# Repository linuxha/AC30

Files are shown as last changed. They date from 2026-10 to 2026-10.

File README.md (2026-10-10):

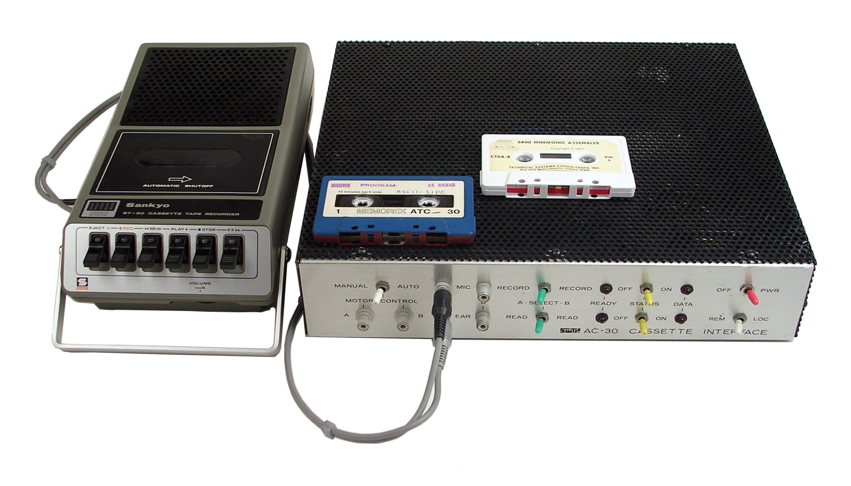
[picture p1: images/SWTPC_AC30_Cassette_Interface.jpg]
SWTPC AC30 Cassette Interface


# SWTPC AC30 Reproduction
A reproduction SWTPC AC-30 Cassette Interface

## Description

I have a couple of Motorola MC6800, MC6802, and MC6809 machines from the 1970's. And I wanted to
setup a typical cassette plater/recorder setup to save and load code written on these machines.

**Note:**2026/10/10 - Both boards (through-hole `kicad/AC30` and SMT `kicad-smt/AC30_SMT`) now wire the front panel (switches, LEDs, motor jacks, MIC A/B and EAR A/B jacks) to labelled through-hole wire pads instead of the J1/J2 Molex connectors. Board details are in [AC30-settings.md](AC30-settings.md) and [AC30-SMT-settings.md](AC30-SMT-settings.md); the parts list is [docs/AC30-BOM.md](docs/AC30-BOM.md), with KiCad BOMs in `kicad/AC30-BOM.csv` and `kicad-smt/AC30_SMT-BOM.csv`.

Board sizes are now 173.0 x 126.5 mm (6.8" x 5.0") through-hole and 173.0 x 88.5 mm (6.8" x 3.5") SMT. Gerbers and drill files for both boards are ready for the board house: [kicad/AC30-gerbers.zip](kicad/AC30-gerbers.zip) (through-hole) and [kicad-smt/AC30_SMT-gerbers.zip](kicad-smt/AC30_SMT-gerbers.zip) (SMT, including the top paste layer for a stencil). `kicad/tools/build.sh` regenerates them on every build, or run `kicad/tools/gerbers.sh` (add `smt` for the SMT board).

The SMT board also has a pick-and-place position file, [kicad-smt/AC30_SMT-top-pos.csv](kicad-smt/AC30_SMT-top-pos.csv) (SMD parts only, mm, origin at the board's bottom-left corner), to go with the BOM for an assembly house. The through-hole board's layout was re-placed so a fresh build routes completely again; the build now tries other placements automatically if routing ever comes up short. Both boards now have a GND copper fill on both layers (thermal reliefs on the GND pads, so they're still easy to hand-solder; details in the settings files above), added automatically by the build after routing. The motor and relay lines (MOTOR_1A/1B/2A/2B, RELAY_1/2) now use the same 0.6 mm tracks as the power rails, good for roughly 1.5 A. Known issues, including what to check before ordering boards, are listed in [KNOWN-ISSUES.md](KNOWN-ISSUES.md).

2026/10/09 - I've update the PCB to add the mod/demod circuits and a molex for the power. Additionally I had a new SMT version created.

2026/10/08 - This is my first go around with Claude, Kicad and FreeCAD and creating a PCB to be sent off as gerbers. I have a lot of inspecting to do. But for a 1st go this is scary impressive.

## Claude created Kicad files

I gave Claude the following prompts:

```text
Create a kicad schematic for docs/AC30-BOM.md docs/ac30_schematica.jpg
```

and

```text
Save what you have but provide solder pads and labels for the missing power and mod/demod
```

and

```text
Now create the pcb from the schematics. Minimize the board size but leave a safe boarder along the edge.
```

After this I use a few suggested prompts.

Here's what the inside of the Original SWTPC AC30:

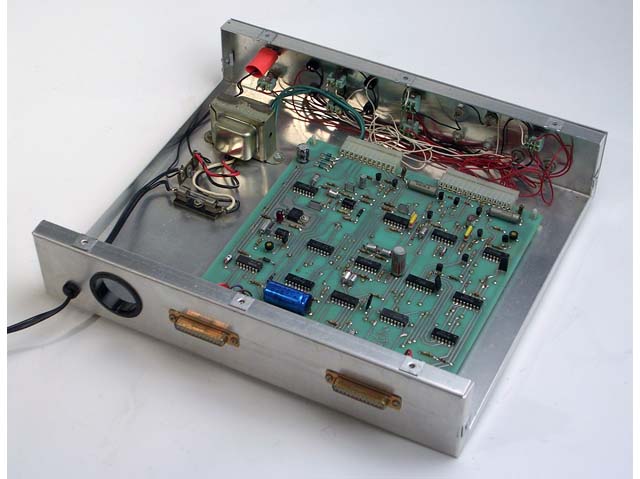
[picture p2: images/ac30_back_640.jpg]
SWTPC AC30 Cassette Interface insides


I'd estimate the board to be about 9" x 9" (inches) in size. Here's the schematics I gave Claude:

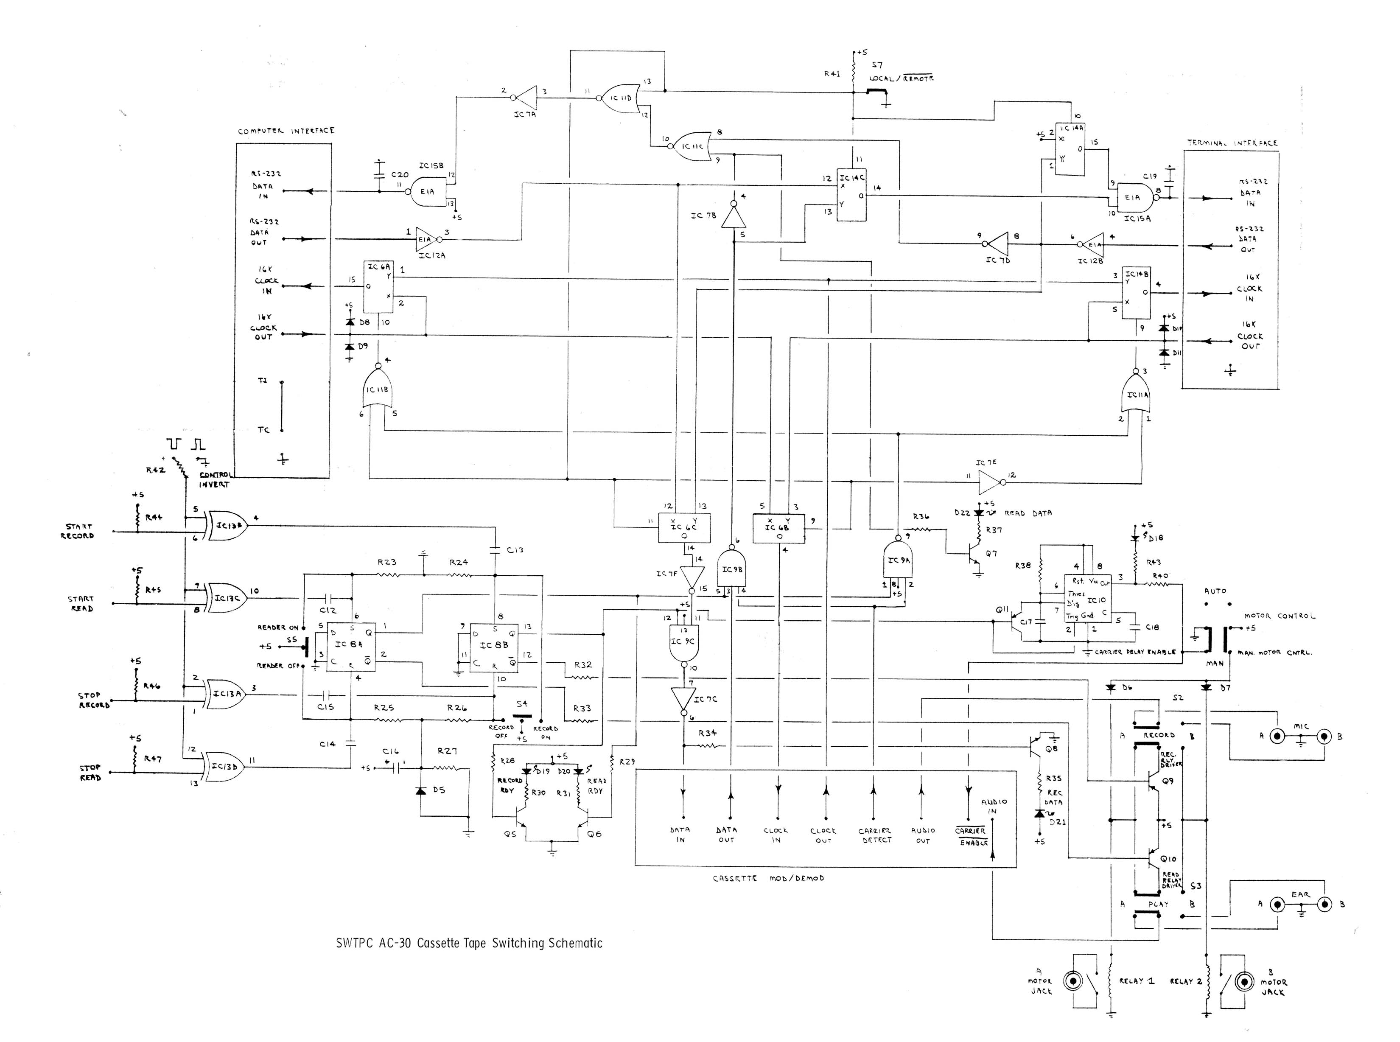
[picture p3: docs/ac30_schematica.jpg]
SWTPC AC30 Cassette Interface schematic


I gave it the [AC30/docs/AC30-BOM.md](BOM) file (simple markdown text file).

Claude started churning and created a 'schematic' (doesn't look like the above, hard to read) and I imported it into the PCB editor. Then didn't make any changes. Instead I let Claude do the rerouting.

I then found out I needed to upgrade Kicad to 10.7 and FreeCAD 26.3 so Claude could create Python 3.11 scripts to build a schematic, the PCB and routing. That was messy as I have Debian Trixie and the latest wants Debian Forky. Anyway, this is the final 1st round attempt. More cleanup to do yet before I ship off the gerbers.

I'd estimate the size of the new PCB to be about 3.5" x 7" (inches).

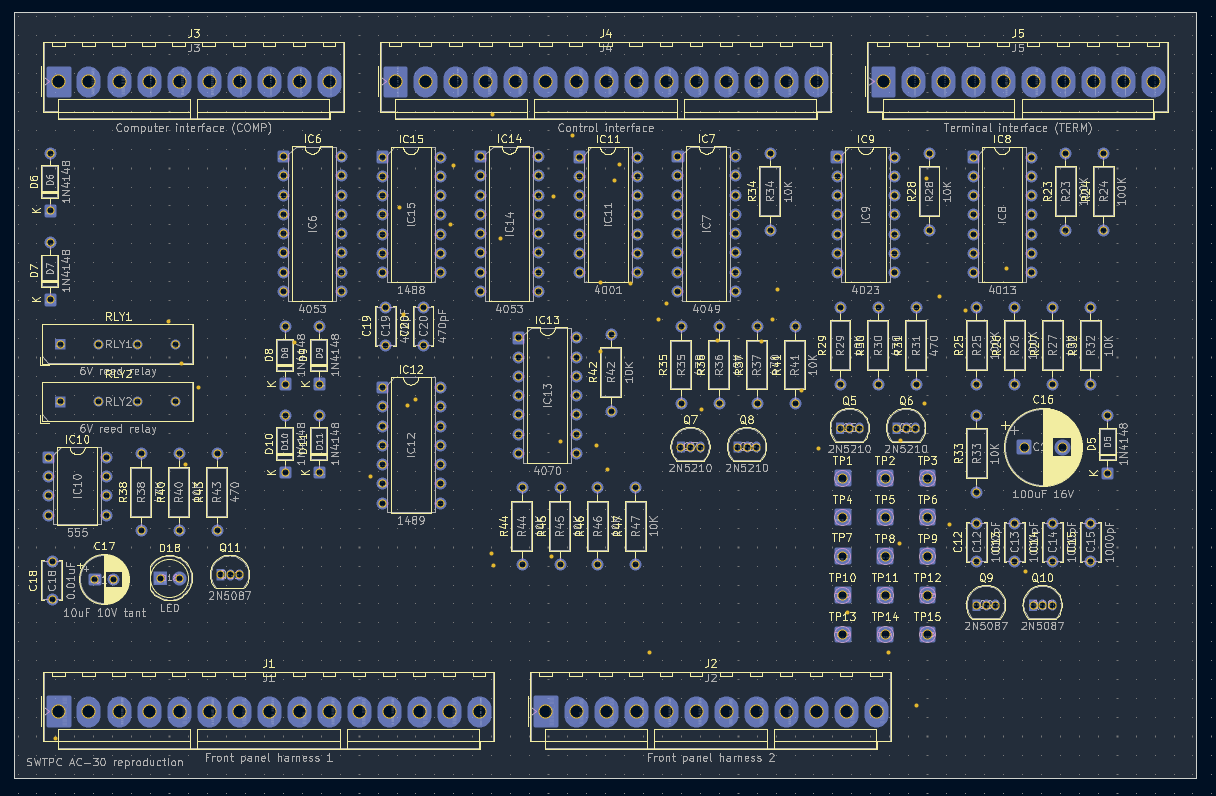
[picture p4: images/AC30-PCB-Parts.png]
New AC30 Cassette Interface part placement


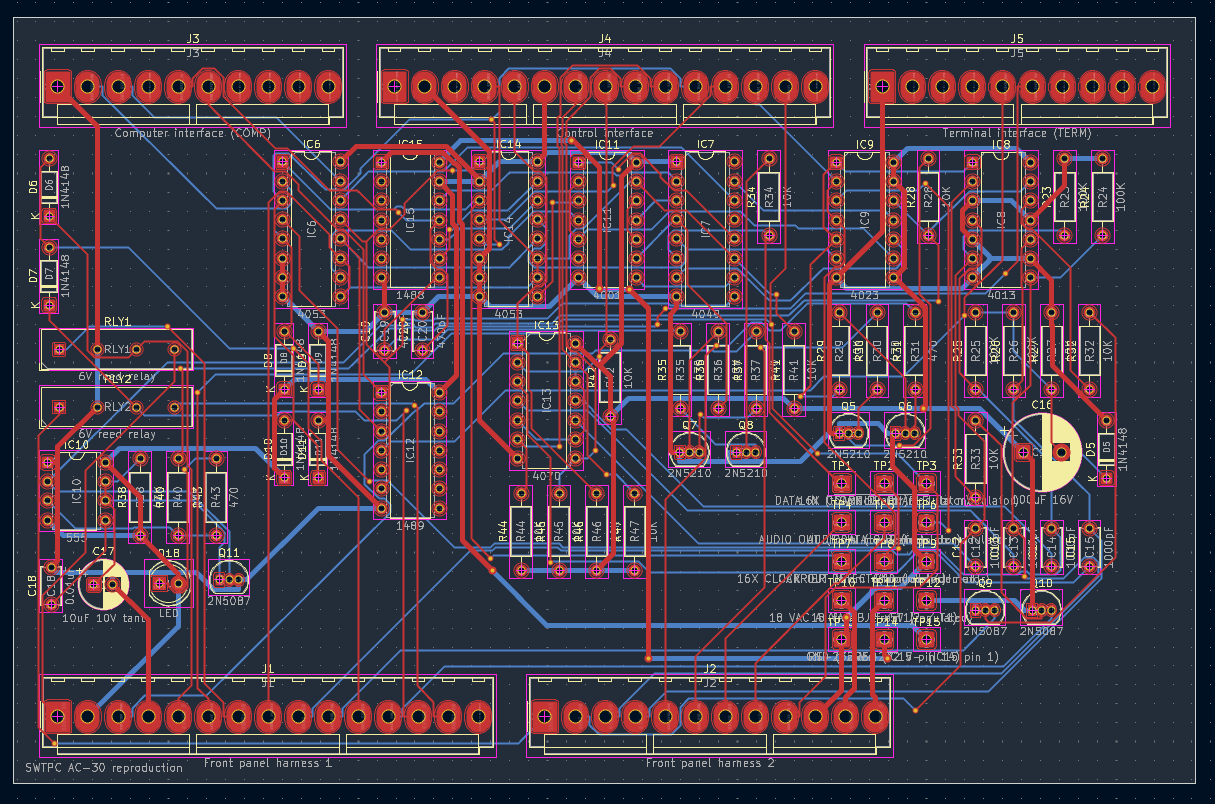
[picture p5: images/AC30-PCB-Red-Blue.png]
New AC30 Cassette Interface Red/Blue


So after several hours, including the Kicad/FreeCAD SNAFU, those are the results. The TPx are where I just dumped a bunch of jumpers I hadn't decided on. I'll fix those later. While it's not done it's a huge jump. It would have taken me about two weeks to get all the parts on the schematic, connections defined and PCB routed.

## Credits

I stole this from [Deramp's AC30 (Mike)](https://www.swtpc.com/mholley/ac30/ac30_index.html) site.
And he saved it from Mike Holley's original SWTPC site.

## Links

- [Deramp's AC30 page](https://www.swtpc.com/mholley/ac30/ac30_index.html)

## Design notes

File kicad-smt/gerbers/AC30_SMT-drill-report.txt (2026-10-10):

Drill report for AC30_SMT.kicad_pcb
Created on 2026-10-10T07:04:19

Copper Layer Stackup:
    =============================================================
    L1 :  F.Cu                      front
    L2 :  B.Cu                      back

Drill file 'AC30_SMT-PTH.drl' contains
    plated through holes:
    =============================================================
    T1  0.400mm  0.0157"  (252 holes))
    T2  0.500mm  0.0197"  (28 holes))
    T3  1.000mm  0.0394"  (36 holes))
    T4  1.700mm  0.0669"  (41 holes))

    Total plated holes count 357

Drill file 'AC30_SMT-NPTH.drl' contains
    unplated through holes:
    =============================================================
    T1  3.200mm  0.1260"  (4 holes))

    Total unplated holes count 4

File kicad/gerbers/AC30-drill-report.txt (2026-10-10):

Drill report for AC30.kicad_pcb
Created on 2026-10-10T07:02:01

Copper Layer Stackup:
    =============================================================
    L1 :  F.Cu                      front
    L2 :  B.Cu                      back

Drill file 'AC30-PTH.drl' contains
    plated through holes:
    =============================================================
    T1  0.400mm  0.0157"  (82 holes))
    T2  0.500mm  0.0197"  (7 holes))
    T3  0.700mm  0.0276"  (8 holes))
    T4  0.750mm  0.0295"  (33 holes))
    T5  0.800mm  0.0315"  (363 holes))
    T6  0.900mm  0.0354"  (2 holes))
    T7  1.000mm  0.0394"  (38 holes))
    T8  1.700mm  0.0669"  (41 holes))

    Total plated holes count 574

Drill file 'AC30-NPTH.drl' contains
    unplated through holes:
    =============================================================
    T1  3.200mm  0.1260"  (4 holes))

    Total unplated holes count 4

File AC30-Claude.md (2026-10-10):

# AC-30 KiCad Schematic: Claude Code Session Log

Session dates: 2026-10-08 to 2026-10-10 (sections 1–16 on the 8th, 17–42 on the 9th, 43–70 on the 10th). Model: Claude Opus 5.5 (Claude Code CLI).

This is a record of the chat that produced the KiCad project in `kicad/`. User messages are reproduced exactly, typos included. Claude's answers are in full for sections 1–3 and condensed from section 4 on. Claude's intermediate tool work (shell commands, image crops, file edits) is summarized rather than shown verbatim.

---

## 1. User

> Create a kicad schematic for docs/AC30-BOM.md docs/ac30_schematica.jpg

### Work done (summary)

1. **Read the inputs.** Claude read `docs/AC30-BOM.md`, the "How It Works" section of `docs/AC30-AssemblyInstruction.md` and `docs/ac30_schematica.jpg` (3300×2456). The image is titled *SWTPC AC-30 Cassette Tape Switching Schematic* and shows only the switching circuitry. The modulator/demodulator appears only as a block, and the power supply is not drawn.
2. **Traced the drawing.** Claude cropped and zoomed about 25 regions of the image with ImageMagick and traced every net by hand. It treated gaps in a line as crossings and dots as junctions. Gate pin numbers were checked against the real CMOS pinouts (4001, 4013, 4023, 4049, 4053, 4070, 555, 1488, 1489).
3. **Read the board connectors.** From `docs/ac30_wiring1a.jpg`, Claude took the signal order of board connectors J1–J5 and the front-panel parts (S1–S7, D19–D22, jacks J6–J11).
4. **Wrote a generator.** The tooling lives in `kicad/tools/`:
   - `sexp.py`: a minimal S-expression parser/writer.
   - `kilib.py`: loads stock KiCad library symbols, flattens `extends`, and reports pins and body bounding boxes.
   - `customlib.py`: writes `AC30.kicad_sym` with the MC1488, MC1489 and SPST reed relay symbols, which are missing from the stock libraries.
   - `netlist.py`: the hand-transcribed netlist. Each part has its value, footprint and a per-unit pin→net map.
   - `gen.py`: places each unit in grouped rows. Every pin gets a short wire stub ending in a net label, a power symbol or a no-connect flag. It writes the root and sub sheets, `sym-lib-table` and `AC30.kicad_pro`.
5. **Verified the result.**
   - `kicad-cli sch upgrade` converted the files to the KiCad 10 format.
   - `kicad-cli sch erc` was run on the result.
   - A netlist exported with `kicad-cli sch export netlist` was compared pin for pin against `netlist.py`. This caught one real error: the drawing labels IC13C's inputs as 7/8, but 4070 pin 7 is VSS. It was fixed to 8/9.
   - A PDF render was inspected, and the Ref/Value field placement and power-symbol text collisions were fixed.
   - A check confirmed that every BOM designator appears exactly once.

### Claude's answer

I've created a KiCad 10 project in `kicad/`. One big caveat first: the image only contains the **switching** circuit, so that's the only part that's actually wired. The modulator/demodulator and power supply aren't drawn anywhere in `docs/`, so those parts are placed but have no connections.

**What's in it**
- **`AC30.kicad_sch` (sheet 1, A1): the switching circuit, fully wired.** It covers IC6–IC15, Q5–Q11, the latches, power-on reset, LED and relay drivers, the 555 carrier-enable delay, the RS-232 parts and the front-panel switches, LEDs and jacks.
- **Board connectors J1–J5.** I took their signal lists from `docs/ac30_wiring1a.jpg`.
- **`AC30_moddemod_power.kicad_sch` (sheet 2): the rest of the BOM, unwired.** That's IC1–IC5, IC16, R1–R22, C1–C11, T1, F1 and so on. The only connections are the obvious ones: CMOS supply pins and the 7805 output. A note on the sheet summarizes the theory-of-operation text to help with wiring it later.
- **`AC30.kicad_sym`:** custom symbols for the MC1488, MC1489 and the reed relay, which aren't in the stock KiCad libraries.
- **`tools/`:** the generator scripts. The transcribed netlist is in `tools/netlist.py`, and `python3 -I tools/gen.py .` rebuilds the files.

**Layout:** this is not a redraw of the original drawing. Each pin has a short wire ending in a net label, and parts are grouped by function. Connections are exact, but you read it like a netlist rather than tracing wires.

**Checks I ran**
- Every BOM designator appears exactly once. J1–J11 are extra, since they're on the drawings but not in the BOM.
- The netlist exported from KiCad matches my transcription pin for pin.
- ERC shows no problems on sheet 1 except nets that lead to the unwired sheet 2. Sheet 2 reports about 180 unconnected pins, which is expected.
- It opens and plots in KiCad 10.0.4.

**Things to check, since I read them off a scanned drawing (also noted on the sheet):**
- **Two pin-number errors on the drawing.** I corrected them to the real chip pinouts:
  - IC7D is labelled 8→9; on a 4049 that section is 9→10.
  - IC13C's inputs are labelled 7 and 8; on a 4070 they're 8 and 9, and pin 7 is ground.
- **Assumed, not shown on the drawing:**
  - The 4053 INH and VEE pins are tied to ground.
  - The 555's pins 4 and 8 go to +5V.
  - The 1488's supply pins are brought out as `V_RS232+` and `V_RS232-`, with the source unknown.
- **Pin numbers on J1–J5** follow the order on the wiring diagram and haven't been checked against a real board.
- **MIC/EAR jacks:** I assigned J6–J9 arbitrarily; J10 and J11 are the motor jacks.
- **Switch S6** isn't on the switching schematic, so I left it unwired on sheet 2.
- **R39 (200K trim)** isn't on the drawing either; it may belong in the 555 timing circuit. It's on sheet 2 for now.

Nothing is committed yet. If you can find the mod/demod and power supply schematic, I can wire sheet 2 the same way.

---

## 2. User

> Save what you have but provide solder pads and labels for the missing power and mod/demod

### Work done (summary)

1. **Saved the current state.** Claude created branch `kicad-schematic` and committed the project as it stood (`5476760`).
2. **Replaced the unwired parts with pads.** In `netlist.py`, the unwired mod/demod and power BOM parts were moved to sheet `'omitted'`, so they are kept for reference but not placed. Fifteen `Connector:TestPoint` solder pads (TP1–TP15) were added on sheet 2, using footprint `Connector_Wire:SolderWire-0.5sqmm_1x01_D0.9mm_OD2.1mm`.
3. **Fixed power flags.** PWR_FLAGs went on +5V, GND, V_RS232+ and V_RS232−, because the supplies now enter through pads.
4. **Verified and committed.** ERC exited with 0 violations. Claude regenerated, rendered and checked sheet 2, then committed (`ab95554`).

### Claude's answer

Both changes are committed on a new branch, `kicad-schematic`. I branched instead of committing to `main`, and nothing is pushed. Your edit to `README.md` is still uncommitted.

**Commits**
1. `5476760`: the schematic as it was, with the mod/demod and power parts placed but unwired.
2. `ab95554`: sheet 2 is now **Mod/Demod & Power pads**. Each signal or supply that crosses into the missing circuits goes to its own labelled solder pad, using a 0.9 mm drill / 2.1 mm wire pad footprint:

| Pad | Net | Direction |
|---|---|---|
| TP1 | DATA_IN | to modulator |
| TP2 | CLOCK_IN (16X) | to modulator |
| TP3 | CARRIER_EN_N | to modulator |
| TP4 | AUDIO_OUT | from modulator |
| TP5 | AUDIO_IN | to demodulator |
| TP6 | DATA_OUT | from demodulator |
| TP7 | CLOCK_OUT (16X) | from demodulator |
| TP8 | CARRIER_DETECT | from demodulator |
| TP9 | GND | mod/demod ground |
| TP10, TP11 | 18VAC_A, 18VAC_B | from J2 / T1 |
| TP12 | +5V | regulated supply in |
| TP13 | GND | power ground |
| TP14, TP15 | V_RS232+, V_RS232− | 1488 supply rails (pins 14 and 1) |

**Other changes**
- **Mod/demod and power BOM parts:** IC1–IC5, IC16, R1–R22, T1, F1 and the rest are no longer on the schematic. Unwired parts would just turn into dead footprints on a PCB. They're still listed in `kicad/tools/netlist.py`; changing `S = 'omitted'` back to `'moddemod'` there and rerunning `gen.py` places them again.
- **Unknown parts:** S6 and R39 went off the schematic with that group, since their function wasn't shown.
- **ERC is now completely clean.** It reports no violations, including none for unconnected pins. Since nothing on the board drives +5V, GND or the RS-232 rails any more, I added PWR_FLAGs to those nets.

The open questions from last time haven't changed:
- the J1–J5 pin order
- which of J6–J9 is which MIC/EAR jack
- the two pin-number slips I corrected on the original drawing (IC7D and IC13C)
- the 1488's supply voltages

---

## 3. User

> Save this entire chat to AC30-Claude.md

### Claude's answer

Saved to `AC30-Claude.md` in the repository root (this file).

---

## 4. User

> Now create the pcb from the schematics. Minimize the board size but leave a safe boarder along the edge.

### Work done (summary)

1. **Writing the board file directly.** The `pcbnew` Python module on the system was broken: SWIG type errors, then a segfault. Claude wrote `kicad/tools/pcb.py`, which builds `AC30.kicad_pcb` straight from KiCad's exported netlist as S-expression text. Each footprint carries `path`/`sheetname`/`sheetfile`, so the schematic–PCB parity check passes.
2. **Placement.**
   - Each discrete part joins the IC it shares the most signal nets with, and parts stand upright to save area.
   - Each cluster picks the internal width that gives it the smallest area.
   - Clusters are packed with a skyline packer, trying several block orders.
   - J3–J5 run along the top edge and J1/J2 along the bottom.
3. **Outline and rules.** The outline is a rectangle with a **3 mm border** around the outermost courtyards, snapped to 0.5 mm. A Power net class was set: 0.6 mm tracks for +5V, GND and the supply nets, against 0.25 mm and 0.2 mm clearance for the Default class. Copper-to-edge clearance is 0.5 mm.
4. **Routing question.** The FreeRouting jar already on the machine is an old GUI-only build. Claude asked how to route. The user chose **"Leave unrouted for now"**.

### Claude's answer (condensed)

The board was placed and outlined at **115.5 × 122 mm** with 80 footprints, but not routed. DRC showed no placement errors and 0 parity issues; the only items flagged were 212 unrouted connections. Nothing was committed. Claude also noted that this overwrote the raw-import board the user had committed in `60d7180`, and gave the command to restore it.

---

## 5. User

> Make J3, J4 and J5 match the original artwork

### Work done (summary)

Claude read the connector labels on `docs/ac30_redblue150.jpg`, the original board artwork, top view:
- J3 (COMP) and J5 (TERM) are 10-position headers and J4 is a 15-position header, Molex KK-396 at 3.96 mm pitch.
- Each signal was moved to its pad position on the artwork, with unused positions marked no-connect.

### Claude's answer (condensed)

- **J3:** 1 GND, 2 computer 16X clock out, 3 computer 16X clock in, 5 RS-232 in, 6 RS-232 out.
- **J4:** 2 GND, 4 LOCAL/REMOTE, 5 STOP RECORD, 6 +5, 7 STOP READ, 8 CONTROL INVERT, 9 START READ, 10 START RECORD, 11 terminal 16X clock out, 12 terminal clock in, 13 CARRIER DETECT, 14 CARRIER DELAY ENABLE.
- **J5:** 1 GND, 5 terminal RS-232 out, 6 terminal RS-232 in.

The wider top row reflowed the board to **156 × 98 mm**. ERC and parity were clean, and the board was still unrouted.

---

## 6. User

> Check J1 and J2 against the artwork too

### Claude's answer (condensed)

J2's 12 positions already matched the artwork. J1 has **15 pads** on the artwork, and only the first 14 are labelled, in the same order as the schematic. J1 became a 1×15 header with pin 15 unused.

During this check Claude found that `kicad 9.0.2` had been installed in place of 10.0.4 during the session. KiCad 9 had no global symbol library table, so ERC produced 206 "library not found" warnings. With a temporary library config, ERC was clean.

---

## 7. User

> Use /home/njc/bin/FreeCAD_26.3rc1-Linux-aarch64.AppImage and /home/njc/bin/kicad.AppImage instead

### Work done (summary)

- **FreeCAD:** the FreeCAD AppImage is an **aarch64** build and the machine is x86_64, so it can't run.
- **KiCad:** the KiCad AppImage is **10.0.7**. Its `AppRun` passes a tool name through, so `kicad.AppImage kicad-cli …` works, and the image bundles its own libraries.
- **Library layout:** KiCad 10 stores each stock symbol library as a `.kicad_symdir` folder, one file per symbol. Claude taught `kilib.py` to read that layout and made the library paths overridable (`KICAD_SYMBOL_DIR`, `KICAD_FOOTPRINT_DIR`).
- **New `tools/build.sh`:** mounts the AppImage for the whole run, so the generators read its KiCad 10 libraries. It runs `kicad-cli` with a private config pointing at the AppImage's own library tables. It then regenerates the schematic and board and runs ERC and DRC with the parity check.
- **Sub-sheet format:** `sch upgrade` only rewrites the root sheet, so the sub-sheet is now upgraded explicitly too.

### Claude's answer (condensed)

The project builds and checks with KiCad 10.0.7, and the files are back in KiCad 10 format. ERC was clean, and DRC showed 0 violations and 0 parity issues besides the 212 unrouted connections. Claude noted that the user's `~/.config/kicad/10.0` tables now point at the Debian 9 template, so the KiCad 10 GUI would not find the stock symbols. The config was left unchanged.

---

## 8. User

> Use /home/njc/bin/FreeCAD_26.3rc1-Linux-x86_64.AppImag

### Claude's answer (condensed)

The path was missing its final "e". The x86_64 AppImage wasn't executable, so Claude ran `chmod +x` on it. It reports **FreeCAD 26.3.0** and runs headless as `freecadcmd`.

A STEP export from KiCad loaded cleanly in FreeCAD, with 136 solids. The PCB body measured **156.0 × 101.0 × 1.51 mm**, matching the outline. The KK-396 connectors and the solder-wire pads have no 3D models in the KiCad library.

---

## 9. User

> Add the STEP export and FreeCAD check to build.sh

### Claude's answer (condensed)

- `build.sh` now writes `kicad/AC30.step` and lists the parts with no 3D model.
- It then runs `tools/fc_check.py` in headless FreeCAD. The check confirms one assembly with a PCB body whose size matches the board outline, and fails the build if it doesn't.
- `freecadcmd` doesn't pass script arguments through or show printed output, so the script takes its input and output paths from environment variables.

---

## 10. User

> Add AC30.step to .gitignore and commit

### Claude's answer (condensed)

Claude created the root `.gitignore` and committed the PCB work as **`0bced8b`** on `kicad-schematic`. It left out KiCad's local `.history/` folder.

---

## 11. User

> Add .history to .gitignore too

### Claude's answer (condensed)

Claude added `.history/` to `.gitignore` and left the change uncommitted.

---

## 12. User

> Run ERC

### Claude's answer (condensed)

ERC with the KiCad 10.0.7 AppImage: **0 errors and 0 warnings** on both sheets. The four ignored checks listed in the report are KiCad's defaults.

---

## 13. User

> Run DRC

### Claude's answer (condensed)

DRC: **0 violations and 0 parity issues**. The 212 unrouted connections remained.

---

## 14. User

> Do routing

### Work done (summary)

1. **Getting a working router.**
   - FreeRouting 2.5.0 and 2.4.1 both need Java 25, and the machine has Java 22. Claude deleted the jars it had downloaded.
   - **FreeRouting 2.1.0** (April 2025, Java 21) went to `~/bin`. It routes headless (`-de … -do … -mp 100 --gui.enabled=false`).
   - The KiCad AppImage's bundled Python 3.11 has a working `pcbnew`, which does the Specctra DSN export and SES import.
2. **Layer fix.** The PCB header copied from the KiCad demo marked F.Cu as a *power* layer, which stopped FreeRouting from routing on it. Both copper layers became signal layers.
3. **Placement fix.** On the first route, three nets could not be completed: C12–C15 sat about 110 mm from IC13. Claude made the skyline packer **wirelength-aware**:
   - each block goes to the column that minimizes height plus the wire it adds;
   - 300 random block orders are tried;
   - the score weighs 25 mm of wire against 1 mm of board height.
   The board grew to 156 × 101 mm, and the estimated signal wire fell by about 16%.
4. **New `tools/route.py`.**
   - It exports the DSN, runs FreeRouting and imports the SES.
   - It removes the duplicate and dead-end stubs FreeRouting leaves behind; those had caused "track has unconnected end" warnings.
   - It repeats while anything is unrouted.
   - `build.sh` runs it after placement; `ROUTE=0` skips routing.
5. **Build-script fix.** The exit trap failed under `set -e` when the AppImage mount had already gone; Claude fixed it.

### Claude's answer (condensed)

**Fully routed: 0 unrouted connections, 0 DRC violations and 0 parity issues.** The routing had 1,085 segments and 50 vias, with 0.6 mm tracks on the power nets. Routing changes on every build. Nothing was committed.

---

## 15. User

> Create an AC30-settings.md file with all the settings, drill bits, trace minimus, measurements, etc.

### Claude's answer (condensed)

Claude created `AC30-settings.md`, with every value read from the board using KiCad's own tools. It covers:
- board size and stackup;
- DRC rules in mm and mils;
- net classes;
- a drill table: each hole size with its inch and number-drill equivalents, hole counts, and which parts use it;
- annular rings;
- routing figures;
- connector positions;
- a pin-1 placement table for every part;
- tool versions and generator settings.

It flagged that the board had no mounting holes and no ground fill.

---

## 16. User

> Add the four corner mounting holes to match the artwork

### Work done (summary)

1. **Measuring the artwork.** Claude used the 3.96 mm connector pitch as the scale (5.754 px/mm). It fitted each skewed edge of the board outline and measured each hole from its two nearest edges. The holes came out 5.7–6.5 mm in, averaging 6.2 mm, which points to a **¼ in (6.35 mm) inset**. The pads are about 4.6 mm across, which suits a ⅛ in / 3.2 mm hole.
2. **Adding the holes.**
   - H1–H4 went on the schematic as `Mechanical:MountingHole` symbols, excluded from the BOM, so parity stays clean.
   - They use the 3.2 mm unplated M3 footprint.
   - `pcb.py` places them 6.35 mm in from each corner of the final outline.
   - The connector rows are moved in to clear the holes.

### Claude's answer (condensed)

The holes were placed exactly 6.35 mm in from each edge, and the board became **173.0 × 97.5 mm**. It was routed with ERC, DRC and parity clean, and `AC30-settings.md` gained a Mounting holes section.

---

## 17. User

> Update kicad with @docs/ac30_mod_demod.pdf

### Work done (summary)

1. **Reading the scan.** The PDF is a single scanned page, white on black and rotated. Claude extracted it, inverted and rotated it, and traced every net at full resolution. Gaps in a line are crossings, as on the switching drawing.
2. **Wiring sheet 2.**
   - **Modulator:** IC5B divides CLOCK IN by 2 and clocks IC5A, which divides by 1 or 2 under DATA IN, through IC2A and C1/R1. IC4A with R2, R3, C2 and C3 is a 2-pole filter, feeding the R6/R7 divider and C4 to AUDIO OUT.
   - **Demodulator:**
     - IC4B is a comparator with R10 hysteresis, D1/D2 input clamps and a D3 4.7 V clamp;
     - IC3C/D generate a pulse on each edge;
     - carrier detect is D4, C7, Q3, IC3A and the IC2B/Q2 missing-pulse detector;
     - the 1200 Hz timer is Q1, C8 and R16;
     - IC1A gives DATA OUT, and IC2D/IC3B/Q4 give the 16X CLOCK OUT.
3. **Interface.** The interface nets now join the switching circuit directly, and the nine mod/demod solder pads were removed.
4. **Placement fix.** The first route left one 18 VAC connection unrouted. The placer now weighs every net except +5V and GND.
5. **Build fix.** A stale AppImage mount from an earlier check made a new mount exit immediately. `build.sh` now tolerates an existing mount.

### Claude's answer (condensed)

All 436 board pins matched the transcription. The board became **173.0 × 121.5 mm**, fully routed with ERC, DRC and parity clean.

Assumptions:
- IC4 runs from the ±7.5 V zener rails, per the assembly manual.
- R16's unlabelled far end is +5 V.
- IC1B's unused inputs are tied to GND.
- The manual's "IC2A" pulse inverter is IC2C on the schematic.

---

## 18. User

> Update kicad and pcb with an external power supply from @docs/ac_PS.pdf. Provide through hole pads for the power.

### Work done (summary)

1. **Transcription.** The file is `docs/ac30_PS.pdf`, with outputs **+5, +13, +7.5, −13, −7.5 VDC and GND**.
   - 120 VAC goes through S6 and F1 to T1's two 120 V primaries, which are wired in parallel.
   - The 18 VAC centre-tapped secondary, tap to GND, feeds the D14–D17 bridge, giving +13 V on C21 and −13 V on C22.
   - R48/D12 and R49/D13 make ±7.5 V, and IC16 (7805) makes +5 V.
2. **Drafting error corrected.** The drawing joins IC16's GND and C23–C25 return line to the bridge's −13 V corner, through two crossings. That would make the 7805 put out about −8 V, so it was taken as GND.
3. **Sheet 3, "Power supply (external)".**
   - Its parts have **no footprints**: they're in the schematic and BOM but not on the PCB.
   - `gen.py` was generalized to write any number of sub-sheets and set the project's sheet list.
   - PWR_FLAGs went on GND, the ±13 V and ±7.5 V rails, and the mains L line. The plug's L pin is a power input.
4. **Board side.**
   - Six through-hole pads (TP1–TP6: +5V, GND, +13V, −13V, +7.5V, −7.5V).
   - C23–C25 stay on the board as +5 V bypass, as on the artwork.
   - IC4 moved to ±7.5 V, and IC15 (1488) went on ±13 V, the only load left for those outputs.
   - J2's 18 VAC pins became unused.
5. **Verification.** KiCad's XML netlist, which includes parts that aren't on the board, matched the transcription on all 518 pins.

---

## 19. User

> ave you updated the PCB with everything to this point?

### Claude's answer (condensed)

Not yet. The schematic and placement were done, but the routed build was still running. The settings document still described the earlier board.

---

## 20. User

> ok, finish it and then commit

### Work done (summary)

1. **A short in the routing.** The routed build finished with 0 unrouted, but its later rounds had added 4 clearance violations and a **short (TERM_CLK_OUT/TERM_ECHO)**. FreeRouting re-routing on top of its own tracks causes these.
2. **Retrying from scratch.** `build.sh` now routes the placed board from scratch up to 4 times, one round each, and keeps the first result whose KiCad DRC is completely clean. Otherwise it keeps the fewest-items result and warns.
3. **Pad labels.**
   - The TP pads show their rail name on the silkscreen.
   - The labels first overlapped the next pad's reference text, causing 4 `silk_overlap` warnings. The pad references were moved to the fab layer in `pcb.py`.
   - The same edit was applied to the routed board, rather than re-routing for 40 minutes.
4. **Commit.** `AC30-settings.md` was updated with a Power input section. Claude committed **`2b26e99`** on a new branch, `kicad-moddemod-psu`, since the repo was on `main`.

### Claude's answer (condensed)

The board was 173.0 × 121.5 mm, fully routed, with ERC, DRC (all severities) and parity clean. The user's README and BOM edits were left uncommitted. The KiCad GUI had the project open, so Claude warned against saving from it before reloading.

---

## 21. User

> Check your current task stack or running bash commands and report whether anything is deadlocked or waiting for input.

### Claude's answer (condensed)

Nothing was waiting for input, but two of Claude's background "wait for the build" loops were stuck. They used `until ! pgrep -f "tools/build.sh"`, and that pattern also matched the loop's own command line, so they could never end. Claude stopped both, and no processes were left running. The loops had never touched any files.

---

## 22. User

> merge it into main

### Claude's answer (condensed)

KiCad had re-saved `AC30.kicad_pro` after the commit; the re-save only reorders keys. Claude stashed that file, fast-forwarded `main` to `2b26e99`, and restored the re-save unchanged.

---

## 23. User

> push it

### Claude's answer (condensed)

Pushed `main` to `github.com:linuxha/AC30` (`e8dbe58..2b26e99`).

---

## 24. User

> Has the mod demod and power supply connectors been added to the PCB. I don't see power connectors

### Claude's answer (condensed)

The mod/demod is built on the board, so it needs no connector. The power input was six small solder pads (TP1–TP6) in the middle-left of the board, which are easy to miss. Claude offered a 6-pin KK-396 header on the board edge, or a 5.08 mm screw terminal.

---

## 25. User

> Use a 6-pin KK-396 connector on the board edge

### Work done (summary)

**J12** (Molex KK-396 A-41791-0006) replaced TP1–TP6, in the bottom connector row next to J2 and clear of the corner hole. Its pinout is **1 GND, 2 +5V, 3 +13V, 4 −13V, 5 +7.5V, 6 −7.5V**, with GND on pin 1 as on J3 and J5. The KK housing is keyed. A placement-only build was clean.

---

## 26. User

> ok, finish it and then commit

## 27. User

> push it

### Work done (summary)

1. **Routing.** None of the 4 fresh attempts was clean; the best one left one connection unrouted (LED_READ_DATA, J1 pin 3 to R37).
2. **Finishing pass.** One that kept the existing tracks and routed only that connection gave a **completely clean DRC**. `build.sh` now runs up to 3 such finishing passes, each checked by DRC.
3. **Settings.** `AC30-settings.md` was updated:
   - the J12 pinout replaced the pad table;
   - the drill table went to 542 holes, with six more 1.7 mm holes and no 1.15 mm holes;
   - the routing figures and positions were refreshed.
4. **Commit and push.** Committed **`53b935b`** on `kicad-power-connector`, fast-forwarded `main`, and pushed (`2b26e99..53b935b`, including the user's own README commit `ae7fbe3`).

### Claude's answer (condensed)

The board is **173.5 × 122.0 mm** with 119 footprints, fully routed:

| Check | Result |
|---|---|
| ERC | 0 violations |
| Unrouted connections | 0 |
| DRC | 0 violations at every severity |
| Schematic parity | 0 issues |
| FreeCAD check | OK |

---

## 28. User

> delete the merged branches

### Claude's answer (condensed)

Deleted the local branches `kicad-moddemod-psu` and `kicad-power-connector` with `git branch -d`; both were already merged. Only `main` remains, matching `origin/main`.

---

## 29. User

> update AC30-Claude.md with this session

### Claude's answer

Added sections 4–29 to this file and brought the appendix up to date.

---

## 30. User

> push all

### Claude's answer (condensed)

Committed everything pending as **`f60d9e7`** and pushed (`53b935b..f60d9e7`):
- the session log (sections 4–29);
- the user's `docs/AC30-BOM.md` edits, plus the new `docs/AC30-BOM.csv` and `docs/AC30_byte.pdf`;
- `kicad/AC30.kicad_prl`, KiCad's change to which layers are visible;
- the `kicad/.history` pointer.

Claude flagged that `kicad/.history` was tracked as a nested repository (a gitlink) with no `.gitmodules`. GitHub stored only a pointer, so clones would get a broken, empty entry. Claude suggested untracking it.

---

## 31. User

> untrack .history and push

### Work done (summary)

1. **Untracking.** `git rm --cached kicad/.history` removed it from the index and left the files on disk. This became commit **`1f0a4a8`**, pushed.
2. **Missing `.gitignore`.** Git then listed `kicad/.history/` as untracked, because there was no root `.gitignore`. The commit where Claude had created one (section 10, `0bced8b`) was no longer in the history, probably after the history was reorganised, and the file was gone from disk.
3. **New `.gitignore`.** It covers only KiCad's local files: `.history/`, `~*.lck` lock files, `_autosave-*` and `*-backups/`. `kicad/AC30.step` is left out because the user tracks it on purpose. This became commit **`139522e`**, pushed.

### Claude's answer (condensed)

`main` and `origin/main` are at `139522e`, and the working tree is clean. Claude noted that the message on `1f0a4a8` wrongly says `.history` was "already in .gitignore"; it wasn't until `139522e`.

---

## 32. User

> update AC30-Claude.md with this session

### Claude's answer

Added sections 30–32 and updated the end-of-session table.

---

## 33. User

> Create a new Kicad schematic and PCB using SMT part except for the molex connectors. Keep the previous PCB and schematic

### Work done (summary)

1. **One set of tools, two variants.** Claude didn't copy the tools; it added a variant switch to them.
   - `AC30_VARIANT=smt` changes the footprints and the part values in `netlist.py`.
   - `AC30_PROJECT` sets the project and file names in `gen.py`.
   - `tools/build.sh smt` writes a separate project, **`kicad-smt/AC30_SMT.*`**.
   - Plain `tools/build.sh` still builds the through-hole project in `kicad/`. Regenerated into a scratch folder, its schematics matched the committed files apart from pin UUIDs that `kicad-cli` randomizes.
2. **SMT parts.**
   - 0805 resistors and capacitors, EIA-3216 tantalums for C4 and C17, and a 6.3 × 7.7 mm aluminium C16;
   - SOD-123 diodes (1N4148W, BZT52C4V7), and SOT-23 transistors (MMBT5088 for the 2N5210, MMBT5087), using KiCad's `Q_*_BEC` symbols to match SOT-23 pad order;
   - SOIC-8/14/16 ICs, a Bourns 3314G trimmer for R16 and a 1206 LED for D18.
   - The KiCad library has no SMD reed relay, so RLY1/RLY2 became **Omron G6K-2F-Y** (5 V coil, DPDT 1 A), with both poles in parallel as the motor contact. Coil is pins 1/8, COM 3/6, NO 4/5.
   - The Molex KK-396 connectors and the mounting holes stay through-hole.
3. **Placement.** The board came out at 173.0 × 83.5 mm. ERC and parity were clean, and all 522 pins matched.

### Claude's answer (condensed)

The SMT schematic and placement were done and checked, and routing was started. Claude flagged three things: MMBT5088 stands in for the 2N5210; the G6K coil polarity should be checked; and 1206 parts would be easier to hand-solder.

---

## 34. User

> ok, finish it and then commit

## 35. User

> ok, finish it and then commit

### Work done (summary)

1. **Routing failed.**
   - Every FreeRouting 2.1.0 attempt left 22–26 connections unrouted, and the build hit its time limit.
   - A 3 mm part gap (`PCB_GAP`, added to `build.sh`) still left 19.
2. **First suspect: the stub cleanup.** `route.py`'s cleanup deleted tracks that end partway along another track (T-junctions). It was rewritten to count any same-net copper contact. That turned out not to be the main cause.
3. **Root cause: FreeRouting 2.1.0.** Its log said **"0 incomplete"**, yet the session file it wrote had gaps. One missing TERM_RS232_OUT segment lay exactly on the line FreeRouting used for TERM_CLK_IN. A raw import, before any cleanup, already had 20 unrouted.
   - Turning the optimizer off (`-mt 0`) made it worse: 30 unrouted.
   - Protected finishing passes ran for 20 minutes without converging.
4. **Fix: FreeRouting 2.4.1.**
   - Its Linux bundle carries its own Java 25 runtime. It went to `~/bin/freerouting-2.4.1/`, with its checksum matching GitHub's.
   - On the same board it reported **1 unrouted**, and KiCad imported exactly that.
   - `route.py` runs its native launcher, and `build.sh` uses it by default.
   - 2.4.1 is deterministic, so `build.sh` stops retrying when two attempts give the same result.
5. **Last connection.** AUDIO_IN ran about 80 mm from J2 to R8/C5, because placement only weighed the top connector row. A **second placement pass** now fixes the bottom row (J1, J2, J12) at its provisional height, which pulls related parts towards it.
6. **Finishing rounds.** When a board already has tracks, `route.py` marks them protected in the DSN, and rejects a session that drops existing wiring.

### Claude's answer (condensed)

The SMT board is **173.0 × 82.0 mm** and was **fully routed on the first attempt**:

| Check | Result |
|---|---|
| ERC | 0 violations |
| DRC | 0 violations at every severity |
| Schematic parity | 0 issues |
| FreeCAD check | OK |

It has 1,710 segments, 288 vias and 416 SMD pads; the 68 connector pads are the only through-hole ones.

Committed as **`942a3f1`**, with the tool changes and sections 30–32 of this log. The through-hole project's files were unchanged, and `AC30_SMT.kicad_prl` was left uncommitted.

---

## 36. User

> push it

### Claude's answer (condensed)

Pushed `main` (`139522e..942a3f1`).

---

## 37. User

> update AC30-Claude.md with this session

### Claude's answer

Added sections 33–37 and updated the end-of-session table.

---

## 38. User

> Create an AC30-SMT-settings.md for the SMT board

### Claude's answer (condensed)

Wrote `AC30-SMT-settings.md` in the same layout as `AC30-settings.md`: board, design rules, drill table (360 holes, mostly vias), SMD pads by footprint, routing result, mounting holes, power input, connectors, SMT parts with their through-hole equivalents, placement (centre and pin 1 for every part) and tool settings. All values were read from the board with KiCad's Python module.

---

## 39. User

> push all

### Claude's answer (condensed)

Committed `994fc84` and pushed `main` (`000f242..994fc84`).

---

## 40. User

> Modify the PCB so that it uses through hole jumpers for: Switches, LEDs, Motor Jacks, Ear and Mic

### Work done (summary)

1. **Asked two questions.** Which board: **SMT board only** (the through-hole board then still matched the artwork). Pad style: **labelled pad groups**, 0.1 in through-hole pads with net names on the silkscreen.
2. **Netlist.** In the SMT variant the J1/J2 KK-396 harness headers were replaced by five `PinHeader_1x…_P2.54mm_Vertical` rows used as bare wire pads: J1 SWITCHES, J2 LEDS, J13 MOTOR, J14 MIC, J15 EAR.
3. **Placement (`pcb.py`).** The pad rows are turned 90° along the bottom edge, with the courtyard used for placement extended over the labels. The bottom row now shares a bottom line (`pack_bottom`). Each pad gets a board-level silkscreen label with its net name (the "/" of local nets stripped), and the row name is the footprint's Value on the silkscreen.
4. **Result.** 173.0 × 89.0 mm, fully routed on the first attempt, ERC/DRC/parity clean. `AC30-SMT-settings.md` and the SMT schematic note were updated.

---

## 41. User

> ok, finish it and then commit

### Claude's answer (condensed)

Committed `ad90087`. The user's `docs/AC30-BOM.md` edits and the BOM CSVs in `kicad-smt/` were left out.

---

## 42. User

> push it

### Claude's answer (condensed)

Pushed `main` (`e6db4e2..ad90087`).

---

## 43. User

> I only see 1 Mic and one Ear. There should be a Mic A & Mic B, and Ear A & Ear B

### Work done (summary)

Each jack now has its own tip and GND pads: J14 MIC = MIC_A, GND, MIC_B, GND; J15 EAR = EAR_A, GND, EAR_B, GND. The RECORD A/B (S2) and PLAY A/B (S3) audio poles wire to six new SWITCHES pads (AUDIO_OUT, MIC_A, MIC_B, AUDIO_IN, EAR_A, EAR_B), so every wire has its own pad and the board joins the MIC_x/EAR_x pads of the two rows. J1 SWITCHES grew to 19 pads. The SMT board became 173.0 × 88.5 mm, fully routed and clean.

---

## 44. User

> ok, finish it and then commit

### Claude's answer (condensed)

Committed `a90aefc`.

---

## 45. User

> Modify other Kicad PCB so that these use through hole jumpers: Switches, LEDs, Motor Jacks, Ear and Mic

### Work done (summary)

1. **Netlist.** The jumper pad rows became common to both variants; the artwork's J1/J2 pin map was removed from the netlist and the schematic notes.
2. **Board height.** At the default height weight (25) the through-hole placement put the bottom row at 148.5 mm: the search accepted a taller board to save wire. `build.sh` now sets `AC30_HEIGHT_W=60` for the through-hole build only, which gave 126.5 mm (the old 122 mm plus the labels). The SMT board was rebuilt too (schematic note changed) and came out identical apart from symbol IDs.
3. **Result.** Through-hole board 173.0 × 126.5 mm. Each of the four routing attempts left one connection; the first finishing pass completed it. ERC/DRC/parity clean, FreeCAD check OK. `AC30-settings.md` was updated throughout.

---

## 46. User

> ok, finish it and then commit

### Claude's answer (condensed)

Committed `6d04833`. The SMT project was open in KiCad (lock files), so the user was asked to reload it before saving.

---

## 47. User

> update all the documentation and BOM for both

### Work done (summary)

1. **KiCad BOMs.** `build.sh` now exports `<project>-BOM.csv` from each schematic on every build: `kicad/AC30-BOM.csv` and `kicad-smt/AC30_SMT-BOM.csv` (reference, value, footprint, quantity, and "Excluded from board" for front-panel and power-supply parts).
2. **Parts list.** `docs/AC30-BOM.md` keeps the original list and gains sections for the reproduction boards (KK-396 connectors, the wire pad rows, front-panel jacks, on-board C23–C25, mounting hardware), the SMT substitutions and the KiCad BOM files. `docs/AC30-BOM.csv` gained matching rows.
3. **README and this log** updated.

### Claude's answer (condensed)

Reported the changes, two typos in the original parts list ("S4, SS"; a 1N4148 count of 9 for ten diodes), and that the user's three old SMT BOM exports were stale.

---

## 48. User

> yes delete thos 3, finish it and then commit and push

### Claude's answer (condensed)

Deleted `kicad-smt/AC30_SMT.csv`, `AC30_SMT-B.csv` and `AC30_SMT-B2.csv` (untracked). Committed `971d1da` and pushed `main` (`ad90087..971d1da`), which also carried `a90aefc` and `6d04833`.

---

## 49. User

> fix the S4, S5 and diode count typos

### Claude's answer (condensed)

`docs/AC30-BOM.md`: "S4, SS" → "S4, S5". `docs/AC30-BOM.csv`: D1, D2, D4, D5–D11 quantity 9 → 10.

---

## 50. User

> commit and push

### Claude's answer (condensed)

Committed `933618e` and pushed `main` (`971d1da..933618e`).

---

## 51. User

> update AC30-Claude.md with this session, commit and push

### Claude's answer

Added sections 48–51, committed `2fc8ed8` and pushed (`933618e..2fc8ed8`).

---

## 52. User

> generate the gerbers for both boards, commit and push

### Work done (summary)

1. **New script `kicad/tools/gerbers.sh`** (`tools/gerbers.sh` or `tools/gerbers.sh smt`). It writes into `<project dir>/gerbers/`:
   - Gerbers for F.Cu, B.Cu, F/B.Mask, F/B.SilkS and Edge.Cuts (X2, Protel extensions, silkscreen with the solder mask subtracted), plus F.Paste on the SMT board, and the Gerber job file;
   - Excellon drill files in mm, PTH and NPTH separate, with PDF drill maps and a drill report.

   It then zips them as `<project>-gerbers.zip`.
2. **`build.sh`** runs it at the end of every build, so the fabrication files follow each rebuild.
3. **Checks.** The drill reports match the settings documents: through-hole 572 plated + 4 unplated holes, SMT 379 plated + 4 unplated. Both settings documents gained a "Fabrication files" section.

### Claude's answer (condensed)

Committed `b8497c1` and pushed (`2fc8ed8..b8497c1`). `kicad/AC30-gerbers.zip` (13 files) and `kicad-smt/AC30_SMT-gerbers.zip` (14 files) are ready for the board house. The Gerbers were not inspected in a viewer.

---

## 53. User

> update AC30-Claude.md with this session, commit and push

### Claude's answer

Added sections 52–53, committed `b03431c` and pushed (`b8497c1..b03431c`).

---

## 54. User

> update the README with this session, commit and push

### Claude's answer (condensed)

Added a paragraph to the README's 2026/10/10 note: board sizes (173.0 × 126.5 mm through-hole, 173.0 × 88.5 mm SMT), links to `kicad/AC30-gerbers.zip` and `kicad-smt/AC30_SMT-gerbers.zip`, and how to regenerate them. The user's own text was left as it was. Committed `e5a5d8f` and pushed (`b03431c..e5a5d8f`).

---

## 55. User

> update AC30-Claude.md with this session, commit and push

### Claude's answer

Added sections 54–55, committed `94baf42` and pushed (`e5a5d8f..94baf42`).

---

## 56. User

> generate the position files for the SMT board

### Work done (summary)

1. **Origin.** `pcb.py` sets the drill/place origin (`aux_axis_origin`) at the bottom-left corner of both boards, the usual pick-and-place origin.
2. **Position file.** `tools/gerbers.sh smt` writes `kicad-smt/AC30_SMT-top-pos.csv`: the 109 SMD parts, mm, top side, from the bottom-left corner with Y up (THT connectors and wire pads left out). Spot checks agree with the placement table in `AC30-SMT-settings.md`.
3. **Rebuild.** Both boards were rebuilt to carry the origin. The SMT board came out identical apart from the origin line.

---

## 57. User

> ok, finish it and then commit and push

### Work done (summary)

The through-hole rebuild left one connection unrouted: all three finishing passes were rejected. Rather than commit that, the previous fully routed through-hole board was restored with only the origin line added (DRC and parity clean), and its Gerbers were regenerated. Both settings documents describe the position file and origin.

### Claude's answer (condensed)

Committed `97f89f4` and pushed (`94baf42..97f89f4`), noting that a fresh through-hole build would no longer route completely.

---

## 58. User

> Describe all known problems

### Claude's answer (condensed)

A list of 27 known problems, most important first:
- **Build:** a fresh through-hole build left one connection unrouted, and the early stop for repeated routing results never fired.
- **Transcription assumptions** to check against the originals: IC16 ground, the IC15 and IC4 supplies, R16, IC10 pins 4/8, the 4053 INH/VEE pins, IC1B.
- **Omissions:** R39 is on no schematic and isn't placed.
- **SMT substitutions:** the relay coil and polarity, MMBT5088 for the 2N5210, the tantalum voltage margins, position-file rotation offsets.
- **PCB:** no ground plane, 0.25 mm motor/relay tracks, audio crossing the board, tracks under the pad labels, the narrow TO-92 annular ring. The Gerbers had not been inspected in a viewer, and the boards don't fit the original enclosure's mounting.
- **Tools:** noisy diffs from random pin IDs and timestamps, KiCad 10 files that the system KiCad 9 can't open, the stale AppImage mount, KiCad open during regenerations.
- **Documentation:** out-of-date text in the README and parts list.

---

## 59. User

> fix the through-hole build so it routes completely

### Work done (summary)

1. **Not the origin.** The DSN given to FreeRouting is byte-identical with or without the place origin.
2. **The real cause.** The open connection was R35 pad 1 to Q8 collector (net Q8_C, about 11 mm). With the seed-30 placement, the Q7/Q8 base and collector tracks and a GND line box in Q8's collector pad on both layers. The earlier clean board only got there because one finishing pass happened to succeed.
3. **Things that did not help:**
   - more finishing passes (100);
   - unprotected finishing, which left 7 unrouted;
   - freeing the wiring within 5 or 10 mm of the gap;
   - height weights 50, 55 and 70. Weight 50 routed but grew the board to 133.5 mm; 55 and 70 left the connection open.
   - A 2.5 mm part gap routed, but at 176.5 × 159.5 mm.
4. **Placement seed.** Seeds tried in parallel copies:

   | Seed | Result |
   |---|---|
   | 31 | Routed on the first attempt at 173.0 × 126.5 mm, estimated wiring 7,945 mm |
   | 32 | Routed on the first attempt |
   | 33 | One connection left |
   | 34 | Routed after one targeted finishing pass |
5. **Changes:**
   - `pcb.py` reads the seed from `AC30_SEED`.
   - `build.sh` tries placement seeds in turn until the routing is clean (`AC30_SEEDS`: 31, 32, 34 through-hole; 30, 31, 32 SMT, so the SMT board is unchanged).
   - Finishing passes protect the existing wiring except within 5, 10, then 20 mm of the unrouted ends, taken from a JSON DRC report (`ROUTE_FREE`, `ROUTE_FREE_RADIUS`).
   - A finishing pass is kept when it reduces the unrouted count. The old track-count check rejected passes in which FreeRouting merged segments.
   - The early stop compares route summaries, because the board files differ in KiCad's random track IDs.
   - KiCad's debug noise is filtered from the log.
6. **Result.** Through-hole 173.0 × 126.5 mm, routed on the first attempt with seed 31: 1,486 segments, 83 vias, ERC/DRC/parity clean. The SMT board is identical. `AC30-settings.md` was updated (drill table, routing, placement); `AC30-SMT-settings.md` notes the seed fallback.

---

## 60. User

> ok, finish it and then commit and push

### Claude's answer (condensed)

Committed `e0abbaa` and pushed (`97f89f4..e0abbaa`). The through-hole board was open in KiCad, so the user was asked to reload it before saving.

---

## 61. User

> update AC30-Claude.md with this session, commit and push

### Claude's answer

Added sections 56–61, committed `a4ef5d3` and pushed (`e0abbaa..a4ef5d3`).

---

## 62. User

> update the README with this session, commit and push

### Claude's answer (condensed)

Added a paragraph to the README's 2026/10/10 note covering three things: the SMT position file, the through-hole re-placement (with the build now trying other placements on its own), and a pointer to the known issues in section 58. Committed `87c5ddc` and pushed (`a4ef5d3..87c5ddc`).

---

## 63. User

> y

### Claude's answer (condensed)

There was no open question. Claude offered the next open items: a ground fill, Power-class motor/relay tracks, and checking the transcription assumptions.

---

## 64. User

> add a ground fill to both boards, update docs, commit & push

### Work done (summary)

1. **`kicad/tools/zones.py`.** Adds one GND zone on F.Cu and B.Cu over the board outline: 0.3 mm clearance, 0.25 mm minimum width, thermal reliefs (0.5 mm gap, 0.5 mm spokes), islands removed. It is written unfilled and filled by `kicad-cli pcb drc --refill-zones --save-board`.
2. **Starved thermals.** The first fill gave 10 (through-hole) and 2 (SMT) starved-thermal errors: GND pads whose relief had only a spoke into an isolated scrap of fill.
   - A one-spoke design rule did not help.
   - Smaller thermal gaps did not help.
   - Solid connections everywhere were clean, but were rejected: harder hand soldering, and tombstoning risk on small SMD parts.
   - Fix: `zones.py --solid` gives only the reported pads a solid connection, and `build.sh` refills until none is left. Through-hole: 11 pads in three rounds (IC5.6/7/8, IC9.7, J4.2, Q4.1, Q5.1, Q8.1, R20.2, R23.2, R24.2). SMT: J4.2 and J14.2.
3. **`build.sh`.** Runs the fill after routing (`FILL=0` skips it). Both boards were rebuilt: ERC/DRC at every severity and parity clean, routing and size unchanged, Gerbers regenerated.
4. **Docs.** Both settings documents gained a "GND copper fill" section, and the board table no longer says "None". The README note mentions the fill.

### Claude's answer (condensed)

Committed `fbcc017` and pushed (`87c5ddc..fbcc017`).

---

## 65. User

> update AC30-Claude.md with this session, commit and push

### Claude's answer

Added sections 62–65, committed `4b6a0a1` and pushed (`fbcc017..4b6a0a1`).

---

## 66. User

> update the README with this session, commit and push

### Claude's answer (condensed)

The README already mentioned the fill. Claude expanded that sentence: thermal reliefs on the GND pads, the fill added automatically after routing, details in the settings files. Committed `6272608` and pushed (`4b6a0a1..6272608`).

---

## 67. User

> move the motor and relay nets to the Power class, update gerbers, commit and push

### Work done (summary)

1. **`pcb.py`.** A new `POWER_CLASS` holds the rails plus MOTOR_1A/1B/2A/2B (motor contacts) and RELAY_1/2 (relay coil drive). The Power netclass patterns come from it, giving 0.6 mm tracks and 1.0/0.5 mm vias. `POWER_NETS`, which placement uses, is unchanged, so neither board's layout moved.
2. **Rebuild.** Both boards routed on the first attempt.
   - Every motor/relay track is 0.6 mm and every via on those nets is 1.0 mm.
   - Through-hole: 1,468 segments, 89 vias, 578 holes.
   - SMT: 1,704 segments, 280 vias, 361 holes.
   - The GND fill's solid-connected pads follow the new routing: through-hole D11.2, IC8.7, IC8.11, Q7.1; SMT J14.2.
   - ERC/DRC at every severity and parity clean; Gerbers regenerated.
3. **Docs.** Both settings documents were updated: Power class row, track-current note (0.6 mm ≈ 1.5 A; SMT relay contacts rated 1 A), drill tables, routing figures, Gerber hole counts, solid-pad lists.

### Claude's answer (condensed)

Committed `8bf9a8b` and pushed (`6272608..8bf9a8b`). `kicad/AC30.kicad_prl` (KiCad's local view settings) was left uncommitted.

---

## 68. User

> update AC30-Claude.md with this session, commit and push

### Claude's answer

Added sections 66–68, committed `c1535ba` and pushed (`8bf9a8b..c1535ba`).

---

## 69. User

> update the README with this session, commit and push

### Claude's answer (condensed)

Added one sentence to the README's 2026/10/10 note: the motor and relay lines now use the same 0.6 mm tracks as the power rails, good for roughly 1.5 A. Committed `77b0c25` and pushed (`c1535ba..77b0c25`).

---

## 70. User

> update AC30-Claude.md with this session, commit and push

### Claude's answer

Added sections 69–70, committed and pushed.

---

## State at the end of the session

| Item | State |
|---|---|
| Schematic sheet 1 | Switching circuit (`docs/ac30_schematica.jpg`) |
| Schematic sheet 2 | Modulator/demodulator (`docs/ac30_mod_demod.pdf`), power input J12, C23–C25 bypass, H1–H4 |
| Schematic sheet 3 | Power supply (`docs/ac30_PS.pdf`), external: no footprints |
| PCB, through-hole (`kicad/AC30.*`) | 173.0 × 126.5 mm, 2 layers, 122 through-hole footprints, fully routed, GND fill on both layers; ERC, DRC and parity clean |
| PCB, SMT (`kicad-smt/AC30_SMT.*`) | 173.0 × 88.5 mm, 2 layers, SMT except the KK-396 connectors, wire pads and mounting holes, fully routed, GND fill on both layers; ERC, DRC and parity clean |
| Connectors | J3–J5 match the original artwork; J12 is the power input; the front panel wires to through-hole pads J1 SWITCHES, J2 LEDS, J13 MOTOR, J14 MIC, J15 EAR (both boards) |
| Mounting holes | 4 × 3.2 mm, 6.35 mm in from each corner |
| Git | `main` = `origin/main` (pushed after section 70); root `.gitignore` covers KiCad local history, lock, autosave and backup files; `kicad/AC30.step` is tracked |
| Build | `cd kicad && tools/build.sh` (through-hole) or `tools/build.sh smt` (SMT): regenerate, ERC, BOM export, place (seeds tried in turn until routing is clean: 31 through-hole, 30 SMT), route (retries plus targeted finishing passes), GND fill (`tools/zones.py`), DRC, STEP export, FreeCAD check, Gerbers and drill files (`tools/gerbers.sh`) |
| Tools | KiCad 10.0.7 AppImage, FreeRouting 2.4.1 (bundled Java 25), FreeCAD 26.3.0 AppImage |
| Reference | `AC30-settings.md` and `AC30-SMT-settings.md`: rules, drill table, holes, connectors and wire pads, placement; `docs/AC30-BOM.md` and the KiCad BOM CSVs |
| Fabrication | `kicad/gerbers/` + `kicad/AC30-gerbers.zip`; `kicad-smt/gerbers/` + `kicad-smt/AC30_SMT-gerbers.zip`; SMT pick-and-place `kicad-smt/AC30_SMT-top-pos.csv` (origin bottom-left) |
| Not placed | R39 (200K DELAY trimmer), which is on no schematic |

---

## Appendix: key nets

The authoritative copy is `kicad/tools/netlist.py`. Key nets, named from the AC-30's point of view. Connector pin numbers are as on the final boards (J3–J5 match the artwork; J1/J2 are now the SWITCHES/LEDS wire pads, section 45):

| Net | Connections |
|---|---|
| LOCAL_REMOTE | R41 (pull-up), S7, J1.9, J4.4, IC11D.13, IC11B.6, IC6.11, IC6.9, IC7E.11, IC14.10, IC14.11 |
| REMOTE_N | IC7E.12 → IC11A.1 |
| READ_ACTIVE_N | IC9A.9 → IC11B.5, IC11A.2 |
| SEL_CPU_CLK / SEL_TERM_CLK | IC11B.4 → IC6.10 / IC11A.3 → IC14.9 |
| READ_EN / READ_EN_N | IC8A Q (1) → IC9A.1, IC9B.5, R29 / IC8A Q̅ (2) → R33 → Q10 |
| REC_EN / REC_EN_N | IC8B Q (13) → IC9C.12, R28, Q11 base, IC10.2 / IC8B Q̅ (12) → R32 → Q9 |
| CPU_DATA | IC12A out (3) → IC6.12, IC14.12 |
| TERM_DATA | IC12B out (6) → IC7D in, IC14.1, IC6.13 |
| TAPE_DATA_N / TAPE_DATA | IC9B.6 → IC7B.5, IC14.13 / IC7B.4 → IC11C.9, R36 (READ DATA LED) |
| DATA_SEL → DATA_IN | IC6.14 → IC7F → IC9C.11; IC9C.10 → IC7C → DATA_IN (IC2A pin 1), R34 (REC DATA LED) |
| CLOCK_OUT (demod) | Q4 collector / R22, IC6.1, IC14.3 |
| CLOCK_IN (mod) | IC6.4 → IC5B C (pin 11) |
| CPU_CLK_OUT / TERM_CLK_OUT | D8/D9 clamps, IC6.2, IC6.5 / D10/D11 clamps, IC14.5, IC6.3 |
| CARRIER_DETECT | IC3A.3 (demod), IC9A.2, IC9B.4, J4.13 |
| CARRIER_EN_N | R40 (from 555 out), S1 pole 1 (MAN → GND), J1.3, J4.14, IC5B R (pin 10) |
| Latch set/reset | IC13 XOR (CTRL_INVERT common input) → C12/C13/C14/C15 → IC8 S/R; R23–R26, S4/S5; power-on reset via C16/D5/R27 |
| Relay drive | Q9/Q10 collectors → S2/S3 A/B poles → RELAY_1/RELAY_2 → RLY1/RLY2 coils; MAN_MOTOR via D6/D7 |
| Audio | AUDIO_OUT → S2 → MIC A/B; EAR A/B → S3 → AUDIO_IN |
| DATA_OUT (demod) | IC1A Q (pin 1) → IC9.3 |
| AUDIO_OUT / AUDIO_IN | C4 → J1.10 → S2 → J1.11/J1.12 (MIC_A/B) → J14 → MIC A/B; EAR A/B → J15 → J1.18/J1.19 (EAR_A/B) → S3 → J1.17 → R8, C5 |
| DEM_PULSE | IC2C out (pin 10) → IC1A C, IC2D.12, R13 (Q1 timer), R14 (Q2 missing-pulse) |
| Power rails | J12: 1 GND, 2 +5V, 3 +13V (IC15.14), 4 −13V (IC15.1), 5 +7.5V (IC4.8), 6 −7.5V (IC4.4) |

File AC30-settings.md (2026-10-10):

# AC-30 PCB: Settings and Measurements

This sheet covers the KiCad board in `kicad/AC30.kicad_pcb` as generated by `kicad/tools/build.sh` on 2026-10-10. The board carries the switching circuit (`docs/ac30_schematica.jpg`) and the modulator/demodulator (`docs/ac30_mod_demod.pdf`). The power supply (`docs/ac30_PS.pdf`) is drawn on schematic sheet 3 but built as a **separate external unit**: its six DC outputs come onto the board on J12, a 6-pin KK-396 header on the bottom edge (section 6). The front panel is wired to rows of through-hole jumper pads on the bottom edge (section 7). All values were read from the board and project files with KiCad's own tools. Dimensions are in millimetres, with inches or mils in brackets where they help.

> **Routing is from this build.** `build.sh` re-routes every time. FreeRouting 2.4.1 is deterministic, so the same placement gives the same routing, but any change to the parts or placement changes the tracks and vias.

---

## 1. Board

| Item | Value |
|---|---|
| Size (outline) | **173.0 × 126.5 mm** (6.811 × 4.980 in) |
| Outline | Rectangle on Edge.Cuts, 0.1 mm line, square corners |
| Outline corners (KiCad page coords) | (30.0, 29.5) to (203.0, 156.0) |
| Border | 3.0 mm from the outermost part courtyard to the board edge |
| Layers | 2 copper (F.Cu top, B.Cu bottom), both routed as signal layers |
| Board thickness | 1.6 mm (0.063 in) |
| Core | FR4, 1.51 mm, εr 4.5 |
| Copper | 35 µm (1 oz) each side |
| Solder mask | Green, both sides; expansion 0 mm (fab default), minimum web 0 mm |
| Silkscreen | White, both sides |
| Copper fill / ground plane | **GND fill on both layers** over the whole board (see *GND copper fill* below). GND is also routed as 0.6 mm tracks. |
| Mounting holes | 4 × 3.2 mm unplated, 6.35 mm (¼ in) in from each edge, as on the original artwork (see section 5) |
| Parts | 122 footprints, all through-hole: 113 components, 4 KK-396 connectors, 5 front-panel jumper pad rows and 4 mounting holes |
| Nets | 152 |

Coordinates in this document are measured from the **top-left corner of the board**, with X increasing to the right and Y increasing **downward**, as seen from the component (top) side.

---

## 2. Design rules (DRC)

| Rule | mm | mils |
|---|---|---|
| Minimum track width | 0.25 | 9.8 |
| Minimum clearance (copper to copper) | 0.20 | 7.9 |
| Copper to board edge | 0.50 | 19.7 |
| Hole to copper clearance | 0.25 | 9.8 |
| Hole to hole | 0.25 | 9.8 |
| Minimum via diameter | 0.80 | 31.5 |
| Minimum through-hole drill | 0.40 | 15.7 |
| Minimum via annular ring | 0.10 | 3.9 |
| Minimum silkscreen text height / stroke | 0.80 / 0.08 | 31.5 / 3.1 |

### GND copper fill

After routing, `tools/zones.py` adds one GND zone on F.Cu and B.Cu covering the whole board outline, and `kicad-cli pcb drc --refill-zones` fills it.

| Setting | Value |
|---|---|
| Net / layers | GND, F.Cu and B.Cu |
| Outline | The board edge; the 0.5 mm copper-to-edge rule keeps the fill back from it |
| Clearance to other nets | 0.30 mm |
| Minimum fill width | 0.25 mm |
| Pad connection | Thermal reliefs: 0.5 mm gap, 0.5 mm spokes |
| Islands | Removed (fill not connected to GND is deleted) |
| Solid-connected pads | D11.2, IC8.7, IC8.11 and Q7.1 (4 pads, from this build's routing) |

The solid-connected pads are GND pads where the routed tracks left a thermal relief with only a spoke into an isolated scrap of fill, which DRC reports as a starved thermal. `build.sh` gives just those pads a solid connection and refills until none is left. The other GND pads keep their thermal reliefs, which makes them easier to hand-solder and reduces tombstoning on small parts. `FILL=0 tools/build.sh` builds without the fill.

### Net classes

| Class | Nets | Track | Clearance | Via (pad / drill) |
|---|---|---|---|---|
| Default | all signal nets | **0.25 mm** (9.8 mil) | 0.20 mm | 0.8 / 0.4 mm |
| Power | +5V, GND, +13V, −13V, +7.5V, −7.5V; MOTOR_1A/1B/2A/2B (motor contacts), RELAY_1/2 (relay coil drive) | **0.60 mm** (23.6 mil) | 0.20 mm | 1.0 / 0.5 mm |

The motor and relay lines are in the Power class, so they use 0.6 mm tracks: roughly 1.5 A on 1 oz copper with about 10 °C rise, against roughly 0.5 A for a 0.25 mm track.

---

## 3. Drill table

A KiCad drill size is the **finished hole size**. A board house adds its own allowance for plating. If you're drilling an unplated board yourself, use the size as listed. The bit columns give the nearest standard size.

| Drill (mm) | in | Number bit | Count | Plated | Used by | Pad (mm) |
|---|---|---|---|---|---|---|
| 0.40 | 0.0157 | #78 | 82 | yes | Signal vias | 0.8 round |
| 0.50 | 0.0197 | #76 | 7 | yes | Power vias | 1.0 round |
| 0.70 | 0.0276 | #70 | 8 | yes | RLY1, RLY2 (reed relay) | 1.4 round |
| 0.75 | 0.0295 | #69 | 33 | yes | Q1–Q11 (TO-92) | 1.05 × 1.5 oval |
| 0.80 | 0.0315 | #68 (1/32") | 363 | yes | ICs (DIP-8/14/16), resistors, diodes, disc caps (incl. C23–C25), C4, C17; R16 trimmer | 1.6 round (R16: 1.44) |
| 0.90 | 0.0354 | #65 | 2 | yes | D18 (5 mm LED) | 1.8 round |
| 1.00 | 0.0394 | #60 | 38 | yes | C16 (10 mm electrolytic); J1, J2, J13–J15 front-panel jumper pads (36) | 2.0 round (C16); 1.7 square (pin 1) / round |
| 1.70 | 0.0669 | #51 | 41 | yes | J3–J5, J12 (Molex KK-396) | 3.16 × 4.1 oval |
| 3.20 | 0.1260 | #30, or ⅛ in | 4 | **no** | H1–H4 mounting holes | none (bare hole) |
| **Total** | | | **578** | | 489 component and mounting holes + 89 vias | |

The 89 via positions and the split between the two via sizes come from the router, so they change from build to build. The component holes don't.

**If you have fewer bits:** the 0.70 and 0.75 mm holes can be drilled at 0.8 mm. That would leave three sizes for the component holes: 0.8, 1.0 and 1.7 mm, plus 3.2 mm for the mounting holes. The TO-92 pads would then have only a 0.125 mm ring on their narrow side.

### Annular rings (pad minus drill, per side)

| Footprint | Ring |
|---|---|
| Signal via 0.8 / 0.4 | 0.20 mm |
| Power via 1.0 / 0.5 | 0.25 mm |
| DIP, resistor, diode, disc cap 1.6 / 0.8 | 0.40 mm |
| R16 trimmer 1.44 / 0.8 | 0.32 mm |
| TO-92 1.05 × 1.5 / 0.75 | **0.15 mm** on the narrow side (the smallest on the board) |
| Relay 1.4 / 0.7 | 0.35 mm |
| LED 1.8 / 0.9 | 0.45 mm |
| C16 2.0 / 1.0 | 0.50 mm |
| Jumper pad 1.7 / 1.0 | 0.35 mm |
| KK-396 3.16 × 4.1 / 1.7 | 0.73 mm on the narrow side |

---

## 4. Routing result (this build)

| Item | Value |
|---|---|
| Unrouted connections | 0 |
| DRC violations | 0 (all severities, including silkscreen) |
| Schematic parity issues | 0 |
| Track segments | 1,468 |
| Vias | 89 (82 at 0.8/0.4 mm, 7 at 1.0/0.5 mm) |

| Track width | F.Cu (top) | B.Cu (bottom) |
|---|---|---|
| 0.25 mm | 435 segments, 3,638 mm | 691 segments, 4,375 mm |
| 0.60 mm | 156 segments, 918 mm | 186 segments, 1,401 mm |
| **Total** | **4,556 mm** | **5,776 mm** |

---

## 5. Mounting holes

The original artwork has a hole about ¼ in in from each corner. I measured them on `docs/ac30_redblue150.jpg`, using the 3.96 mm connector pitch as the scale (5.754 px/mm). The four holes came out 5.7–6.5 mm from their edges, 6.2 mm on average, which points to a ¼ in (6.35 mm) design inset. The original board was about 194 × 187 mm, larger than this one, so the holes keep that inset from this board's corners rather than the original's absolute positions.

| Ref | X | Y | Corner |
|---|---|---|---|
| H1 | 6.35 | 6.35 | top left |
| H2 | 166.65 | 6.35 | top right |
| H3 | 166.65 | 120.15 | bottom right |
| H4 | 6.35 | 120.15 | bottom left |

| Item | Value |
|---|---|
| Hole | 3.2 mm (0.126 in) unplated, no copper pad |
| Footprint | `MountingHole:MountingHole_3.2mm_M3` |
| Screw | #4 or M3; head and standoff clearance Ø6.9 mm (courtyard) |
| Hole centres, left to right | 160.30 mm (6.311 in) |
| Hole centres, top to bottom | 113.80 mm (4.480 in) |

The artwork shows a copper pad about 4.6 mm across around each hole. This board leaves the holes bare, so a screw or standoff can't short to anything.

The connector and jumper pad rows start about 11.8 mm from the side edges, which keeps them clear of each hole's Ø6.9 mm keepout plus the 2 mm part gap.

---

## 6. Power input (external supply)

The power supply on `docs/ac30_PS.pdf` is built as a separate unit and isn't on this PCB:
- 120 VAC line cord P1, POWER switch S6 and fuse F1 (1 A);
- transformer T1, 18 VAC centre-tapped secondary;
- bridge D14–D17 (1N4003), giving ±13 V across C21 (1000 µF 25 V) and C22 (100 µF 16 V);
- R48/D12 and R49/D13 (330 Ω, 7.5 V zeners) for ±7.5 V;
- IC16 (7805) for +5 V.

It's drawn on schematic sheet 3 with no footprints, so it's in the BOM but not on the board. Its six outputs plug into **J12**, a 6-pin Molex KK-396 header on the bottom edge, the same family as J3–J5. The housing is keyed, so the plug can't go in reversed.

| J12 pin | Rail | Feeds |
|---|---|---|
| 1 | GND | Common ground |
| 2 | +5V | All logic |
| 3 | +13V | IC15 (1488) pin 14 |
| 4 | −13V | IC15 (1488) pin 1 |
| 5 | +7.5V | IC4 (4558) pin 8 |
| 6 | −7.5V | IC4 (4558) pin 4 |

| Item | Value |
|---|---|
| Connector | Molex KK-396 A-41791-0006, 1×6 vertical, 3.96 mm pitch, 1.7 mm holes |
| Position | Bottom edge, right of the jumper pads; pin 1 at (130.65, 118.05) |
| Tracks | 0.6 mm (Power class) |
| +5 V bypass on the board | C23, C24, C25, 0.1 µF |
| The artwork's J2 pins 11/12 (18 VAC A/B) | Not needed, since the transformer and rectifier are off-board |

Corrections and assumptions in the supply transcription:
- **7805 ground:** the drawing joins IC16's GND / C23–C25 return line to the bridge's −13 V corner. That would make the regulator put out about −8 V, so IC16 GND is taken as GND.
- **IC15 supply:** IC15's supply pins aren't drawn on any schematic. They're taken as ±13 V, the only load left for those outputs.
- **IC4 supply:** IC4 uses ±7.5 V, as the assembly manual states.

---

## 7. Connectors and front-panel jumper pads

### Molex connectors

J3–J5 and J12 are Molex KK-396 vertical headers (A-41791 series), through-hole, with 3.96 mm (0.156 in) pitch and 1.7 mm holes. Pin 1 is at the left, seen from the component side. J3–J5 pin assignments match the original artwork.

| Ref | Pins | Edge | Pin 1 X | Pin 1 Y | Length, pin 1 to last pin |
|---|---|---|---|---|---|
| J3 (COMP) | 10 | top | 14.20 | 9.10 | 35.64 mm |
| J4 (control) | 15 | top | 58.65 | 9.10 | 55.44 mm |
| J5 (TERM) | 10 | top | 122.95 | 9.10 | 35.64 mm |
| J12 (power input) | 6 | bottom | 130.65 | 118.05 | 19.80 mm |

### Front-panel jumper pads

The board has no front-panel harness connectors. The original J1/J2 KK-396 headers are replaced by five rows of plain through-hole pads along the bottom edge, one row per group of front-panel parts. Solder hook-up wire straight from each pad to the switch, LED or jack.
- Pads are 1.7 mm with 1.0 mm holes at 2.54 mm (0.1 in) pitch (the `PinHeader_1x…_P2.54mm_Vertical` footprints). Pin 1 is square.
- Each pad has its net name on the silkscreen beside it, and the group name is printed above the row.
- Every wire has its own pad. The RECORD A/B (S2) and PLAY A/B (S3) audio poles wire to the SWITCHES row (AUDIO_OUT, MIC_A, MIC_B and AUDIO_IN, EAR_A, EAR_B). The four jacks wire to the MIC and EAR rows, each jack to a tip pad and its own GND pad. The board joins the MIC_x and EAR_x pads of the two rows.

| Ref | Group | Pads | Pin 1 X | Pin 1 Y | Pads, from pin 1 (left) |
|---|---|---|---|---|---|
| J1 | SWITCHES | 19 | 13.60 | 121.70 | +5V, GND, CARRIER_EN_N, MAN_MOTOR, REC_SET, REC_RST, READ_SET, READ_RST, LOCAL_REMOTE, AUDIO_OUT, MIC_A, MIC_B, REC_RLY_DRV, RELAY_1, RELAY_2, READ_RLY_DRV, AUDIO_IN, EAR_A, EAR_B |
| J2 | LEDS | 5 | 66.85 | 121.70 | +5V, LED_REC_RDY, LED_READ_RDY, LED_REC_DATA, LED_READ_DATA |
| J13 | MOTOR | 4 | 84.55 | 121.70 | MOTOR_1A, MOTOR_1B (MOTOR A jack), MOTOR_2A, MOTOR_2B (MOTOR B jack) |
| J14 | MIC | 4 | 99.70 | 121.70 | MIC_A, GND (MIC A jack), MIC_B, GND (MIC B jack) |
| J15 | EAR | 4 | 114.85 | 121.70 | EAR_A, GND (EAR A jack), EAR_B, GND (EAR B jack) |

What each switch pad goes to:

| Front-panel part | Pads |
|---|---|
| S1 MOTOR CONTROL AUTO/MAN | pole 1: CARRIER_EN_N (common), GND (MAN); pole 2: MAN_MOTOR (common), +5V (MAN) |
| S2 RECORD A/B | pole 1: AUDIO_OUT (common), MIC_A (A), MIC_B (B); pole 2: REC_RLY_DRV (common), RELAY_1 (A), RELAY_2 (B) |
| S3 PLAY A/B | pole 1: READ_RLY_DRV (common), RELAY_1 (A), RELAY_2 (B); pole 2: AUDIO_IN (common), EAR_A (A), EAR_B (B) |
| S4 RECORD ON/OFF | +5V (common), REC_SET, REC_RST (momentary) |
| S5 READER ON/OFF | +5V (common), READ_SET, READ_RST (momentary) |
| S7 LOCAL/REMOTE | LOCAL_REMOTE (common), GND |
| LEDs D19–D22 | anodes to the LEDS row +5V; cathodes to LED_REC_RDY, LED_READ_RDY, LED_REC_DATA, LED_READ_DATA |
| Motor jacks J10 / J11 | MOTOR row: MOTOR_1A / 1B (tip / sleeve) and MOTOR_2A / 2B |
| MIC jacks J6 / J7, EAR jacks J8 / J9 | MIC row: MIC_A + GND, MIC_B + GND; EAR row: EAR_A + GND, EAR_B + GND (tip + sleeve) |

---

## 8. Placement (pin-1 positions)

Each X/Y is the position of the part's **pin 1**, measured from the board's top-left corner (Y downward, top view). Rotation is the footprint angle in degrees.

| Ref | Value | Footprint | X | Y | Rot |
|---|---|---|---|---|---|
| C1 | 1000pF | C_Disc_D5.0mm_W2.5mm_P5.00mm | 77.50 | 58.10 | 90 |
| C2 | 2000pF | C_Disc_D5.0mm_W2.5mm_P5.00mm | 107.50 | 94.35 | 90 |
| C3 | 0.022uF | C_Disc_D5.0mm_W2.5mm_P5.00mm | 82.50 | 58.10 | 90 |
| C4 | 1uF 15V | CP_Radial_D6.3mm_P2.50mm | 118.15 | 91.70 | 0 |
| C5 | 0.01uF | C_Disc_D5.0mm_W2.5mm_P5.00mm | 112.50 | 94.35 | 90 |
| C6 | 1000pF | C_Disc_D5.0mm_W2.5mm_P5.00mm | 138.50 | 84.40 | 90 |
| C7 | 0.047uF | C_Disc_D5.0mm_W2.5mm_P5.00mm | 129.50 | 96.15 | 90 |
| C8 | 0.022uF | C_Disc_D5.0mm_W2.5mm_P5.00mm | 134.50 | 96.15 | 90 |
| C9 | 0.047uF | C_Disc_D5.0mm_W2.5mm_P5.00mm | 155.50 | 43.85 | 90 |
| C10 | 2700pF | C_Disc_D5.0mm_W2.5mm_P5.00mm | 139.50 | 96.15 | 90 |
| C11 | 470pF | C_Disc_D5.0mm_W2.5mm_P5.00mm | 145.50 | 58.10 | 90 |
| C12 | 1000pF | C_Disc_D5.0mm_W2.5mm_P5.00mm | 28.50 | 72.35 | 90 |
| C13 | 1000pF | C_Disc_D5.0mm_W2.5mm_P5.00mm | 33.50 | 72.35 | 90 |
| C14 | 1000pF | C_Disc_D5.0mm_W2.5mm_P5.00mm | 38.50 | 72.35 | 90 |
| C15 | 1000pF | C_Disc_D5.0mm_W2.5mm_P5.00mm | 43.50 | 72.35 | 90 |
| C16 | 100uF 16V | CP_Radial_D10.0mm_P5.00mm | 34.75 | 57.30 | 0 |
| C17 | 10uF 10V tant | CP_Radial_D6.3mm_P2.50mm | 6.15 | 35.15 | 0 |
| C18 | 0.01uF | C_Disc_D5.0mm_W2.5mm_P5.00mm | 22.25 | 23.55 | 90 |
| C19 | 470pF | C_Disc_D5.0mm_W2.5mm_P5.00mm | 145.50 | 88.50 | 90 |
| C20 | 470pF | C_Disc_D5.0mm_W2.5mm_P5.00mm | 150.50 | 88.50 | 90 |
| C23 | 0.1uF | C_Disc_D5.0mm_W2.5mm_P5.00mm | 60.80 | 100.90 | 90 |
| C24 | 0.1uF | C_Disc_D5.0mm_W2.5mm_P5.00mm | 65.80 | 100.90 | 90 |
| C25 | 0.1uF | C_Disc_D5.0mm_W2.5mm_P5.00mm | 70.80 | 100.90 | 90 |
| D1 | 1N4148 | D_DO-35_SOD27_P7.62mm_Horizontal | 98.25 | 97.00 | 90 |
| D2 | 1N4148 | D_DO-35_SOD27_P7.62mm_Horizontal | 102.75 | 97.00 | 90 |
| D3 | 1N4732 4.7V | D_DO-35_SOD27_P7.62mm_Horizontal | 129.25 | 87.05 | 90 |
| D4 | 1N4148 | D_DO-35_SOD27_P7.62mm_Horizontal | 133.75 | 87.05 | 90 |
| D5 | 1N4148 | D_DO-35_SOD27_P7.62mm_Horizontal | 45.75 | 60.75 | 90 |
| D6 | 1N4148 | D_DO-35_SOD27_P7.62mm_Horizontal | 38.25 | 91.80 | 90 |
| D7 | 1N4148 | D_DO-35_SOD27_P7.62mm_Horizontal | 42.75 | 91.80 | 90 |
| D8 | 1N4148 | D_DO-35_SOD27_P7.62mm_Horizontal | 71.00 | 47.45 | 90 |
| D9 | 1N4148 | D_DO-35_SOD27_P7.62mm_Horizontal | 54.25 | 70.30 | 90 |
| D10 | 1N4148 | D_DO-35_SOD27_P7.62mm_Horizontal | 58.75 | 70.30 | 90 |
| D11 | 1N4148 | D_DO-35_SOD27_P7.62mm_Horizontal | 63.25 | 70.30 | 90 |
| D18 | LED | LED_D5.0mm | 87.95 | 55.25 | 0 |
| H1 | MountingHole | MountingHole_3.2mm_M3 | 6.35 | 6.35 | 0 |
| H2 | MountingHole | MountingHole_3.2mm_M3 | 166.65 | 6.35 | 0 |
| H3 | MountingHole | MountingHole_3.2mm_M3 | 166.65 | 120.15 | 0 |
| H4 | MountingHole | MountingHole_3.2mm_M3 | 6.35 | 120.15 | 0 |
| IC1 | 4013 | DIP-14_W7.62mm | 15.05 | 43.10 | 0 |
| IC2 | 4001 | DIP-14_W7.62mm | 145.05 | 19.05 | 0 |
| IC3 | 4070 | DIP-14_W7.62mm | 129.05 | 19.05 | 0 |
| IC4 | 4558 | DIP-8_W7.62mm | 98.05 | 61.30 | 0 |
| IC5 | 4013 | DIP-14_W7.62mm | 77.05 | 19.05 | 0 |
| IC6 | 4053 | DIP-16_W7.62mm | 54.05 | 40.30 | 0 |
| IC7 | 4049 | DIP-16_W7.62mm | 77.05 | 63.65 | 0 |
| IC8 | 4013 | DIP-14_W7.62mm | 28.05 | 19.05 | 0 |
| IC9 | 4023 | DIP-14_W7.62mm | 98.05 | 19.05 | 0 |
| IC10 | 555 | DIP-8_W7.62mm | 5.05 | 19.00 | 0 |
| IC11 | 4001 | DIP-14_W7.62mm | 51.05 | 19.05 | 0 |
| IC12 | 1489 | DIP-14_W7.62mm | 64.05 | 19.05 | 0 |
| IC13 | 4070 | DIP-14_W7.62mm | 7.05 | 64.40 | 0 |
| IC14 | 4053 | DIP-16_W7.62mm | 116.05 | 19.00 | 0 |
| IC15 | 1488 | DIP-14_W7.62mm | 145.05 | 63.70 | 0 |
| J1 | SWITCHES | PinHeader_1x19_P2.54mm_Vertical | 13.60 | 121.70 | 90 |
| J2 | LEDS | PinHeader_1x05_P2.54mm_Vertical | 66.85 | 121.70 | 90 |
| J3 | Computer interface (COMP) | Molex_KK-396_A-41791-0010_1x10_P3.96mm_Vertical | 14.20 | 9.10 | 0 |
| J4 | Control interface | Molex_KK-396_A-41791-0015_1x15_P3.96mm_Vertical | 58.65 | 9.10 | 0 |
| J5 | Terminal interface (TERM) | Molex_KK-396_A-41791-0010_1x10_P3.96mm_Vertical | 122.95 | 9.10 | 0 |
| J12 | Power input | Molex_KK-396_A-41791-0006_1x06_P3.96mm_Vertical | 130.65 | 118.05 | 0 |
| J13 | MOTOR | PinHeader_1x04_P2.54mm_Vertical | 84.55 | 121.70 | 90 |
| J14 | MIC | PinHeader_1x04_P2.54mm_Vertical | 99.70 | 121.70 | 90 |
| J15 | EAR | PinHeader_1x04_P2.54mm_Vertical | 114.85 | 121.70 | 90 |
| Q1 | 2N5210 | TO-92_Inline | 129.45 | 101.90 | 0 |
| Q2 | 2N5210 | TO-92_Inline | 150.45 | 54.80 | 0 |
| Q3 | 2N5087 | TO-92_Inline | 136.90 | 101.90 | 0 |
| Q4 | 2N5210 | TO-92_Inline | 67.95 | 64.35 | 0 |
| Q5 | 2N5210 | TO-92_Inline | 98.45 | 54.80 | 0 |
| Q6 | 2N5210 | TO-92_Inline | 105.90 | 54.80 | 0 |
| Q7 | 2N5210 | TO-92_Inline | 77.45 | 101.95 | 0 |
| Q8 | 2N5210 | TO-92_Inline | 84.90 | 101.95 | 0 |
| Q9 | 2N5087 | TO-92_Inline | 28.45 | 78.15 | 0 |
| Q10 | 2N5087 | TO-92_Inline | 35.90 | 78.15 | 0 |
| Q11 | 2N5087 | TO-92_Inline | 14.25 | 34.50 | 0 |
| R1 | 33K | R_Axial_DIN0207_L6.3mm_D2.5mm_P10.16mm_Horizontal | 82.50 | 49.00 | 90 |
| R2 | 10K | R_Axial_DIN0207_L6.3mm_D2.5mm_P10.16mm_Horizontal | 87.50 | 49.00 | 90 |
| R3 | 10K | R_Axial_DIN0207_L6.3mm_D2.5mm_P10.16mm_Horizontal | 92.50 | 49.00 | 90 |
| R4 | 330 | R_Axial_DIN0207_L6.3mm_D2.5mm_P10.16mm_Horizontal | 110.25 | 71.00 | 90 |
| R5 | 2.2K | R_Axial_DIN0207_L6.3mm_D2.5mm_P10.16mm_Horizontal | 115.25 | 71.00 | 90 |
| R6 | 4.7K | R_Axial_DIN0207_L6.3mm_D2.5mm_P10.16mm_Horizontal | 120.25 | 71.00 | 90 |
| R7 | 470 | R_Axial_DIN0207_L6.3mm_D2.5mm_P10.16mm_Horizontal | 98.50 | 85.25 | 90 |
| R8 | 100K | R_Axial_DIN0207_L6.3mm_D2.5mm_P10.16mm_Horizontal | 103.50 | 85.25 | 90 |
| R9 | 10K | R_Axial_DIN0207_L6.3mm_D2.5mm_P10.16mm_Horizontal | 108.50 | 85.25 | 90 |
| R10 | 330K | R_Axial_DIN0207_L6.3mm_D2.5mm_P10.16mm_Horizontal | 113.50 | 85.25 | 90 |
| R11 | 10K | R_Axial_DIN0207_L6.3mm_D2.5mm_P10.16mm_Horizontal | 118.50 | 85.25 | 90 |
| R12 | 10K | R_Axial_DIN0207_L6.3mm_D2.5mm_P10.16mm_Horizontal | 129.50 | 49.00 | 90 |
| R13 | 22K | R_Axial_DIN0207_L6.3mm_D2.5mm_P10.16mm_Horizontal | 134.50 | 49.00 | 90 |
| R14 | 22K | R_Axial_DIN0207_L6.3mm_D2.5mm_P10.16mm_Horizontal | 157.25 | 28.70 | 90 |
| R15 | 10K | R_Axial_DIN0207_L6.3mm_D2.5mm_P10.16mm_Horizontal | 139.50 | 49.00 | 90 |
| R16 | 20K trim | Potentiometer_Bourns_3386P_Vertical | 133.05 | 73.90 | 0 |
| R17 | 100K | R_Axial_DIN0207_L6.3mm_D2.5mm_P10.16mm_Horizontal | 129.50 | 63.25 | 90 |
| R18 | 100K | R_Axial_DIN0207_L6.3mm_D2.5mm_P10.16mm_Horizontal | 145.50 | 49.00 | 90 |
| R19 | 10K | R_Axial_DIN0207_L6.3mm_D2.5mm_P10.16mm_Horizontal | 134.50 | 63.25 | 90 |
| R20 | 10K | R_Axial_DIN0207_L6.3mm_D2.5mm_P10.16mm_Horizontal | 139.50 | 63.25 | 90 |
| R21 | 10K | R_Axial_DIN0207_L6.3mm_D2.5mm_P10.16mm_Horizontal | 150.50 | 49.00 | 90 |
| R22 | 10K | R_Axial_DIN0207_L6.3mm_D2.5mm_P10.16mm_Horizontal | 66.25 | 50.00 | 90 |
| R23 | 100K | R_Axial_DIN0207_L6.3mm_D2.5mm_P10.16mm_Horizontal | 40.25 | 28.70 | 90 |
| R24 | 100K | R_Axial_DIN0207_L6.3mm_D2.5mm_P10.16mm_Horizontal | 45.25 | 28.70 | 90 |
| R25 | 100K | R_Axial_DIN0207_L6.3mm_D2.5mm_P10.16mm_Horizontal | 28.50 | 49.00 | 90 |
| R26 | 100K | R_Axial_DIN0207_L6.3mm_D2.5mm_P10.16mm_Horizontal | 33.50 | 49.00 | 90 |
| R27 | 10K | R_Axial_DIN0207_L6.3mm_D2.5mm_P10.16mm_Horizontal | 38.50 | 49.00 | 90 |
| R28 | 10K | R_Axial_DIN0207_L6.3mm_D2.5mm_P10.16mm_Horizontal | 110.25 | 28.70 | 90 |
| R29 | 10K | R_Axial_DIN0207_L6.3mm_D2.5mm_P10.16mm_Horizontal | 98.50 | 49.00 | 90 |
| R30 | 470 | R_Axial_DIN0207_L6.3mm_D2.5mm_P10.16mm_Horizontal | 103.50 | 49.00 | 90 |
| R31 | 470 | R_Axial_DIN0207_L6.3mm_D2.5mm_P10.16mm_Horizontal | 108.50 | 49.00 | 90 |
| R32 | 10K | R_Axial_DIN0207_L6.3mm_D2.5mm_P10.16mm_Horizontal | 43.50 | 49.00 | 90 |
| R33 | 10K | R_Axial_DIN0207_L6.3mm_D2.5mm_P10.16mm_Horizontal | 28.50 | 63.25 | 90 |
| R34 | 10K | R_Axial_DIN0207_L6.3mm_D2.5mm_P10.16mm_Horizontal | 89.25 | 73.35 | 90 |
| R35 | 470 | R_Axial_DIN0207_L6.3mm_D2.5mm_P10.16mm_Horizontal | 77.50 | 96.20 | 90 |
| R36 | 10K | R_Axial_DIN0207_L6.3mm_D2.5mm_P10.16mm_Horizontal | 82.50 | 96.20 | 90 |
| R37 | 470 | R_Axial_DIN0207_L6.3mm_D2.5mm_P10.16mm_Horizontal | 87.50 | 96.20 | 90 |
| R38 | 47K | R_Axial_DIN0207_L6.3mm_D2.5mm_P10.16mm_Horizontal | 17.25 | 28.70 | 90 |
| R40 | 10K | R_Axial_DIN0207_L6.3mm_D2.5mm_P10.16mm_Horizontal | 89.25 | 28.70 | 90 |
| R41 | 10K | R_Axial_DIN0207_L6.3mm_D2.5mm_P10.16mm_Horizontal | 92.50 | 96.20 | 90 |
| R42 | 10K | R_Axial_DIN0207_L6.3mm_D2.5mm_P10.16mm_Horizontal | 19.25 | 74.05 | 90 |
| R43 | 470 | R_Axial_DIN0207_L6.3mm_D2.5mm_P10.16mm_Horizontal | 77.50 | 49.00 | 90 |
| R44 | 10K | R_Axial_DIN0207_L6.3mm_D2.5mm_P10.16mm_Horizontal | 7.50 | 94.35 | 90 |
| R45 | 10K | R_Axial_DIN0207_L6.3mm_D2.5mm_P10.16mm_Horizontal | 12.50 | 94.35 | 90 |
| R46 | 10K | R_Axial_DIN0207_L6.3mm_D2.5mm_P10.16mm_Horizontal | 17.50 | 94.35 | 90 |
| R47 | 10K | R_Axial_DIN0207_L6.3mm_D2.5mm_P10.16mm_Horizontal | 22.50 | 94.35 | 90 |
| RLY1 | 6V reed relay | Relay_SPST_StandexMeder_SIL_Form1A | 48.55 | 85.95 | 0 |
| RLY2 | 6V reed relay | Relay_SPST_StandexMeder_SIL_Form1A | 39.55 | 97.65 | 0 |
---

## 9. Tools and generator settings

| Tool | Version / setting |
|---|---|
| KiCad | 10.0.7 AppImage (`~/bin/kicad.AppImage`), with its bundled symbol, footprint and 3D libraries |
| FreeRouting | 2.4.1 (`~/bin/freerouting-2.4.1/`, with its own Java 25 runtime), run headless with `-mp 100 -mt 1` (`tools/route.py`). `build.sh` routes the placed board afresh up to 4 times (`ROUTE_ATTEMPTS`) and keeps the first result with a completely clean DRC. If none is clean, up to 3 finishing passes route only what's left on the best result: the existing wiring is protected except within 5, 10, then 20 mm of the unrouted ends, where FreeRouting may move tracks, and each pass must reduce the unrouted count and pass DRC. If a placement still isn't clean, `build.sh` places the board again with the next seed (`AC30_SEEDS`, default 31, 32, 34 for this board). This build used seed 31 and routed completely on the first attempt. |
| FreeCAD | 26.3.0 AppImage (`~/bin/FreeCAD_26.3rc1-Linux-x86_64.AppImage`), headless `freecadcmd` check of `AC30.step` |
| File formats | Schematic 20260306, PCB 20260206 (KiCad 10) |

Placement settings in `tools/pcb.py`:

| Setting | Value |
|---|---|
| Gap between parts | 2.0 mm |
| Border | 3.0 mm |
| Board origin on the drawing sheet | (30, 30) mm, before the outline is snapped to 0.5 mm |
| Outline snap | 0.5 mm |
| Height vs. wire weight (`AC30_HEIGHT_W`) | 60 for this board, set in `build.sh` (1 mm of board height costs the same as 60 mm of wire). At the default of 25 the bottom row pulled the board out to 148.5 mm tall. |
| Block orders tried (`AC30_ORDERS`) | 300 random orders plus 4 sorted ones, seed 31 (`AC30_SEED`, set per try by `build.sh`). Seed 30 left Q8's collector boxed in, and one connection (R35–Q8) could not be routed. |
| Estimated signal wiring | 7,945 mm (half-perimeter estimate, before routing; every net except +5V and GND) |
| Mounting-hole inset (`HOLE_INSET`) | 6.35 mm; the connector rows are moved in to clear the holes |

How the layout is built:
- Discrete parts stand upright (rotated 90°), except the relays.
- Each discrete part joins the IC it shares the most signal nets with.
- J3–J5 run along the top edge. The jumper pad rows (J1, J2, J13–J15, turned 90° so their labels face into the board) and J12 run along the bottom, sharing a bottom line and inset to clear the mounting holes.
- H1–H4 go 6.35 mm in from each corner of the final outline.

### Fabrication files

`kicad/gerbers/` and `kicad/AC30-gerbers.zip` (the same files, zipped for the board house) are written by `kicad/tools/gerbers.sh` at the end of every build, or on their own with `tools/gerbers.sh`.

| File | Contents |
|---|---|
| Gerbers (X2, Protel extensions) | F.Cu (`.gtl`), B.Cu (`.gbl`), F/B.Mask (`.gts`/`.gbs`), F/B.Silkscreen (`.gto`/`.gbo`, solder mask subtracted), Edge.Cuts (`.gm1`) |
| `AC30-job.gbrjob` | Gerber job file (layer stack, board size) |
| `AC30-PTH.drl`, `AC30-NPTH.drl` | Excellon drill files in mm: 574 plated holes, 4 unplated (mounting holes) |
| `*-drl_map.pdf`, `AC30-drill-report.txt` | Drill maps and the drill report |

The board's drill/place origin is its bottom-left corner, (30, 156) in KiCad page coordinates. The Gerbers and drill files use absolute coordinates.

### 3D model

`kicad/AC30.step` is exported on every build. Git ignores it.

| Item | Value |
|---|---|
| Board body | 173.0 × 126.5 × 1.51 mm |
| Full assembly height | 15.1 mm |

These 5 parts have no 3D model in the KiCad library and appear only as footprints:
- J3–J5 and J12 (KK-396)
- R16 (Bourns 3386P trimmer)

The jumper pad rows show as 0.1 in pin headers in the model; on the board they are bare pads for wires.

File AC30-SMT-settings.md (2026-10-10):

# AC-30 SMT PCB: Settings and Measurements

This sheet covers the surface-mount board in `kicad-smt/AC30_SMT.kicad_pcb`, generated by `kicad/tools/build.sh smt` on 2026-10-09. The through-hole board is described in `AC30-settings.md`.

Both boards share the same three schematic sheets:
- the switching circuit (`docs/ac30_schematica.jpg`);
- the modulator/demodulator (`docs/ac30_mod_demod.pdf`);
- the external power supply (`docs/ac30_PS.pdf`), which isn't on either board.

Every on-board part is surface mount except the four Molex KK-396 connectors, the five front-panel jumper pad strips and the four mounting holes. All SMD parts are on the **top side**.

All values were read from the board and project files with KiCad's own tools. Dimensions are in millimetres, with inches or mils in brackets where they help.

> **Routing is from this build.** `build.sh smt` re-routes every time. FreeRouting 2.4.1 is deterministic, so the same placement gives the same routing, but any change to the parts or placement changes the tracks and vias.

---

## 1. Board

| Item | Value |
|---|---|
| Size (outline) | **173.0 × 88.5 mm** (6.811 × 3.484 in) |
| Compared with the through-hole board | 173.0 × 126.5 mm, so the SMT board has about 30% less area |
| Outline | Rectangle on Edge.Cuts, 0.1 mm line, square corners |
| Outline corners (KiCad page coords) | (30.0, 29.5) to (203.0, 118.0) |
| Border | 3.0 mm from the outermost part courtyard to the board edge |
| Layers | 2 copper (F.Cu top, B.Cu bottom), both routed as signal layers |
| Board thickness | 1.6 mm (0.063 in) |
| Core | FR4, 1.51 mm, εr 4.5 |
| Copper | 35 µm (1 oz) each side |
| Solder mask | Green, both sides; expansion 0 mm (fab default), minimum web 0 mm |
| Solder paste | Top side only, apertures as defined by each footprint (board paste margin 0) |
| Silkscreen | White, both sides |
| Copper fill / ground plane | **GND fill on both layers** over the whole board (see *GND copper fill* below). GND is also routed as 0.6 mm tracks. |
| Mounting holes | 4 × 3.2 mm unplated, 6.35 mm (¼ in) in from each edge, as on the original artwork |
| Parts | 122 footprints: 109 SMD components, 4 KK-396 connectors, 5 jumper pad strips and 4 mounting holes |
| Pads | 416 SMD pads (top) and 77 plated through-hole pads (41 connector, 36 jumper) |
| Nets | 156 (152 signal and power nets, plus 4 single-pin nets from the relays' unused NC contacts) |

Coordinates in this document are measured from the **top-left corner of the board**, with X increasing to the right and Y increasing **downward**, as seen from the component (top) side.

---

## 2. Design rules (DRC)

These are the same rules as the through-hole board.

| Rule | mm | mils |
|---|---|---|
| Minimum track width | 0.25 | 9.8 |
| Minimum clearance (copper to copper) | 0.20 | 7.9 |
| Copper to board edge | 0.50 | 19.7 |
| Hole to copper clearance | 0.25 | 9.8 |
| Hole to hole | 0.25 | 9.8 |
| Minimum via diameter | 0.80 | 31.5 |
| Minimum through-hole drill | 0.40 | 15.7 |
| Minimum via annular ring | 0.10 | 3.9 |
| Minimum silkscreen text height / stroke | 0.80 / 0.08 | 31.5 / 3.1 |

### GND copper fill

After routing, `tools/zones.py` adds one GND zone on F.Cu and B.Cu covering the whole board outline, and `kicad-cli pcb drc --refill-zones` fills it.

| Setting | Value |
|---|---|
| Net / layers | GND, F.Cu and B.Cu |
| Outline | The board edge; the 0.5 mm copper-to-edge rule keeps the fill back from it |
| Clearance to other nets | 0.30 mm |
| Minimum fill width | 0.25 mm |
| Pad connection | Thermal reliefs: 0.5 mm gap, 0.5 mm spokes |
| Islands | Removed (fill not connected to GND is deleted) |
| Solid-connected pads | J14.2 (1 pad, from this build's routing) |

The solid-connected pads are GND pads where the routed tracks left a thermal relief with only a spoke into an isolated scrap of fill, which DRC reports as a starved thermal. `build.sh` gives just those pads a solid connection and refills until none is left. The other GND pads keep their thermal reliefs, which makes them easier to hand-solder and reduces tombstoning on small parts. `FILL=0 tools/build.sh` builds without the fill.

### Net classes

| Class | Nets | Track | Clearance | Via (pad / drill) |
|---|---|---|---|---|
| Default | all signal nets | **0.25 mm** (9.8 mil) | 0.20 mm | 0.8 / 0.4 mm |
| Power | +5V, GND, +13V, −13V, +7.5V, −7.5V; MOTOR_1A/1B/2A/2B (motor contacts), RELAY_1/2 (relay coil drive) | **0.60 mm** (23.6 mil) | 0.20 mm | 1.0 / 0.5 mm |

A 0.25 mm track fits between adjacent SOIC pads. The pads are 0.6 mm wide at 1.27 mm pitch, leaving a 0.67 mm gap, and the track plus 0.2 mm clearance on each side needs 0.65 mm.

The motor and relay lines are in the Power class, so they use 0.6 mm tracks (roughly 1.5 A on 1 oz copper with about 10 °C rise). The Omron G6K-2F-Y relay contacts are rated 1 A.

---

## 3. Drill table

A KiCad drill size is the **finished hole size**; the board house adds its own plating allowance. The SMT board has five hole sizes.

| Drill (mm) | in | Number bit | Count | Plated | Used by | Pad (mm) |
|---|---|---|---|---|---|---|
| 0.40 | 0.0157 | #78 | 252 | yes | Signal vias | 0.8 round |
| 0.50 | 0.0197 | #76 | 28 | yes | Power vias | 1.0 round |
| 1.00 | 0.0394 | #60 | 36 | yes | J1, J2, J13–J15 front-panel jumper pads | 1.7 square (pin 1) / round |
| 1.70 | 0.0669 | #51 | 41 | yes | J3–J5, J12 (Molex KK-396) | 3.16 × 4.1 oval |
| 3.20 | 0.1260 | #30, or ⅛ in | 4 | **no** | H1–H4 mounting holes | none (bare hole) |
| **Total** | | | **361** | | 81 component and mounting holes + 280 vias | |

Most of the holes are vias. SMD pads are only on the top, so many connections drop to B.Cu through a via. The via count comes from the router and changes if the placement changes.

### Annular rings (pad minus drill, per side)

| Item | Ring |
|---|---|
| Signal via 0.8 / 0.4 | 0.20 mm |
| Power via 1.0 / 0.5 | 0.25 mm |
| Jumper pad 1.7 / 1.0 | 0.35 mm |
| KK-396 3.16 × 4.1 / 1.7 | 0.73 mm on the narrow side |

---

## 4. SMD pads (top side)

| Footprint | Parts | Pads each | Pad size (mm) | Shape | Pitch |
|---|---|---|---|---|---|
| R_0805_2012Metric | 45 | 2 | 1.02 × 1.40 | rounded rect | 0805 |
| C_0805_2012Metric | 20 | 2 | 1.00 × 1.45 | rounded rect | 0805 |
| CP_EIA-3216-18_Kemet-A (tantalum) | 2 | 2 | 1.42 × 1.39 | rounded rect | EIA-3216 (A case) |
| CP_Elec_6.3x7.7 (aluminium) | 1 | 2 | 3.50 × 1.60 | rounded rect | 6.3 mm can |
| D_SOD-123 | 11 | 2 | 0.90 × 1.20 | rounded rect | SOD-123 |
| LED_1206_3216Metric | 1 | 2 | 1.25 × 1.75 | rounded rect | 1206 |
| SOT-23 | 11 | 3 | 1.48 × 0.60 | rounded rect | 0.95 mm |
| SOIC-8_3.9x4.9mm | 2 | 8 | 1.95 × 0.60 | rounded rect | 1.27 mm |
| SOIC-14_3.9x8.7mm | 10 | 14 | 1.95 × 0.60 | rounded rect | 1.27 mm |
| SOIC-16_3.9x9.9mm | 3 | 16 | 1.95 × 0.60 | rounded rect | 1.27 mm |
| Potentiometer_Bourns_3314G | 1 | 3 | 1.30 × 1.30 (×2), 2.00 × 1.30 (wiper) | rounded rect | |
| Relay_DPDT_Omron_G6K-2F-Y | 2 | 8 | 1.80 × 0.80 | rectangle | |

**Polarity and pin 1:**
- Diodes and the LED: pad 1 is the cathode.
- Tantalum and aluminium capacitors: pad 1 is the + terminal.
- SOT-23: pads are 1 B, 2 E, 3 C.
- SOIC: pin 1 is marked on the silkscreen.

---

## 5. Routing result (this build)

| Item | Value |
|---|---|
| Unrouted connections | 0 |
| DRC violations | 0 (all severities, including silkscreen) |
| Schematic parity issues | 0 |
| ERC violations | 0 |
| Track segments | 1,704 |
| Vias | 280 (252 at 0.8/0.4 mm, 28 at 1.0/0.5 mm) |

| Track width | F.Cu (top) | B.Cu (bottom) |
|---|---|---|
| 0.25 mm | 865 segments, 3,292 mm | 427 segments, 2,634 mm |
| 0.60 mm | 353 segments, 1,503 mm | 59 segments, 726 mm |
| **Total** | **4,795 mm** | **3,360 mm** |

---

## 6. Mounting holes

The holes are placed the same way as on the through-hole board: 6.35 mm (¼ in) in from each corner, matching the inset measured on the original artwork.

| Ref | X | Y | Corner |
|---|---|---|---|
| H1 | 6.35 | 6.35 | top left |
| H2 | 166.65 | 6.35 | top right |
| H3 | 166.65 | 82.15 | bottom right |
| H4 | 6.35 | 82.15 | bottom left |

| Item | Value |
|---|---|
| Hole | 3.2 mm (0.126 in) unplated, no copper pad |
| Screw | #4 or M3; head and standoff clearance Ø6.9 mm (courtyard) |
| Hole centres, left to right | 160.30 mm (6.311 in) |
| Hole centres, top to bottom | 75.80 mm (2.984 in) |

---

## 7. Power input (external supply)

The supply on `docs/ac30_PS.pdf` is built as a separate unit, exactly as for the through-hole board; see `AC30-settings.md` section 6 for its parts and the transcription notes. Its six outputs plug into **J12**, a 6-pin KK-396 header on the bottom edge.

| J12 pin | Rail | Feeds |
|---|---|---|
| 1 | GND | Common ground |
| 2 | +5V | All logic |
| 3 | +13V | IC15 (1488) pin 14 |
| 4 | −13V | IC15 (1488) pin 1 |
| 5 | +7.5V | IC4 (4558) pin 8 |
| 6 | −7.5V | IC4 (4558) pin 4 |

C23–C25 (0.1 µF 0805) are the on-board +5 V bypass capacitors.

---

## 8. Connectors and front-panel jumper pads

### Molex connectors

J3–J5 and J12 are Molex KK-396 vertical headers (A-41791 series), through-hole, with 3.96 mm (0.156 in) pitch and 1.7 mm holes. Pin 1 is at the left, seen from the component side. J3–J5 pin assignments match the original artwork.

| Ref | Pins | Edge | Pin 1 X | Pin 1 Y | Length, pin 1 to last pin |
|---|---|---|---|---|---|
| J3 (COMP) | 10 | top | 14.20 | 9.10 | 35.64 mm |
| J4 (control) | 15 | top | 58.65 | 9.10 | 55.44 mm |
| J5 (TERM) | 10 | top | 122.95 | 9.10 | 35.64 mm |
| J12 (power input) | 6 | bottom | 130.65 | 80.05 | 19.80 mm |

### Front-panel jumper pads

The SMT board has no front-panel harness connectors. The original J1/J2 KK-396 headers are replaced by five rows of plain through-hole pads along the bottom edge, one row per group of front-panel parts. Solder hook-up wire straight from each pad to the switch, LED or jack.
- Pads are 1.7 mm with 1.0 mm holes at 2.54 mm (0.1 in) pitch (the `PinHeader_1x…_P2.54mm_Vertical` footprints). Pin 1 is square.
- Each pad has its net name on the silkscreen beside it, and the group name is printed above the row.
- Every wire has its own pad. The RECORD A/B (S2) and PLAY A/B (S3) audio poles wire to the SWITCHES row (AUDIO_OUT, MIC_A, MIC_B and AUDIO_IN, EAR_A, EAR_B). The four jacks wire to the MIC and EAR rows, each jack to a tip pad and its own GND pad. The board joins the MIC_x and EAR_x pads of the two rows.

| Ref | Group | Pads | Pin 1 X | Pin 1 Y | Pads, from pin 1 (left) |
|---|---|---|---|---|---|
| J1 | SWITCHES | 19 | 13.60 | 83.70 | +5V, GND, CARRIER_EN_N, MAN_MOTOR, REC_SET, REC_RST, READ_SET, READ_RST, LOCAL_REMOTE, AUDIO_OUT, MIC_A, MIC_B, REC_RLY_DRV, RELAY_1, RELAY_2, READ_RLY_DRV, AUDIO_IN, EAR_A, EAR_B |
| J2 | LEDS | 5 | 66.85 | 83.70 | +5V, LED_REC_RDY, LED_READ_RDY, LED_REC_DATA, LED_READ_DATA |
| J13 | MOTOR | 4 | 84.55 | 83.70 | MOTOR_1A, MOTOR_1B (MOTOR A jack), MOTOR_2A, MOTOR_2B (MOTOR B jack) |
| J14 | MIC | 4 | 99.70 | 83.70 | MIC_A, GND (MIC A jack), MIC_B, GND (MIC B jack) |
| J15 | EAR | 4 | 114.85 | 83.70 | EAR_A, GND (EAR A jack), EAR_B, GND (EAR B jack) |

What each switch pad goes to:

| Front-panel part | Pads |
|---|---|
| S1 MOTOR CONTROL AUTO/MAN | pole 1: CARRIER_EN_N (common), GND (MAN); pole 2: MAN_MOTOR (common), +5V (MAN) |
| S2 RECORD A/B | pole 1: AUDIO_OUT (common), MIC_A (A), MIC_B (B); pole 2: REC_RLY_DRV (common), RELAY_1 (A), RELAY_2 (B) |
| S3 PLAY A/B | pole 1: READ_RLY_DRV (common), RELAY_1 (A), RELAY_2 (B); pole 2: AUDIO_IN (common), EAR_A (A), EAR_B (B) |
| S4 RECORD ON/OFF | +5V (common), REC_SET, REC_RST (momentary) |
| S5 READER ON/OFF | +5V (common), READ_SET, READ_RST (momentary) |
| S7 LOCAL/REMOTE | LOCAL_REMOTE (common), GND |
| LEDs D19–D22 | anodes to the LEDS row +5V; cathodes to LED_REC_RDY, LED_READ_RDY, LED_REC_DATA, LED_READ_DATA |
| Motor jacks J10 / J11 | MOTOR row: MOTOR_1A / 1B (tip / sleeve) and MOTOR_2A / 2B |
| MIC jacks J6 / J7, EAR jacks J8 / J9 | MIC row: MIC_A + GND, MIC_B + GND; EAR row: EAR_A + GND, EAR_B + GND (tip + sleeve) |

---

## 9. SMT parts

Through-hole equivalents are in brackets where the part changed.

| Package | Value | Qty | Refs |
|---|---|---|---|
| R 0805 | 10K | 24 | R2, R3, R9, R11, R12, R15, R19, R20, R21, R22, R27, R28, R29, R32, R33, R34, R36, R40, R41, R42, R44, R45, R46, R47 |
| R 0805 | 100K | 7 | R8, R17, R18, R23, R24, R25, R26 |
| R 0805 | 470 | 6 | R7, R30, R31, R35, R37, R43 |
| R 0805 | 22K | 2 | R13, R14 |
| R 0805 | 33K / 330 / 2.2K / 4.7K / 330K / 47K | 1 each | R1 / R4 / R5 / R6 / R10 / R38 |
| C 0805 | 1000pF | 6 | C1, C6, C12, C13, C14, C15 |
| C 0805 | 470pF | 3 | C11, C19, C20 |
| C 0805 | 0.1uF | 3 | C23, C24, C25 |
| C 0805 | 0.022uF | 2 | C3, C8 |
| C 0805 | 0.01uF | 2 | C5, C18 |
| C 0805 | 0.047uF | 2 | C7, C9 |
| C 0805 | 2000pF / 2700pF | 1 each | C2 / C10 |
| Tantalum EIA-3216 (A) | 1uF 15V / 10uF 10V | 1 each | C4 / C17 |
| Aluminium 6.3 × 7.7 mm | 100uF 16V | 1 | C16 |
| SOD-123 | 1N4148W (1N4148) | 10 | D1, D2, D4, D5, D6, D7, D8, D9, D10, D11 |
| SOD-123 | BZT52C4V7 (1N4732 4.7 V zener) | 1 | D3 |
| LED 1206 | LED (5 mm LED) | 1 | D18 |
| SOT-23 | MMBT5088 (2N5210) | 7 | Q1, Q2, Q4, Q5, Q6, Q7, Q8 |
| SOT-23 | MMBT5087 (2N5087) | 4 | Q3, Q9, Q10, Q11 |
| SOIC-14 | 4013 | 3 | IC1, IC5, IC8 |
| SOIC-14 | 4001 / 4070 | 2 each | IC2, IC11 / IC3, IC13 |
| SOIC-14 | 4023 / 1489 / 1488 | 1 each | IC9 / IC12 / IC15 |
| SOIC-16 | 4053 | 2 | IC6, IC14 |
| SOIC-16 | 4049 | 1 | IC7 |
| SOIC-8 | 4558 / 555 | 1 each | IC4 / IC10 |
| Bourns 3314G | 20K trim (Bourns 3386P) | 1 | R16 |
| Omron G6K-2F-Y | 5 V DPDT relay (6 V SIL reed relay) | 2 | RLY1, RLY2 |
| KK-396 through-hole | 1×6, 1×10, 1×15 headers | 4 | J12, J3 and J5, J4 |
| Through-hole jumper pads (0.1 in) | 1×4, 1×5, 1×19 rows | 5 | J13, J14 and J15, J2, J1 |

**Notes on the substitutions:**
- **Relays:** the KiCad library has no SMD reed relay, so RLY1/RLY2 are Omron G6K-2F-Y signal relays (5 V coil, 1 A contacts). The coil is pins 1/8 and RELAY_x drives pin 1. Both poles (COM 3/6, NO 4/5) are in parallel as the motor contact, and the NC pins 2/7 are unused. **Check the coil polarity mark against the Omron datasheet before ordering.**
- **Transistors:** MMBT5088 is a high-gain, low-noise NPN that stands in for the 2N5210. MMBT5087 is the SMD version of the 2N5087.
- **ICs:** buy the SOIC versions (for example CD4013BM, MC1488D, MC1489D, NE555D, RC4558D). The pinouts are the same as the DIP parts.
- **R39 (200K DELAY trimmer)** is on no schematic and isn't on either board.

---
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

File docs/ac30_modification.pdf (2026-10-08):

Suggested Modifications

In order to prevent damage to the AC-30's reed relays by tape recorders with high motor transient currents, it is suggested that you make the following component additions:
( ) | Insert a 2.2 ohm 1/2 watt resistor in series with the wire going to jack J10 terminal A. Install the resistor right at jack J10.
( ) | Solder a 0.1 mfd capacitor across jack J10 terminals A and B,
( ) | Insert a 2.2 ohm 1/2 watt resistor in series with the wire going to jack J11 terminal A. Install the resistor right at jack J11.
( ) | Solder a 0.1 mfd capacitor across jack J11 terminals A and B.
| If you have easy access to the REMOTE jack terminals on the inside of
the tape recorder, attach a 200 PIV 1 amp diode (04001) across the two terminals. Be sure you install the diode so it is oriented with the banded end to the positive terminal. Use a voltmeter to determine which terminal is which. If you put the diode in backwards, the remote circuit will no longer stop the recorder's motor.

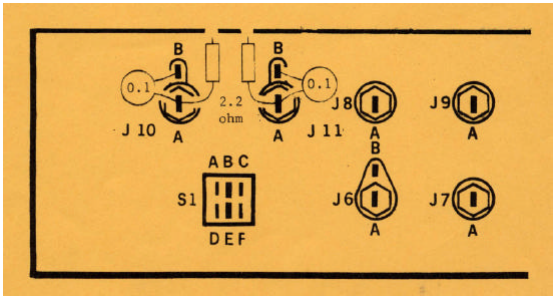
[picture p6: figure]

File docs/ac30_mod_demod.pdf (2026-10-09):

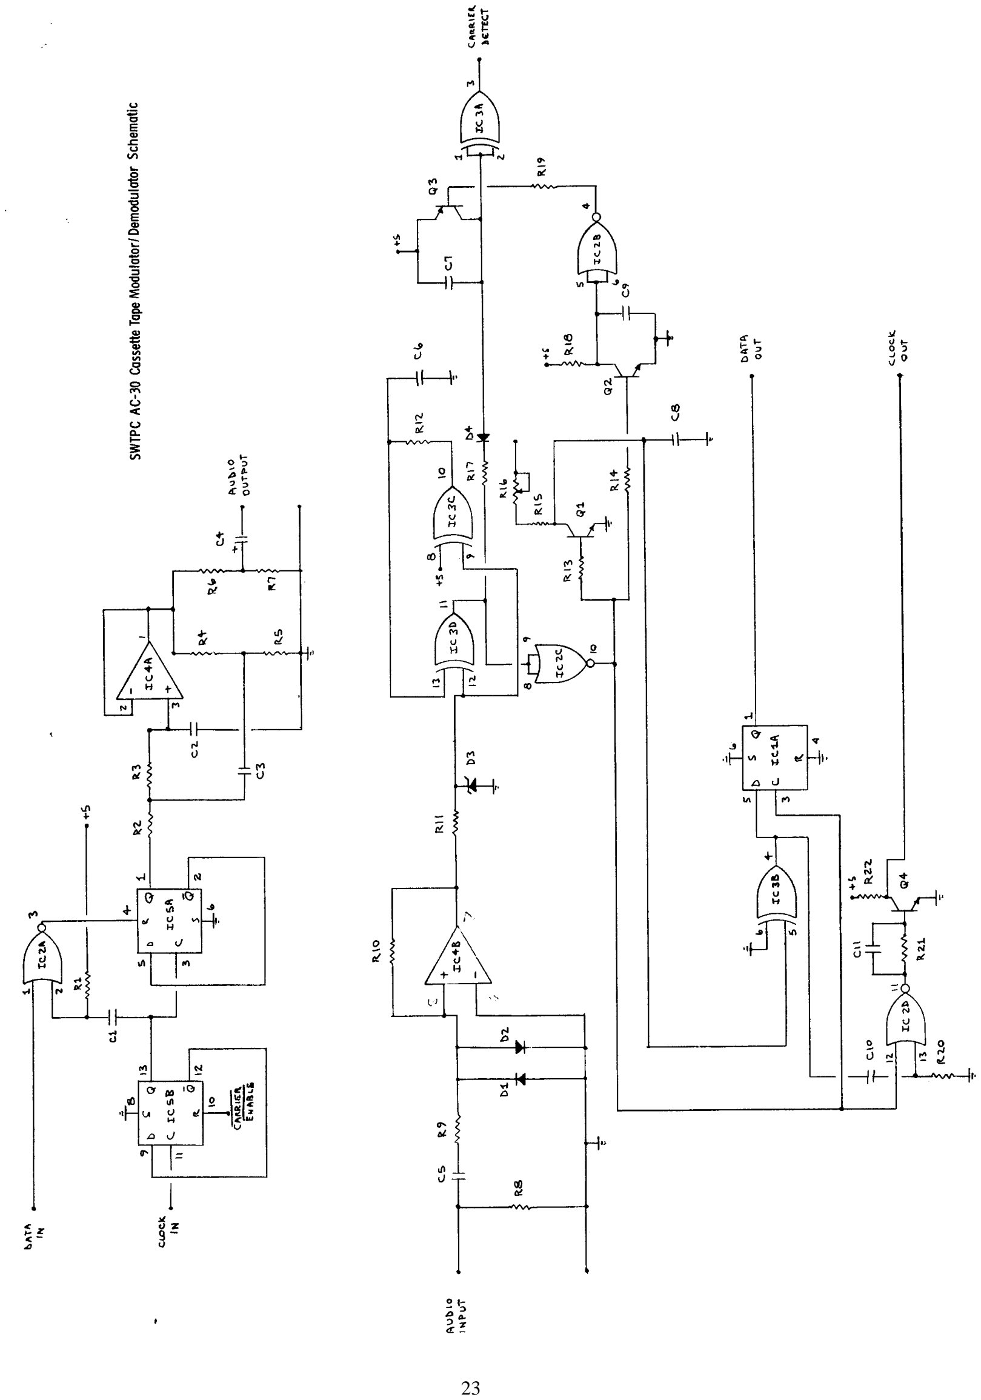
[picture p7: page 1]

23

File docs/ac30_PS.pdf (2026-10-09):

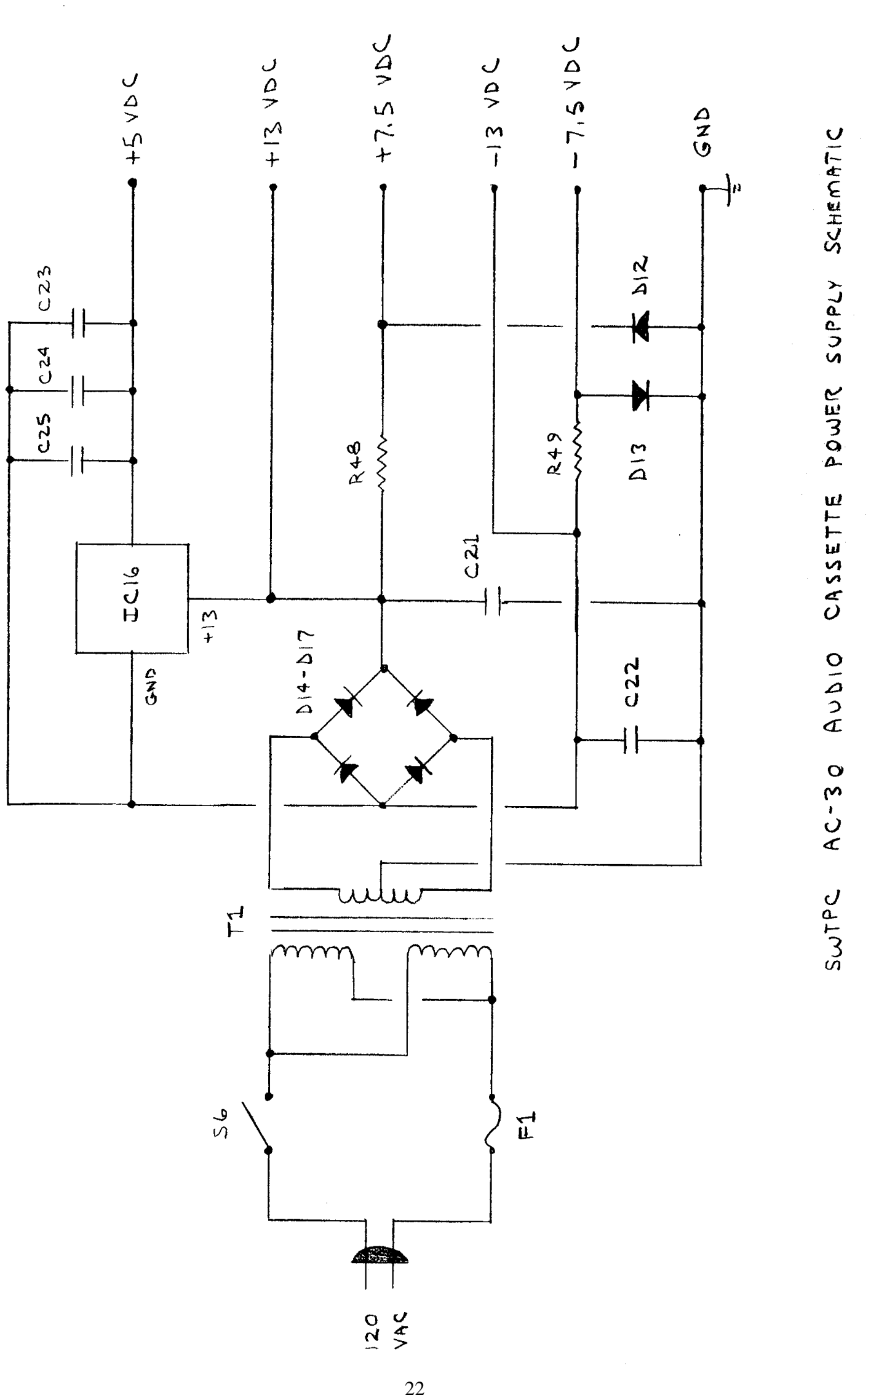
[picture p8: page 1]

22

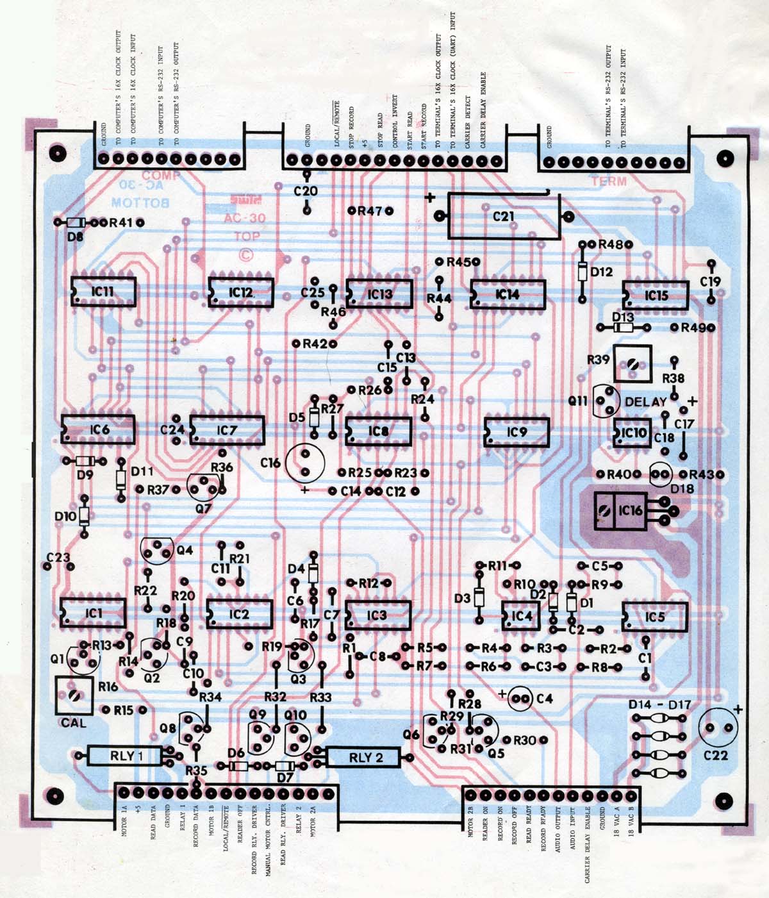
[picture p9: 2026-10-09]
docs/ac30_redblue150.jpg

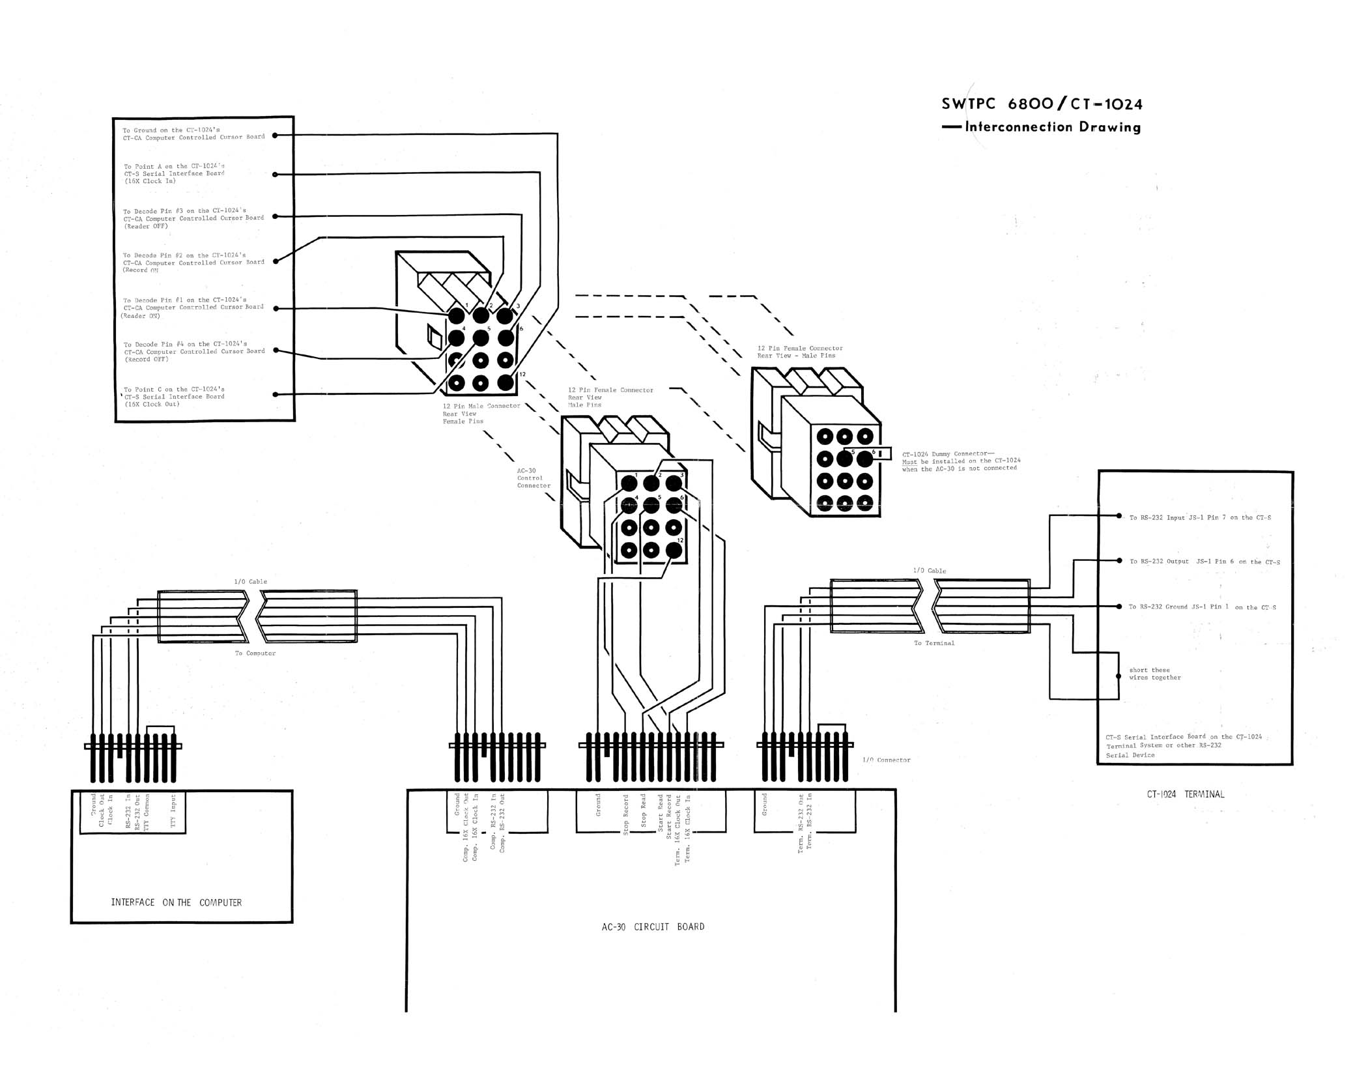
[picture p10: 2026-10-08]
docs/ac30_interconnecta.jpg

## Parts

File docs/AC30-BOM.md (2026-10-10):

# Parts List AC-30 Audio Cassette Interface

## # Resistors

|-----------------------------+----------------------------+---------------------------------------+---|
|                             |                            |                                       |   |
|-----------------------------+----------------------------+---------------------------------------+---|
| R1                          | 33K ohm 1/4 watt resistor  | Mouser Part # 660-MF1/4LCT52R333J %5  |   |
|                             |                            | Mouser Part # 660-MF1/4DCT52R3302F %1 |   |
| R2, R3, R9, R11, R12, R15   | 10K ohm 1/4 watt resistor  |                                       |   |
| R19-R22, R27 R29, R32-R34   | 10K ohm 1/4 watt resistor  |                                       |   |
| R36, R40-R42, R44-R47       | 10K ohm 1/4 watt resistor  |                                       |   |
| R4, R48, R49                | 330 ohm 1/4 watt resistor  | PS R48 R49                            |   |
| R5 2.2K                     | ohm l/4 watt resistor      |                                       |   |
| R6 4.7K                     | ohm 1/4 watt resistor      |                                       |   |
| R7, R30, R31, R35, R37, R43 | 470 ohm 1/4 watt resistor  |                                       |   |
| R8, R17, R18, R23-R26       | 100K ohm 1/4 watt resistor |                                       |   |
| R10                         | 330K ohm 1/4 watt resistor |                                       |   |
| R13, R14                    | 22K ohm 1/4 watt resistor  |                                       |   |
| R16                         | 20K ohm trimmer resistor   |                                       |   |
| R38                         | 47K ohm 1/4 watt resistor  |                                       |   |
| R39                         | 200K ohm trimmer resistor  |                                       |   |
|-----------------------------+----------------------------+---------------------------------------+---|

## Capacitors

|-----------------|-----------------------------------------|----------|---|
|                 |                                         |          |   |
|-----------------|-----------------------------------------|----------|---|
| C1, C6, C12-C15 | 1000 pfd capacitor                      |          |   |
| C2              | 2000 pfd capacitor                      |          |   |
| C3, C8          | O.022 mfd capacitor                     |          |   |
| C4              | 1 mfd @15 VDC electrolytic capacitor    |          |   |
| C5, C18         | 0.01 mfd capacitor                      |          |   |
| C7, C9          | 0.047 mfd capacitor                     |          |   |
| C10             | 2700 pfd capacitor                      |          |   |
| C11, C19, C20   | 470 pfd capacitor                       |          |   |
| C16, C22        | 100 mfd @16 VDC electrolytic capacitor  | PS - C22 |   |
| C17             | 10 mfd @10 VDC tantalum, capacitor      |          |   |
| C21             | 1000 mfd @25 VDC electrolytic capacitor | PS       |   |
| C23-C25         | 0.1 mfd disc capacitor                  | PS       |   |
|-----------------|-----------------------------------------|----------|---|

## Semiconductors

|--------------------+---------------------------------+---------------------+-----|
|                    |                                 |                     |     |
|--------------------+---------------------------------+---------------------+-----|
| ICI, IC5, IC8      | CD4013 dual D flip-flop         | Digi                | ✅ |
| IC2, IC11          | CD4001 quad NOR gate            | Digi                | ✅ |
| IC3, IC13          | CD4070 quad EX-OR gate          | Digi                | ✅ |
| IC4                | CD4558 dual op amp              | EBay                | ✅ |
| IC6, IC14          | CD4053 triple multiplexer       |                     | ✅ |
| IC7                | CD4049 hex buffer               |                     | ✅ |
| IC9                | CD4023 triple 3-input NAND gate |                     | ✅ |
| IC10               | 555 timer                       |                     | ✅ |
| IC12               | 1489 quad RS-232 receiver       |                     | ✅ |
| IC15               | 1488 quad RS-232 transmitter    |                     | ✅ |
| IC16               | 7805 5 VDC regulator            |                     | ✅ |
| D1, D2, D4, D5-D11 | 1N4148 silicon diode            |                     |     |
| D3                 | 4.7 volt zener diode IN5230     | 1N4732 or IN5230    |     |
| D12, D13           | 7.5 volt zener diode 1N4737     | PS 1N4737 or 1N5236 |     |
| D14-D17            | 1N4003 silicon rectifier        | PS                  |     |
| D18-D22            | light emitting diode            |                     |     |
| Q1, Q2, Q4-Q8      | 2N5210 NPN transistor           |                     |     |
| Q3, Q9-Q11         | 2N5087 PNP transistor           |                     |     |
|--------------------+---------------------------------+---------------------+-----|

## Misc.

|------------|-----------------------------------------|-------|---|
|            |                                         |       |   |
|------------|-----------------------------------------|-------|---|
| RLY1, RLY2 | 6 VDC reed relay                        |       |   |
| S1-S3      | DPDT miniature toggle switch            |       |   |
| S4, S5     | SPDT center off miniature toggle switch |       |   |
| S6, S7     | SPDT miniature toggle switch            | PS S6 |   |
| T1         | 18 VAC @300 Ma. secondary 120/240 VAC   | PS    |   |
|            | 50-60 Hz primary power transformer      |       |   |
| F1         | 1 amp standard fuse                     | PS    |   |
|------------|-----------------------------------------|-------|---|

## Reproduction PCB additions (both boards)

These parts aren't on the original parts list above. They come from the reproduction
boards (`kicad/AC30.kicad_pcb` through-hole, `kicad-smt/AC30_SMT.kicad_pcb` SMT).

|-----------------------|--------------------------------------------------|----------------------------------------------|---|
| Ref                   | Part                                             | Notes                                        |   |
|-----------------------|--------------------------------------------------|----------------------------------------------|---|
| J3, J5                | Molex KK-396 1x10 vertical header (A-41791-0010) | COMP and TERM interfaces, top edge           |   |
| J4                    | Molex KK-396 1x15 vertical header (A-41791-0015) | Control interface, top edge                  |   |
| J12                   | Molex KK-396 1x6 vertical header (A-41791-0006)  | Power input from the external supply         |   |
|                       | Molex KK-396 crimp housings and terminals        | One mating housing each for J3, J4, J5, J12  |   |
| J1                    | SWITCHES wire pads, 19 x 0.1 in, 1.0 mm holes    | Front panel; no part, solder wires (*)       |   |
| J2                    | LEDS wire pads, 5 x 0.1 in                       | Front panel; no part, solder wires (*)       |   |
| J13                   | MOTOR wire pads, 4 x 0.1 in                      | Motor jacks J10/J11; no part (*)             |   |
| J14                   | MIC wire pads, 4 x 0.1 in                        | MIC A/B jacks J6/J7; no part (*)             |   |
| J15                   | EAR wire pads, 4 x 0.1 in                        | EAR A/B jacks J8/J9; no part (*)             |   |
| J6-J9                 | Mono phone jack                                  | Front panel: MIC A, MIC B, EAR A, EAR B      |   |
| J10, J11              | Mono phone jack                                  | Front panel: MOTOR A, MOTOR B (remote)       |   |
| C23-C25               | 0.1 mfd capacitor                                | On the board as +5 V bypass, not on the PS   |   |
| H1-H4                 | #4 or M3 screw and standoff                      | 3.2 mm mounting holes, 1/4 in from corners   |   |
|                       | Hook-up wire, 22-24 AWG                          | Front panel to the wire pads                 |   |
|-----------------------|--------------------------------------------------|----------------------------------------------|---|

(*) The wire pads fit a 0.1 in single-row pin header (1x19, 1x5, 1x4) if you'd rather
plug the front panel in than solder it. The original J1/J2 front-panel harness headers
and the J2 18 VAC pins are not used: the power supply is a separate unit.

R39 (200K trimmer) is on the parts list but on no schematic, so it isn't on either board.

## SMT board substitutions

The SMT board (`kicad-smt/AC30_SMT.kicad_pcb`) uses these parts in place of the
through-hole ones. Everything else on the list above is the same, and the connectors,
wire pads, front panel and power supply are identical on both boards.

|------------------------------------|--------------------------------|------------------------------|---|
| Refs                               | SMT part                       | Package                      |   |
|------------------------------------|--------------------------------|------------------------------|---|
| R1-R15, R17-R38, R40-R47           | 1/8 watt resistor, same values | 0805                         |   |
| R16                                | 20K trimmer, Bourns 3314G      | 3314G                        |   |
| C1-C3, C5-C15, C18-C20, C23-C25    | Ceramic capacitor, same values | 0805                         |   |
| C4, C17                            | 1 mfd 15 V / 10 mfd 10 V tant. | EIA-3216 (A case)            |   |
| C16                                | 100 mfd 16 V aluminium         | 6.3 x 7.7 mm can             |   |
| D1, D2, D4-D11                     | 1N4148W                        | SOD-123                      |   |
| D3                                 | BZT52C4V7 4.7 V zener          | SOD-123                      |   |
| D18                                | LED                            | 1206                         |   |
| Q1, Q2, Q4-Q8                      | MMBT5088 (for 2N5210)          | SOT-23                       |   |
| Q3, Q9-Q11                         | MMBT5087                       | SOT-23                       |   |
| IC1-IC3, IC5, IC8, IC9, IC11-IC13, IC15 | SOIC versions (CD4013BM, MC1488D, MC1489D ...) | SOIC-14  |   |
| IC6, IC7, IC14                     | CD4053BM, CD4049UBM            | SOIC-16                      |   |
| IC4, IC10                          | RC4558D, NE555D                | SOIC-8                       |   |
| RLY1, RLY2                         | Omron G6K-2F-Y 5 VDC (for 6 V reed relay) | SMD DPDT, check coil polarity |   |
|------------------------------------|--------------------------------|------------------------------|---|

## KiCad BOM files

`kicad/tools/build.sh` exports a BOM from each schematic on every build:
`kicad/AC30-BOM.csv` (through-hole) and `kicad-smt/AC30_SMT-BOM.csv` (SMT). They list
every part with its value and footprint; front-panel and power-supply parts are marked
"Excluded from board".

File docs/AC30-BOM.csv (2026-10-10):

ID | Part | Number
R1 | 33K ohm 1/4 watt resistor | 1
R2, R3, R9, R11, R12, R15 | 10K ohm 1/4 watt resistor | 6
R19-R22, R27 R29, R32-R34 | 10K ohm 1/4 watt resistor | 10
R36, R40-R42, R44-R47 | 10K ohm 1/4 watt resistor | 8
R4, R48, R49 | 330 ohm 1/4 watt resistor | 3
R5 2.2K | ohm l/4 watt resistor | 1
R6 4.7K | ohm 1/4 watt resistor | 1
R7, R30, R31, R35, R37, R43 | 470 ohm 1/4 watt resistor | 6
R8, R17, R18, R23-R26 | 100K ohm 1/4 watt resistor | 7
R10 | 330K ohm 1/4 watt resistor | 1
R13, R14 | 22K ohm 1/4 watt resistor | 2
R16 | 20K ohm trimmer resistor | 1
R38 | 47K ohm 1/4 watt resistor | 1
R39 | 200K ohm trimmer resistor | 1
C1, C6, C12-C15 | 1000 pfd capacitor 6
C2 | 2000 pfd capacitor | 1
C3, C8 | O.022 mfd capacitor | 2
C4 | 1 mfd @15 VDC electrolytic capacitor | 1
C5, C18 | 0.01 mfd capacitor | 2
C7, C9 | 0.047 mfd capacitor | 2
C10 | 2700 pfd capacitor | 1
C11, C19, C20 | 470 pfd capacitor | 3
C16, C22 | 100 mfd @16 VDC electrolytic capacitor | 2
C17 | 10 mfd @10 VDC tantalum, capacitor | 1
C21 | 1000 mfd @25 VDC electrolytic capacitor | 1
C23-C25 | 0.1 mfd disc capacitor | 3
ICI, IC5, IC8 | CD4013 dual D flip-flop | 3
IC2, IC11 | 4001 quad NOR gate | 2
IC3, IC13 | 4070 quad EX-OR gate | 2
IC4 | 4558 dual op amp | 1
IC6, IC14 | CD4053 triple multiplexer | 1
IC7 | 4049 hex buffer | 1
IC9 | 4023 triple 3-input NAND gate | 1
IC10 | 555 timer | 1
IC12 | 1489 quad RS-232 receiver | 1
IC15 | 1488 quad RS-232 transmitter | 1
IC16 | 7805 5 VDC regulator | 1
D1, D2, D4, D5-D11 | 1N4148 silicon diode | 10
D3 | 4.7 volt zener diode 1N4732 or IN523 | 1
D12, D13 | 7.5 volt zener diode 1N4737 or 1N523 | 2
D14-D17 | 1N4003 silicon rectifier | 4
D18-D22 | light emitting diode | 5
Q1, Q2, Q4-Q8 | 2N5210 NPN transistor | 7
Q3, Q9-Q11 | 2N5087 PNP transistor | 4
RLY1, RLY2 | 6 VDC reed relay | 2
S1-S3 | DPDT miniature toggle switch | 3
S4, S5 | SPDT center off miniature toggle switch | 2
S6, S7 | SPDT miniature toggle switch | 2
T1 | 18 VAC @300 Ma. secondary 120/240 VAC 50-60 Hz primary power transformer | 1
F1 | 1 amp standard fuse | 1
J3, J5 | Molex KK-396 1x10 vertical header (A-41791-0010) | 2
J4 | Molex KK-396 1x15 vertical header (A-41791-0015) | 1
J12 | Molex KK-396 1x6 vertical header (A-41791-0006) | 1
J1, J2, J13-J15 | Front panel wire pads (no part; optional 0.1 in header 1x19, 1x5, 1x4 x3) | 5
J6-J9 | Mono phone jack (MIC A, MIC B, EAR A, EAR B) | 4
J10, J11 | Mono phone jack (MOTOR A, MOTOR B) | 2
H1-H4 | #4 or M3 screw and standoff | 4

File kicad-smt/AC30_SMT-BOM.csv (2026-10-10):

Reference | Value | Footprint | Qty | Excluded from board
C1,C6,C12,C13,C14,C15 | 1000pF | Capacitor_SMD:C_0805_2012Metric | 6
C2 | 2000pF | Capacitor_SMD:C_0805_2012Metric | 1
C3,C8 | 0.022uF | Capacitor_SMD:C_0805_2012Metric | 2
C4 | 1uF 15V | Capacitor_Tantalum_SMD:CP_EIA-3216-18_Kemet-A | 1
C5,C18 | 0.01uF | Capacitor_SMD:C_0805_2012Metric | 2
C7,C9 | 0.047uF | Capacitor_SMD:C_0805_2012Metric | 2
C10 | 2700pF | Capacitor_SMD:C_0805_2012Metric | 1
C11,C19,C20 | 470pF | Capacitor_SMD:C_0805_2012Metric | 3
C16 | 100uF 16V | Capacitor_SMD:CP_Elec_6.3x7.7 | 1
C17 | 10uF 10V tant | Capacitor_Tantalum_SMD:CP_EIA-3216-18_Kemet-A | 1
C21 | 1000uF 25V |  | 1 | Excluded from board
C22 | 100uF 16V |  | 1 | Excluded from board
C23,C24,C25 | 0.1uF | Capacitor_SMD:C_0805_2012Metric | 3
D1,D2,D4,D5,D6,D7,D8,D9,D10,D11 | 1N4148W | Diode_SMD:D_SOD-123 | 10
D3 | BZT52C4V7 4.7V | Diode_SMD:D_SOD-123 | 1
D12,D13 | 1N4737 7.5V |  | 2 | Excluded from board
D14,D15,D16,D17 | 1N4003 |  | 4 | Excluded from board
D18 | LED | LED_SMD:LED_1206_3216Metric | 1
D19 | RECORD RDY |  | 1 | Excluded from board
D20 | READ RDY |  | 1 | Excluded from board
D21 | REC DATA |  | 1 | Excluded from board
D22 | READ DATA |  | 1 | Excluded from board
F1 | 1A |  | 1 | Excluded from board
IC1,IC5,IC8 | 4013 | Package_SO:SOIC-14_3.9x8.7mm_P1.27mm | 3
IC2,IC11 | 4001 | Package_SO:SOIC-14_3.9x8.7mm_P1.27mm | 2
IC3,IC13 | 4070 | Package_SO:SOIC-14_3.9x8.7mm_P1.27mm | 2
IC4 | 4558 | Package_SO:SOIC-8_3.9x4.9mm_P1.27mm | 1
IC6,IC14 | 4053 | Package_SO:SOIC-16_3.9x9.9mm_P1.27mm | 2
IC7 | 4049 | Package_SO:SOIC-16_3.9x9.9mm_P1.27mm | 1
IC9 | 4023 | Package_SO:SOIC-14_3.9x8.7mm_P1.27mm | 1
IC10 | 555 | Package_SO:SOIC-8_3.9x4.9mm_P1.27mm | 1
IC12 | 1489 | Package_SO:SOIC-14_3.9x8.7mm_P1.27mm | 1
IC15 | 1488 | Package_SO:SOIC-14_3.9x8.7mm_P1.27mm | 1
IC16 | 7805 |  | 1 | Excluded from board
J1 | SWITCHES | Connector_PinHeader_2.54mm:PinHeader_1x19_P2.54mm_Vertical | 1
J2 | LEDS | Connector_PinHeader_2.54mm:PinHeader_1x05_P2.54mm_Vertical | 1
J3 | Computer interface (COMP) | Connector_Molex:Molex_KK-396_A-41791-0010_1x10_P3.96mm_Vertical | 1
J4 | Control interface | Connector_Molex:Molex_KK-396_A-41791-0015_1x15_P3.96mm_Vertical | 1
J5 | Terminal interface (TERM) | Connector_Molex:Molex_KK-396_A-41791-0010_1x10_P3.96mm_Vertical | 1
J6 | MIC A |  | 1 | Excluded from board
J7 | MIC B |  | 1 | Excluded from board
J8 | EAR A |  | 1 | Excluded from board
J9 | EAR B |  | 1 | Excluded from board
J10 | MOTOR A |  | 1 | Excluded from board
J11 | MOTOR B |  | 1 | Excluded from board
J12 | Power input | Connector_Molex:Molex_KK-396_A-41791-0006_1x06_P3.96mm_Vertical | 1
J13 | MOTOR | Connector_PinHeader_2.54mm:PinHeader_1x04_P2.54mm_Vertical | 1
J14 | MIC | Connector_PinHeader_2.54mm:PinHeader_1x04_P2.54mm_Vertical | 1
J15 | EAR | Connector_PinHeader_2.54mm:PinHeader_1x04_P2.54mm_Vertical | 1
P1 | 120 VAC line cord |  | 1 | Excluded from board
Q1,Q2,Q4,Q5,Q6,Q7,Q8 | MMBT5088 | Package_TO_SOT_SMD:SOT-23 | 7
Q3,Q9,Q10,Q11 | MMBT5087 | Package_TO_SOT_SMD:SOT-23 | 4
R1 | 33K | Resistor_SMD:R_0805_2012Metric | 1
R2,R3,R9,R11,R12,R15,R19,R20,R21,R22,R27,R28,R29,R32,R33,R34,R36,R40,R41,R42,R44,R45,R46,R47 | 10K | Resistor_SMD:R_0805_2012Metric | 24
R4 | 330 | Resistor_SMD:R_0805_2012Metric | 1
R5 | 2.2K | Resistor_SMD:R_0805_2012Metric | 1
R6 | 4.7K | Resistor_SMD:R_0805_2012Metric | 1
R7,R30,R31,R35,R37,R43 | 470 | Resistor_SMD:R_0805_2012Metric | 6
R8,R17,R18,R23,R24,R25,R26 | 100K | Resistor_SMD:R_0805_2012Metric | 7
R10 | 330K | Resistor_SMD:R_0805_2012Metric | 1
R13,R14 | 22K | Resistor_SMD:R_0805_2012Metric | 2
R16 | 20K trim | Potentiometer_SMD:Potentiometer_Bourns_3314G_Vertical | 1
R38 | 47K | Resistor_SMD:R_0805_2012Metric | 1
R48,R49 | 330 |  | 2 | Excluded from board
RLY1,RLY2 | G6K-2F-Y 5V | Relay_SMD:Relay_DPDT_Omron_G6K-2F-Y | 2
S1 | AUTO/MAN |  | 1 | Excluded from board
S2 | RECORD A/B |  | 1 | Excluded from board
S3 | PLAY A/B |  | 1 | Excluded from board
S4 | RECORD ON/OFF |  | 1 | Excluded from board
S5 | READER ON/OFF |  | 1 | Excluded from board
S6 | POWER (SPDT, one throw used) |  | 1 | Excluded from board
S7 | LOCAL/REMOTE |  | 1 | Excluded from board
T1 | 120/240V : 18VAC CT 300mA |  | 1 | Excluded from board

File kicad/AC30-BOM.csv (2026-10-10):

Reference | Value | Footprint | Qty | Excluded from board
C1,C6,C12,C13,C14,C15 | 1000pF | Capacitor_THT:C_Disc_D5.0mm_W2.5mm_P5.00mm | 6
C2 | 2000pF | Capacitor_THT:C_Disc_D5.0mm_W2.5mm_P5.00mm | 1
C3,C8 | 0.022uF | Capacitor_THT:C_Disc_D5.0mm_W2.5mm_P5.00mm | 2
C4 | 1uF 15V | Capacitor_THT:CP_Radial_D6.3mm_P2.50mm | 1
C5,C18 | 0.01uF | Capacitor_THT:C_Disc_D5.0mm_W2.5mm_P5.00mm | 2
C7,C9 | 0.047uF | Capacitor_THT:C_Disc_D5.0mm_W2.5mm_P5.00mm | 2
C10 | 2700pF | Capacitor_THT:C_Disc_D5.0mm_W2.5mm_P5.00mm | 1
C11,C19,C20 | 470pF | Capacitor_THT:C_Disc_D5.0mm_W2.5mm_P5.00mm | 3
C16 | 100uF 16V | Capacitor_THT:CP_Radial_D10.0mm_P5.00mm | 1
C17 | 10uF 10V tant | Capacitor_THT:CP_Radial_D6.3mm_P2.50mm | 1
C21 | 1000uF 25V |  | 1 | Excluded from board
C22 | 100uF 16V |  | 1 | Excluded from board
C23,C24,C25 | 0.1uF | Capacitor_THT:C_Disc_D5.0mm_W2.5mm_P5.00mm | 3
D1,D2,D4,D5,D6,D7,D8,D9,D10,D11 | 1N4148 | Diode_THT:D_DO-35_SOD27_P7.62mm_Horizontal | 10
D3 | 1N4732 4.7V | Diode_THT:D_DO-35_SOD27_P7.62mm_Horizontal | 1
D12,D13 | 1N4737 7.5V |  | 2 | Excluded from board
D14,D15,D16,D17 | 1N4003 |  | 4 | Excluded from board
D18 | LED | LED_THT:LED_D5.0mm | 1
D19 | RECORD RDY |  | 1 | Excluded from board
D20 | READ RDY |  | 1 | Excluded from board
D21 | REC DATA |  | 1 | Excluded from board
D22 | READ DATA |  | 1 | Excluded from board
F1 | 1A |  | 1 | Excluded from board
IC1,IC5,IC8 | 4013 | Package_DIP:DIP-14_W7.62mm | 3
IC2,IC11 | 4001 | Package_DIP:DIP-14_W7.62mm | 2
IC3,IC13 | 4070 | Package_DIP:DIP-14_W7.62mm | 2
IC4 | 4558 | Package_DIP:DIP-8_W7.62mm | 1
IC6,IC14 | 4053 | Package_DIP:DIP-16_W7.62mm | 2
IC7 | 4049 | Package_DIP:DIP-16_W7.62mm | 1
IC9 | 4023 | Package_DIP:DIP-14_W7.62mm | 1
IC10 | 555 | Package_DIP:DIP-8_W7.62mm | 1
IC12 | 1489 | Package_DIP:DIP-14_W7.62mm | 1
IC15 | 1488 | Package_DIP:DIP-14_W7.62mm | 1
IC16 | 7805 |  | 1 | Excluded from board
J1 | SWITCHES | Connector_PinHeader_2.54mm:PinHeader_1x19_P2.54mm_Vertical | 1
J2 | LEDS | Connector_PinHeader_2.54mm:PinHeader_1x05_P2.54mm_Vertical | 1
J3 | Computer interface (COMP) | Connector_Molex:Molex_KK-396_A-41791-0010_1x10_P3.96mm_Vertical | 1
J4 | Control interface | Connector_Molex:Molex_KK-396_A-41791-0015_1x15_P3.96mm_Vertical | 1
J5 | Terminal interface (TERM) | Connector_Molex:Molex_KK-396_A-41791-0010_1x10_P3.96mm_Vertical | 1
J6 | MIC A |  | 1 | Excluded from board
J7 | MIC B |  | 1 | Excluded from board
J8 | EAR A |  | 1 | Excluded from board
J9 | EAR B |  | 1 | Excluded from board
J10 | MOTOR A |  | 1 | Excluded from board
J11 | MOTOR B |  | 1 | Excluded from board
J12 | Power input | Connector_Molex:Molex_KK-396_A-41791-0006_1x06_P3.96mm_Vertical | 1
J13 | MOTOR | Connector_PinHeader_2.54mm:PinHeader_1x04_P2.54mm_Vertical | 1
J14 | MIC | Connector_PinHeader_2.54mm:PinHeader_1x04_P2.54mm_Vertical | 1
J15 | EAR | Connector_PinHeader_2.54mm:PinHeader_1x04_P2.54mm_Vertical | 1
P1 | 120 VAC line cord |  | 1 | Excluded from board
Q1,Q2,Q4,Q5,Q6,Q7,Q8 | 2N5210 | Package_TO_SOT_THT:TO-92_Inline | 7
Q3,Q9,Q10,Q11 | 2N5087 | Package_TO_SOT_THT:TO-92_Inline | 4
R1 | 33K | Resistor_THT:R_Axial_DIN0207_L6.3mm_D2.5mm_P10.16mm_Horizontal | 1
R2,R3,R9,R11,R12,R15,R19,R20,R21,R22,R27,R28,R29,R32,R33,R34,R36,R40,R41,R42,R44,R45,R46,R47 | 10K | Resistor_THT:R_Axial_DIN0207_L6.3mm_D2.5mm_P10.16mm_Horizontal | 24
R4 | 330 | Resistor_THT:R_Axial_DIN0207_L6.3mm_D2.5mm_P10.16mm_Horizontal | 1
R5 | 2.2K | Resistor_THT:R_Axial_DIN0207_L6.3mm_D2.5mm_P10.16mm_Horizontal | 1
R6 | 4.7K | Resistor_THT:R_Axial_DIN0207_L6.3mm_D2.5mm_P10.16mm_Horizontal | 1
R7,R30,R31,R35,R37,R43 | 470 | Resistor_THT:R_Axial_DIN0207_L6.3mm_D2.5mm_P10.16mm_Horizontal | 6
R8,R17,R18,R23,R24,R25,R26 | 100K | Resistor_THT:R_Axial_DIN0207_L6.3mm_D2.5mm_P10.16mm_Horizontal | 7
R10 | 330K | Resistor_THT:R_Axial_DIN0207_L6.3mm_D2.5mm_P10.16mm_Horizontal | 1
R13,R14 | 22K | Resistor_THT:R_Axial_DIN0207_L6.3mm_D2.5mm_P10.16mm_Horizontal | 2
R16 | 20K trim | Potentiometer_THT:Potentiometer_Bourns_3386P_Vertical | 1
R38 | 47K | Resistor_THT:R_Axial_DIN0207_L6.3mm_D2.5mm_P10.16mm_Horizontal | 1
R48,R49 | 330 |  | 2 | Excluded from board
RLY1,RLY2 | 6V reed relay | Relay_THT:Relay_SPST_StandexMeder_SIL_Form1A | 2
S1 | AUTO/MAN |  | 1 | Excluded from board
S2 | RECORD A/B |  | 1 | Excluded from board
S3 | PLAY A/B |  | 1 | Excluded from board
S4 | RECORD ON/OFF |  | 1 | Excluded from board
S5 | READER ON/OFF |  | 1 | Excluded from board
S6 | POWER (SPDT, one throw used) |  | 1 | Excluded from board
S7 | LOCAL/REMOTE |  | 1 | Excluded from board
T1 | 120/240V : 18VAC CT 300mA |  | 1 | Excluded from board

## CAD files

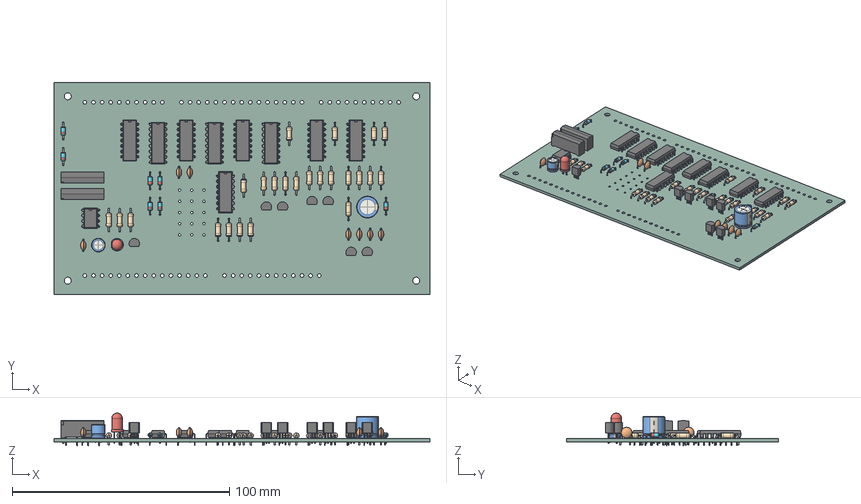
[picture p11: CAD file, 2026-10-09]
AC30-Kicad/AC30.step
173.0 x 97.5 x 15.1 mm
TO-92_Inline_Narrow x 7
DIP-16_W7.62mm x 3
DIP-14_W7.62mm x 6
R_Axial_DIN0207_L63mm_D25mm_P1016mm_Horizontal x 24
LED_D5.0mm
C_Disc_D50mm_W25mm_P500mm x 7
CP_Radial_D63mm_P250mm
D_DO-35_SOD27_P7.62mm_Horizontal x 7
Relay_SPST_StandexMeder_SIL_Form1A x 2
DIP-8_W7.62mm
CP_Radial_D100mm_P500mm
AC30_PCB

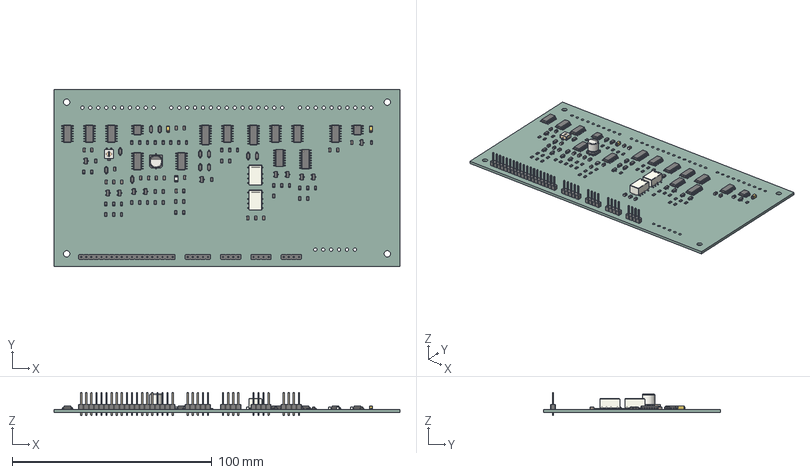
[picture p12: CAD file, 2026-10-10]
kicad-smt/AC30_SMT.step
173.0 x 88.5 x 11.5 mm
SOT-23 x 11
SOIC-16_3.9x9.9mm_P1.27mm x 3
SOIC-14_3.9x8.7mm_P1.27mm x 10
R_0805_2012Metric x 45
CP_EIA_3216_18_Kemet_A x 2
PinHeader_1x05_P254mm_Vertical
SOIC-8_3.9x4.9mm_P1.27mm x 2
LED_1206_3216Metric
C_0805_2012Metric x 20
Potentiometer_Bourns_3314G_Vertical
D_SOD-123 x 11
PinHeader_1x04_P254mm_Vertical x 3
Relay_DPDT_Omron_G6K-2F-Y x 2
CP_Elec_63x77
PinHeader_1x19_P254mm_Vertical
AC30_SMT_PCB

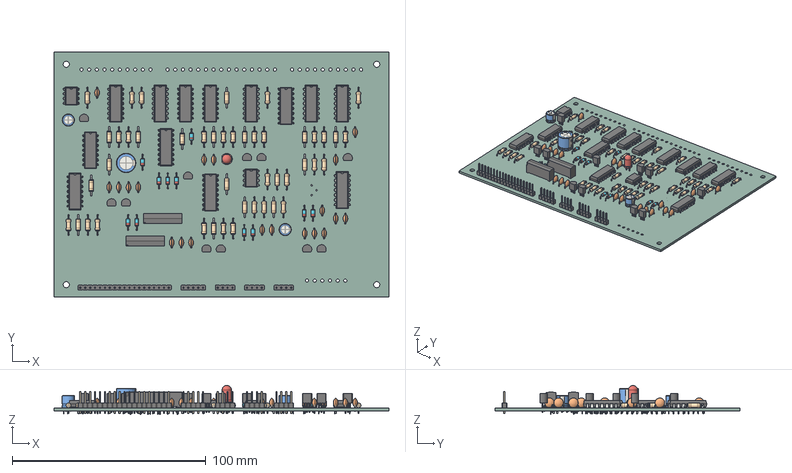
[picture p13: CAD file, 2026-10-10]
kicad/AC30.step
173.0 x 126.5 x 15.1 mm
TO-92_Inline_Narrow x 11
DIP-16_W7.62mm x 3
DIP-14_W7.62mm x 10
R_Axial_DIN0207_L63mm_D25mm_P1016mm_Horizontal x 45
CP_Radial_D63mm_P250mm x 2
PinHeader_1x05_P254mm_Vertical
DIP-8_W7.62mm x 2
LED_D5.0mm
C_Disc_D50mm_W25mm_P500mm x 20
D_DO-35_SOD27_P7.62mm_Horizontal x 11
PinHeader_1x04_P254mm_Vertical x 3
Relay_SPST_StandexMeder_SIL_Form1A x 2
CP_Radial_D100mm_P500mm
PinHeader_1x19_P254mm_Vertical
AC30_PCB

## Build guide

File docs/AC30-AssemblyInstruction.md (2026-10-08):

# Assembly Instructions AC-30 Audio Cassette Interface

## Introduction

Southwest Technical Products Corporation Document Circa 1976 

Cassette tape is one of the most flexible and least expensive means of mass
data storage for computer systems. When compared to paper tape readers and punches,
you'll find that although the paper tape readers can be made rather inexpensively,
the punches cannot. Paper tape systems are typically slower and the punched tapes
cannot of course be repunched and used over and over again, as you can with
cassettes. Disk systems on the other hand offer significant advantages over
cassettes but are still too expensive for many applications, and for most
hobbyists. Even those lucky enough to have a disk system still need a more
universal medium for exchanging programs.

Although there are several commercial digital cassette tape decks on the
market today, recording techniques vary and they are of course much more expensive
than the average audio cassette unit. As could be expected most hobbyist computer
system mass data storage designs have been based on the audio cassette recorder.
The use of inconsistent recording techniques among the various manufacturers
makes it impossible for example to record a program, or data tape on a SWTPC 6800
Computer System and play it back on a MITS 680 Computer System. In order to
coordinate manufacturer design efforts, and exploit the most effective recording
technique, BYTE Magazine of Peterborough, New Hampshire, 03458 held a symposium in
the Fall of 1975 in Kansas City in an attempt to establish a recording standard for
the storage of digital data on audio cassette recorders. The standard which was
adopted has been tested and fully supported by Southwest Technical Products
Corporation. It appears to be the best compromise between economy and reliability.
Although complete details are contained in the Feb., 1976 issue of BYTE Magazine,
the recording philosophy is to record data serially using the standard UART format
at 300 baud (30 characters/second). Marks or logic ones are represented by
recording a 2400 Hz sine wave on the tape while spaces or logic zeroes are
represented by recording a 1200 Hz sine wave. With the proper circuitry this
recorded data can then be read off the tape and transposed into a self clocking
UART based tare system which will tolerate audio recorder speed variations of
approximately +30%. This figure is far better than that of most other modulation
techniques and is a real advantage when you consider the degree of worst case speed
variation between inexpensive audio recorders. In addition we have speed variations
due to line voltage, battery voltage, wow and flutter, mechanism wear, etc. Thus
evolved the "Kansas City" standard. It should be noted that the standard does not
specify how the data is to be organized on the tape, so there can, and probably
will be some incompatibility among various manufacturer's units. This is however
more of a software problem than a hardware problem and thus a little easier to
resolve.

Although the SWTPC AC-30 Audio Cassette Interface has been used extensively
with the SWTPC 6800 Computer System and CT-1024 (TV Typewriter II) Terminal System,
it has been designed to be as universal and flexible a system as possible. If your
computer's control terminal is interfaced to the computer thru 300 baud, RS-232
compatible serial interfaces with accessible UART type 16 X baud rate clocks on
both computer and terminal, the SWTPC AC-30 Cassette Interface Unit is simply
plugged between the computer and terminal interfaces. This is the ideal mode of
operation since the cassette unit can take full advantage of computer resident tape
load and dump routines and requires no additional interfaces. Switching the
cassette unit to the LOCAL mode directly interconnects the terminal and cassette
unit for terminal "only" cassette tape operation just like the LOCAL mode of
operation on teletypewriters. While operating in the REMOTE mode the computer
communicates with both the terminal and cassette unit, here again just like the
REMOTE mode of operation on teletypewriters. Those customers using the CT-1024 (TV
Typewriter II) Terminal System or any terminal system with accessible control
character decoders may even pick Reader ON (Control Q), Reader OFF (Control S),
Record On (Control R), and Record OFF (Control T) control commands right off the
control character decoder circuitry on their terminal system giving the computer
system program control over cassette recorder data flow and even motor operation.
Those not having access to decoded control commands may still have cassette control
by driving the cassette interface with control lines from a separate parallel
interface option located on the attached computer system.

Those users not operating their control terminal RS-232 serial at 300 baud or
not having access to their terminal's 16 X UART clock may still use the cassette
interface, but must attach it to the computer system thru a separate RS-232 serial
300 baud interface with accessible 16 X clocks located on the computer system. This
however eliminates the ability to use the computer resident control terminal tape
load and dump routines as well as the LOCAL/REMOTE feature described previously.
The cassette interface circuitry is constructed on a 7 3/4" X 7 1/2" double
sided, plated thru hole fiberglass circuit board with all electrical connections
made to the board thru one of the five edge connectors. The three connectors along
the back edge of the circuit board are for connections to the computer, control
decoder and terminal while the two along the front edge are for connections to the
cassette interface's control panel. The PC board in turn is mounted inside a 12
3/4" wide X 3" high X 11" deep aluminum chassis with dress panel and perforated
cover.

## PC Board Assembly

*NOTE*: Since all of the holes on the PC board have been plated thru, it is
only necessary to solder the components from the bottom side of the board. The
plating provides the electrical connection from the "BOTTOM" to the "TOP" foil of
each hole. Unless otherwise noted it is important that none of the connections be
soldered until all of the components of each group have been installed on the
board. This makes it much easier to interchange components if a mistake is made
during assembly. Be sure to use a low wattage iron (not a gun) with a small tip. Do
not use acid core solder or any type of paste flux. We will not guarantee or repair
any kit on which either product has been used. Use only the solder supplied with
the kit or a 60/40 alloy resin core equivalent. Remember all of the connections are
soldered on the bottom side of the board only. The plated-thru holes provide the
electrical connection to the top foil. 

- ( ) Before installing any parts on the circuit board, check both sides of the
board over carefully for incomplete etching and foil "bridges" or "breaks".
It is unlikely that you will find any but should there be one especially on
the "TOP" side of the board it will be very hard to locate and correct after
all of the components have been installed on the board.

- ( ) Attach all of the resistors to the board. As with all other components unless
noted, use the parts list and component layout drawing to locate each part
and install from the "TOP" side of the board bending the leads along the
"BOTTOM" side of the board and trimming so that 1/16" to 1/8" of wire
remains. Solder. You may find that there are no pads on the "BOTTOM" side of
the board for resistor R42. If not be sure its two leads are soldered from
the "TOP" side of the board.

- ( ) Install all of the capacitors on the board. Be sure to orient the
electrolytic capacitors correctly. The polarity is indicated on the component
layout drawing. The body of electrolytic capacitor C21 should be insulated so
as not to "short" to foil conductors under it. If the body of the capacitor
is not insulated attach the capacitor so it is up off the board about 1/8".
Solder.
- ( ) Starting from one end of the circuit board install each of the five Molex
female edge connectors along the edges of the board. These connectors must be
inserted from the "TOP" side of the board and must be pressed down firmly
against the board. Make sure the body of the connector seats firmly against
the circuit board and that each pin extends completely into the holes on the
circuit board.
- ( ) Insert the small nylon indexing plugs into the edge connector pins indicated
by the small triangular arrows on the "BOTTOM" side of the circuit board.
This prevents mating plugs from being accidentally plugged onto the board
incorrectly.
- ( ) Install the transistors on the board. The transistors must be turned to match
the outlines on the component layout drawing. Solder.
- ( ) Install all of the diodes on the board excluding diodes D18 thru D22. The
diodes must be turned to match the outlines on the component layout drawing.
Solder.
- ( ) Install LED diode D18 on the circuit board. Be sure the flat on the side of
the LED matches that shown on the component layout drawing. Attach the diode
so the bottom of its case is 1/8" to 1/4" above the top of the board. Solder.
- ( ) Install reed relays RLY1 and RLY2 on the circuit board. These relays are not
polarized so they need not be oriented in any particular position other than
matching the end with three leads and the one with just one to the respective
holes on the circuit board. Solder.
- ( ) Install integrated circuit IC16 on the circuit board. This component must be
oriented so its metal face is facing the circuit board. The IC is secured to
the circuit board with a #4-40 X 1/4" screw, lockwasher and nut. The three
leads of the integrated circuit must be bent down into each of their
respective holes and trimmed. Solder.

NOTE: Most of the integrated circuits used in this kit are CMOS and are
susceptible to damage by static electricity. Although some degree of protection is
provided internally within the integrated circuits, their sensitivity demands the
utmost in care. Before opening and/or installing any CMOS integrated circuits you
should ground your body and all metallic tools coming into contact with the leads,
thru a 1 M ohm 1/4 watt resistor (supplied with the kit). The ground must be an
"earth" ground such as a water pipe, and not the circuit board ground. As for the 
connection to your body, attach a clip lead to your watch or metal ID bracelet.
Make absolutely sure you have the 1 Meg ohm resistor connected between you and the
"earth" ground, otherwise you will be creating a dangerous shock hazard. Avoid
touching the leads of the integrated circuits any more than necessary when
installing them, even if you are grounded. On those MOS IC's being soldered in
place; the tip of the soldering iron should be grounded as well (separately from
your body ground) either with or without a 1 Meg ohm resistor. Most soldering irons
having a three prong line cord plug already have a grounded tip. Static electricity
should be an important consideration in cold, dry environments. It is less of a
problem when it is warm and humid.

- ( ) Install integrated circuits ICI thru IC15 following the precautions given in
the preceding section. As each is installed, make sure it is down firmly
against the board before soldering all of its leads. Be very careful to
install each in its correct position. Do not bend the leads on the back side
of the board. Doing so makes it very difficult to remove the integrated
circuits should replacement ever be necessary. The "dot" on the end of the
package is used for orientation purposes and must match with that shown on
the component layout drawing for each of the IC's.

- ( ) Working from the "TOP" side of 'the circuit board, fill in all of the
feed-thru's with molten solder. The feed-thru's are those unused holes on the
board whose internal plating connects the "TOP" and "BOTTOM" circuit
connections. Filling these feed-thru's with molten solder guarantees the
integrity of the connections and increases the current handling capability.
- ( ) Now that most of the components have been installed on the board, double
check to make sure all have been installed correctly in their proper
location.
- ( ) Check very carefully to make sure that all connections have been soldered. It
is very easy to miss some connections when soldering which can really cause
some hard to find problems later during check out. Also look for solder
"bridges" and "cold" solder joints which are another common problem.
Since the circuit board now contains CMOS devices it is susceptible to damage
from severe static electrical sources. One should avoid handling the board any more
than necessary and when you must, avoid touching or allowing anything to come into
contact with any of the conductors on the board. 

## Parts List AC-30 Audio Cassette Interface

### # Resistors

R1 33K ohm 1/4 watt resistor
R2, R3, R9, R11, R12, R15 10K ohm 1/4 watt resistor
R19-R22, R27 R29, R32-R34, 10K ohm 1/4 watt resistor
R36, R40-R42, R44-R47 10K ohm 1/4 watt resistor
R4, R48, R49 330 ohm 1/4 watt resistor
R5 2.2K ohm l/4 watt resistor
R6 4.7K ohm 1/4 watt resistor
R7, R30, R31, R35, R37, R43 470 ohm 1/4 watt resistor
R8, R17, R18, R23-R26 100K ohm 1/4 watt resistor
R10 330K ohm 1/4 watt resistor
R13, R14 22K ohm 1/4 watt resistor
R16 20K ohm trimmer resistor
R38 47K ohm 1/4 watt resistor
R39 200K ohm trimmer resistor

### Capacitors

C1, C6, C12-C15 1000 pfd capacitor
C2 2000 pfd capacitor
C3, C8 O.022 mfd capacitor
C4 1 mfd @15 VDC electrolytic capacitor
C5, C18 0.01 mfd capacitor
C7, C9 0.047 mfd capacitor
C10 2700 pfd capacitor
C11, C19, C20 470 pfd capacitor
C16, C22 100 mfd @16 VDC electrolytic capacitor
C17 10 mfd @10 VDC tantalum, capacitor
C21 1000 mfd @25 VDC electrolytic capacitor
C23-C25 0.1 mfd disc capacitor

### Semiconductors

ICI, IC5, IC8 4013 dual D flip-flop
IC2, IC11 4001 quad NOR gate
IC3, IC13 4070 quad EX-OR gate
IC4 4558 dual op amp
IC6, IC14 4053 triple multiplexer
IC7 4049 hex buffer
IC9 4023 triple 3-input NAND gate
IC10 555 timer
IC12 1489 quad RS-232 receiver
IC15 1488 quad RS-232 transmitter
IC16 7805 5 VDC regulator
D1, D2, D4, D5-D11 1N4148 silicon diode
D3 4.7 volt zener diode 1N4732 or IN5230
D12, D13 7.5 volt zener diode 1N4737 or 1N5236
D14-D17 1N4003 silicon rectifier
D18-D22 light emitting diode
Q1, Q2, Q4-Q8 2N5210 NPN transistor
Q3, Q9-Q11 2N5087 PNP transistor 

### Misc.

RLY1, RLY2 6 VDC reed relay
S1-S3 DPDT miniature toggle switch
S4, SS SPDT center off miniature toggle switch
S6, S7 SPDT miniature toggle switch
T1 18 VAC @300 Ma. secondary 120/240 VAC
50-60 Hz primary power transformer
F1 1 amp standard fuse 

## Chassis Assembly

- ( ) Sandwich the dress panel between the chassis and mounting hardware and attach
switches S1-S7 to the chassis using the wiring pictorial to show proper
location and orientation. Secure each switch using a finishing washer and
nut.
- ( ) Insert each of the four LED plastic mounting clips into the front panel holes
provided for LED diodes D19 thru D22. Insert each of the LED diodes into the
clips so that the flat on the side of each diode matches with that shown in
the wiring pictorial. Just for reference the side with the flat is the same
as the side with the shorter lead. Secure each LED diode with the plastic
retaining ring. This ring must be pressed on tightly to prevent the LED from
being loose.
- ( ) Attach RCA jacks J6 thru J9 to the chassis. Jack J6 should have a ground lug
put under it. Secure each jack with a 1/4" nut.
- ( ) RCA jacks J10 and J11 must be electrically insulated from the chassis. In
order to do this, first slip a shoulder washer over each RCA jack with the
shoulder against the inside of the chassis, place the jack against the
outside of the chassis, put another shoulder washer on the back side of the
jack with the shoulder against the inside of the chassis, follow this with'
the ground lug and finally secure with a 1/4" nut.
- ( ) Attach the power transformer to the chassis using #6-32 X 1/4" screws,
lockwashers and nuts. Orient the transformer so the end with the three wires
coming out of it is toward the front of the chassis.
- ( ) Attach the fuseholder to the chassis using a #6-32 X 3/8" screw, lockwasher
and nut.
- ( ) Snap the four nylon PC board supports into the holes provided for them in the
chassis.
- ( ) Snap the 1 1/2" bushing into the large hole provided on the back of the
chassis. The bushing should be installed from the outside of the chassis.
- ( ) Turn the chassis upside down and attach each of the four press on rubber feet
about 1" in from each of the corners.
- ( ) Using a pair of pliers, crimp the strain relief onto the line cord at a point
12" from the end of the cord. While compressing the strain relief insert the
12" length of the line cord and the strain relief into the 7/16" hole
provided on the back of the chassis, from the outside of the chassis.
- ( ) Press the specified color of switch cap onto the handle of each toggle switch
as specified below:

S1 – white
S2 – green
S3 – green
S4 – yellow
S5 – yellow
S6 – red
S7 - white

- ( ) Snap the ten tinnerman clips onto the holes provided on the front and back
lips of the chassis. 

## Chassis Wiring

- ( ) A11 connections made between the components on the chassis and the printed
circuit board are made thru connectors J1 and J2. This allows one to easily
remove the PC board for service or access to the bottom side of the PC board.
When soldering the wires to the main plugs for connectors J1 and J2, the
plugs must not be plugged into the PC board. If they are the female
connectors may melt and be ruined. Follow the wiring steps outlined on the
next two pages.
- ( ) Note for 220 VAC Operation - To wire the unit for 220 VAC operation, omit
wiring steps 1 thru 4 and instead solder together and insulate T1's
BlackWhite and Black leads. Then connect T1's White wire to Fl terminal A and
solder. Also connect T1's Red-Black wire to S6 terminal A and solder.
- ( ) Plug connectors J1 and J2 to the appropriate jacks on the PC board. Be sure
to orient the jacks correctly.
- ( ) Bundle any loose wires with the wire ties supplied with the kit.
- ( ) Snap the PC board into place. 

 WIRE FROM TO
STEP LENGTH GAUGE PART TERMINAL SOLDER PART TERMINAL SOLDER

1 - - T1 White - Fl A No
2 - - T1 Black - F1 A Yes
3 - - T1 Blk-White - S6 A No
4 - - T1 Red-Blk - S6 A Yes

5 - - line
cord
- - F1 B Yes
6 - - line
cord
- - S6 B Yes

7 9” #24 S1 B No S5 B No
8 2” #24 S1 E No J6 B Yes
9 12” #24 S1 E No S7 B Yes
10 4” #24 S2 F Yes J6 A Yes
11 3” #24 S2 D Yes J7 A Yes
12 2” #24 S2 A Yes S3 D No
13 2” #24 S2 C Yes S3 F No
14 2 1/2” #24 S3 A Yes J9 A Yes
15 3 1/2” #24 S3 C Yes J8 A Yes
16 2” #24 S3 B Yes S5 B Yes
17 2” #24 S4 B No D20 A No
18 1 1/2” #24 S5 A No D19 A Yes
19 3” #24 D20 A Yes D22 A No
20 1 1/2” #24 D22 A Yes D21 A Yes

21 5” #24 MOTOR 1A Yes J10 B Yes
22 5 1/2” #24 +5 Yes S1 B Yes
23 9 1/2” #24 READ DATA Yes D22 B Yes
24 5” #24 GROUND Yes S1 E Yes
25 6 1/2” #24 RELAY 1 Yes S3 F Yes
26 11” #24 RECORD DATA Yes D21 B Yes
27 4 1/2” #24 MOTOR 1B Yes J10 A Yes
28 11” #24 LOCAL/REMOTE Yes S7 C Yes
29 9” #24 READER OFF Yes S5 C Yes
30 8” #24 RECORD RLY DRIVER Yes S2 B Yes
31 6 1/2” #24 MANUAL MOTOR CNTRL Yes S1 C Yes
32 7” #24 READ RELAY-DRIVER Yes S3 E Yes
33 6 1/2” #24 RELAY 2 Yes S3 D Yes
34 3” #24 MOTOR 2A Yes J11 B Yes

35 7” #24 MOTOR 2B Yes J11 A Yes
36 5 1/2" #24 READER ON Yes S5 A Yes
37 7" #24 RECORD ON Yes S4 A Yes
38 7" #24 RECORD OFF Yes S4 C Yes
39 4" #24 READ READY Yes D20 B Yes
40 6" #24 RECORD READY Yes D19 B Yes
41 5 1/2" #24 AUDIO OUTPUT Yes S2 E Yes
42 4" #24 AUDIO INPUT Yes S3 B Yes
43 10" #24 CARRIER DELAY EN. Yes S1 F Yes
44 5" - GROUND Yes T1 Grn.-Yel -
45 5" - 18 VAC A Yes T1 Green #1 -
46 5" - 18 VAC B Yes T1 Green #2 - 

## Switches, Indicators & Jacks

The complement of front panel switches, indicators and jacks includes the
following:

MIC, EAR and REMOTE jacks for recorder A: These jacks should be connected
thru patch cords to the cassette recorder's respective jacks. It is often
times necessary to patch the MIC output of the cassette interface to the AUX
input rather than the MIC input of the recorder to be used. Some
experimentation may be necessary here. Be sure the cassette recorder(s) you
select have a REMOTE jack on them. This is necessary in order to have
cassette recorder motor control.

MIC, EAR and REMOTE jacks for recorder B: These jacks may be used for feeding
a second cassette recorder often required when using Editor/Assembler
software packages. Their functional description is identical to that provided
for recorder A.

RECORD SELECT A/B: When this two position switch is in the A position, the
cassette interface will output all record data to cassette recorder A. When
in the B position it will output all record data to cassette recorder B.

READ SELECT A/B: When this two position switch is in the A position, the
cassette interface will input all read data from cassette recorder A. When in
the B position it will input all read data from cassette recorder B.

RECORD STATUS ON/OFF: This three position switch is normally left in the
center position allowing computer program generated control commands to set
the state of the record latch. Momentarily flipping the switch to the ON or
OFF position will manually update the status of the record latch. Leaving the
switch in either the ON or OFF position will override computer program
control entirely. A convenient LED status indicator just to the left of this
switch always shows the state of the record latch. The operation of the
cassette interface as a function of the state of the record latch is
dependent upon the setting of the motor control switch which is described in
detail later.

READ STATUS ON/OFF: This three position switch is normally left in the center
position allowing computer program generated control commands to set the
state of the read latch. Momentarily flipping the switch to the ON or OFF
position will manually update the status of the read latch. Leaving the
switch in either the ON or OFF position will override computer program
control entirely. A convenient LED status indicator just to the left of the
switch always shows the state of the read latch. The operation of the
cassette interface as a function of the state of the read latch is dependent
upon the setting of the motor control switch which is described in detail
later.

RECORD DATA INDICATOR: This LED indicator shows the transmission of valid
record data out of the cassette interface. It lights only when the record
latch is on and logic zeros or spaces are being transmitted. This allows the
operator to confirm that a tape dump is in progress when lit since the null
data marking output does not light the indicator. 

READ DATA INDICATOR: This LED indicator shows the receipt of valid read data
into the cassette interface. It lights only when the read latch is on, valid
FSK data is detected on the tape and logic zeros or spaces are being
received. This allows the operator to confirm that a tape load is in progress
when lit since the null data marking input or a loss of audio tones does not
light the indicator.

MOTOR CONTROL - MANUAL/AUTO: The position of the motor control switch
actually determines the function of the record and read status
latches. In the MANUAL position both the record and read cassette
recorder motors are always activated thru their respective REMOTE
jacks. If the record latch is off, the interface's selected recorder
MIC jack will output a constant marking carrier, even if there is data
flowing back and forth between thecomputer and terminal. As soon as
the record latch is turned on either by the computer or manual
control, all data transmitted from the computer to the terminal is
simultaneously transmitted out thru this same MIC jack. Data flow out
of the MIC jack ceases as soon as the record latch is again reset by
either manual or computer control.

If the read latch is off the interface will ignor all data incoming
thru its selected EAR jack and yet pass data back and forth between the
terminal and computer. If the read latch is turned ON either by manual or
computer control and valid audio tones are sensed from the selected EAR jack,
read data is stored from the cassette unit to the computer. This same data is
simultaneously displayed on the attached terminal system only if the computer
is programmed to echo the incoming cassette data. Data flow from the cassette
to the computer system ceases either upon resetting the read latch or loss of
audio tones on the tape.

Operation in the AUTO position is quite different. If both the record
and read latches are reset, cassette recorder motor operation is inhibited
thru the respective REMOTE jacks on both the record and read recorders. The
interface's selected record MIC jack will output no audio data, even if there
is data flowing back and forth between the computer and terminal. As soon as
the record latch is turned ON, the recording recorder's motor is turned on
thru the respective REMOTE jack and a variable delay timer is fired which
delays the output of audio marking data to allow this same cassette
recorder's tape to come up to normal tape speed. This hardware delay circuit
must be supplemented with a software delay loop written into your programs to
guarantee that you don't start outputting record data until after this
hardware delay timer on the cassette interface has already timed out. When
the record latch is again turned off, the interface will cease to output
audio data and the selected recorder's motor is turned off. Here again it is
wise to include a software delay loop in your programs to give the recorder
time to come to a complete stop. This guarantees a sufficient gap between
multiple recorded segments to allow one to do either incremental (start-stop)
or continuous reads from the same tape.

When the read latch is turned on the read recorder's motor is started.
The interface inhibits all read recorder data until valid audio tones are
detected, at which time all incoming cassette data is stored to the computer
and simultaneously displayed on the terminal only if the computer's echo is
enabled. Reads may be either continuous or incremental (start-stop). Since
incremental tapes have blank gaps between recorded segments, the cassette
interface's audio tone sensing circuitry has been designed to ignore all but
the valid data segments stored on the tape. 

LOCAL/REMOTE switch: The LOCAL/REMOTE switch on this cassette interface is
analogous to that on standard teletypewriters. In the LOCAL mode there is a
direct data link between the terminal and cassette recorder(s). The computer
is electrically eliminated from the system. In the REMOTE or normal mode of
operation, the computer, terminal and cassette recorder(s) are all linked
together.

POWER ON/OFF: This switch controls AC power to the cassette interface unit.
It must be powered up consistently with the interconnected computer and
terminal systems even if cassette operation is not desired.

## Attaching the Interface to the Recorders

If you will be using the interface just for loading and storing programs and
data files to and from tape you will probably need just one cassette recorder. If
however, you will be doing tape file editing or using assembler packages you will
probably have to use two cassette recorders. The same single interface will handle
both configurations. Electrical connections between the cassette interface and
recorders are best made by cutting several 3' to 4' audio patch cords with the
molded RCA connectors on both ends, in half and fitting the newly cut ends with the
appropriate recorder jack mating connectors. Some cassette recorders such as the
ones used with the prototype have both high level AUX and low level MIC inputs. In
our case it was necessary to use the AUX input since the cassette recorder
circuitry would not permit the reading of a tape with a plug simultaneously
installed in the MIC jack. Be sure to use a cassette recorder featuring an AGC
(automatic gain control) circuit. Most all late model cassette recorders have this
feature. Since cassette motor control is available you will want a recorder with a
REMOTE jack that stops the recorder's motor. Here again recorder circuitry varies.
Some units disable just the motor while others disable everything. It is best in
this instance to just disable the motor, the idea being to minimize the recorded
transients between blocks of data when using the interface in the incremental
(start-stop) mode of recording. The recorders used with the prototype were
Superscope models C-101A. Although they were reliable, close examination of the
quality of recorded data with an oscilloscope left a lot to be desired. The optimum
volume control setting was around 7 on a scale of 0 to 10.

The quality of the cassette tape used with your recorder(s) will also affect
the reliability of your system. Here the best rule of thumb is to assume you get
what you pay for. The most expensive tapes will generally give you better
reliability. Remember too that you are recording audio frequency data not saturated
pulses, so don't use digital computer grade cassette tapes. Always erase previously
recorded tapes with a bulk tape eraser such as a Radio Shack #44-210 ($9.95) before
rerecording them. This is especially important when using the system in the
incremental (start-stop) mode of operation. Bulk tape erasers generally do a better
job of erasing than your recorder's internal circuitry and guarantee that you don't
pick up segments of previously recorded programs or data.

Superscope is a registered trademark of Superscope Inc. 

The interface's read circuitry must be calibrated for use in the read mode
before using the interface. This is best done by using your computer or terminal to
generate a calibration tape with continuous ASCII 5's recorded on it and then
reading back the tape to the computer in the REMOTE mode or terminal in the LOCAL
mode while adjusting trimmer resistor R16 for a center setting between errored
reads. ASCII fives have an alternating bit sequence ideal for calibration. It is a
good idea to periodically recheck this setting using your previously generated
calibration tape.

Before using your cassette interface unit in the incremental (start-stop)
mode of recording it will be necessary to set the time delay on the carrier enable
one shot, trimmer resistor R39, so as to allow the recorder's motors to come up to
speed before outputting a marking audio tone. This is best done by visually
measuring your recorder's motor start time and then multiplying by two just for a
safety factor. The interface's delay is then set by adjusting trimmer resistor R39
for this same time delay between the time the RECORD "READY" indicator lights and
the CARRIER ENABLED indicator (LED diode D18) comes on. The latter is mounted right
on the interface's PC board adjacent trimmer resistor R39.

Whenever you are writing to tape in the incremental (start-stop) mode you
must provide a software delay loop in your program that is at least as long as the
adjustable hardware timer delay plus 0.5 seconds. The additional half second is
required to guarantee a carrier detect signal before data flow when the tape is
being read. It is also a good idea to put a header character or characters at the
beginning of each incremental record. Upon reading these records, your program
should be written such that it ignores all data between these recorded segments
until this header data is read. The cassette interface is more vulnerable to error
reads between incrementally recorded data than at any other time. The end of each
data block may easily be detected by recording some non-displayed control character
at the end of each data block. If you are using the cassette interface with the
SWTPC 6800 Computer system and CT-1024 (TV Typewriter II) terminal system, the
decoded RECORD OFF ASCII Control T command (1416) not only turns the recorder off
but is written at the end of the data record as well, for an end-of-record
character.

Incrementally recorded records may be read either continuously or
incrementally. In either case you must provide a software delay in
your program at least one character time (33 milliseconds) between the
time the end-of-record character is read and the time data is output
from the interface. The reason being that there is a slight delay
between the loss of carrier on the tape and action of the CARRIER
DETECT circuitry which in turn creates a gap in the 16 X UART clock.
This gap causes no problems so long as you are not outputting data
during the clock gap thus the reason for the delay.

Fortunately all of the formentioned considerations are only necessary when
using the interface in the incremental (start-stop) mode. Operating the system in
the continuous (motor control disabled) mode isn't much different from paper tape
operation. You will of course have to manually start and stop the recorders but no
special recording considerations are necessary which usually allows use of
unmodified computer resident tape load and dump routines for program storing and
loading. 

## Interfacing to a SWTPC 6800 and CT-1024 Terminal System

As mentioned earlier the ideal configuration for using the AC-30 Audio
Cassette Interface is with the SWTPC 6800 Computer System and CT-1024 Terminal
System. The Terminal system must be outfitted with the CT-S Serial Interface along
with the CT-SO optional baud rate kit. For those not already having the baud
option, we now offer the optional baud rate kit for $14.75 PPd, in the U.S. The
terminal and computer must be operated at 300 baud. The terminal system must also
be outfitted with the CT-CA Computer Controlled Cursor Option. This board is
necessary to generate the decoded control commands which are fed to the AC-30
Cassette Interface.

Electrically the AC-30 Cassette Interface is plugged in series between the
6800 and the CT-1024. You simply remove the plug connecting the CT-1024 Terminal
System to the computer's control interface and plug it into the AC-30 instead. A
separate connector then connects the AC-30 Cassette Interface to the MP-C Control
Interface on the Computer System. The computer's MP-C Control Interface must be
jumpered for 300 baud operation. In this configuration all data passing between the
computer and terminal may if selected be written to tape or supplemented with data
from tape. Connections from the CT-1024 Terminal System's CT-S Serial Interface 16X
baud rate clock and CT-CA Computer Controlled Cursor decoded control command logic
are made to the AC-30 Cassette Interface thru the center connector on the back of
the AC-30 circuit board.

The SWTPC 6800/CT-1024 Interconnection Drawing shows all connections that
need be made for this configuration. The AC-30 Cassette Interface must always be
powered up when using the system even if you are not using a cassette tape since
all computer/terminal data flow is thru the cassette interface. After attaching the
supplied connector to the CT-1024 Terminal System you should note that the 16X
clock for the CT-S Serial Interface was broken when installing the cassette
connector. This brake prevents the CT-1024 Terminal System from operating if it is
not attached to the AC-30 Cassette Interface. For this reason the connections for a
dummy plug have been shown which must be plugged onto the CT-1024 Terminal System's
connector for stand-alone operation. so don't forget to install the dummy plug on
the terminal's connector when using the terminal system without the AC-30 Cassette
Interface.

After actually interconnecting the AC-30 with your system flip the LOCAL/
REMOTE switch to the REMOTE position and you should find that you have normal
communication with the computer system. If you flip the same switch to the LOCAL
position you should find that everything typed on the terminal's keyboard is echoed
to the terminal's screen, even though the ECHO ON/OFF switch on the keyboard is in
the OFF position. Before you actually try to load or store a program on tape, the
unit must be calibrated using the FIVPNT-1 Interface Calibration Program. A copy of
this program is contained within a separate section of this instruction set. It
might also be wise to run the other diagnostic programs which are also contained
within this instruction set. When you are running the diagnostic programs you may
find that the terminal will occasionally omit a character when reading a tape back
in the LOCAL mode. This as we found is a problem in the terminal and not in the
AC-30 Cassette Interface. If you wish to correct the problem carefully separate pin
1 of IC31 on the CT-1024 Terminal System from its connection to the circuit board.
Attach and solder a wire from this now isolated pin to IC26 pin 13. It is a good
idea to increase the value of C4 on the CT-CA board on the CT-1024 Terminal System
from a 100 pfd capacitor to a 1000 pfd capacitor. You may also find when you are
reading back tapes recorded in the incremental mode that question marks
occasionally show up between incrementally recorded records. This is where the
AC-30 is most vulnerable to errored reads and is best solved by your putting a
header character s) at the beginning of each incrementally recorded record as the 
Editor/Assembler programs do. Header characters have not been used in the
diagnostics so that the user may see all non-control character data written to
tape.

Some experimentation with volume control settings will probably be necessary.
Run the diagnostics at various volume control settings and choose the one that
gives you the most reliable results.

Let's assume now we have a SWTPC 6800 Computer and CT-1024 Terminal System
interfaced together with 300 baud RS-232 serial interfaces. As mentioned earlier
for this configuration, the cassette interface is connected in series between the
two taking full advantage of the computer's firmware resident tape dump and load
routines. Let's assume we have a program we wish to dump to tape which is already
stored in the computer's memory with the computer's pro gram counter, storage
addresses (A048 and A049), set to the starting location of the program. Now use the
memory change function to set the starting and ending addresses of the memory
segment to be dumped in locations A002 thru A005.
The cassette interface's switches should be set for manual motor control with

the RECORD/READ status switches in the center position and the LOCAL/REMOTE switch
in the REMOTE position. Load a blank or previously erased tape into the selected
cassette recorder and depress the REWIND button to get to the beginning of the
tape. Then depress the PLAY button to advance several seconds beyond the leader on
the tape. Stop the recorder and this time depress the cassette recorder RECORD
button. Then enter a P for punch on the terminal's keyboard. The record STATUS
light will come on and the record DATA light will flicker as program data is stored
to the cassette tape. When the dump is completed both the STATUS and DATA lights
will go out. Do not stop the recorder, instead set memory locations A002 thru A005
to dump the data stored in the program counter storage addresses as well. Since the
record STATUS light is not lit, none of this data passing back and forth between
the terminal and computer is written to the still operating recorder. Again enter a
P for punch. The STATUS and DATA lights will again come on, but only for a fraction
of a second since only two memory locations are written to the tape. Now while the
cassette recorder is still recording flip the LOCAL/REMOTE switch to the LOCAL
position, use the manual RECORD status switch to set the record STATUS latch and
type in on the terminal's keyboard S9. Reset the RECORD status latch to the off
position and stop the recorder. Don't forget to flip the LOCAL/REMOTE switch back
to the normal REMOTE position.

Before trying to load this same program you might want to momentarily turn
the computer off just to make sure the memory resident program is destroyed before
loading. Reapplying power will force an auto-reset and bring up the resident MIKBUG
firmware on the SWTPC 6800. Rewind the tape to the beginning, make sure the
cassette recorder's volume is set to a reliable setting and depress the play
button. Then type in a L for load on the terminal's keyboard. The read STATUS light
will immediately come on since the firmware outputs a READ ON control command. The
DATA light however will remain off until program data is detected on the tape at
which time it will begin to flicker. When it stops flickering it means that the
program data has been loaded to the computer's memory but don't forget that the
program counter data was also written to the tape so the next flicker is that of
the program counter being loaded. A S9 was also written to the tape which is an end
of tape marker. Upon reading this the computer will output a READ OFF control
command forcing the read STATUS light to go out hence ignoring all subsequent data
stored on the tape should the recorder be left to run. The program as well as the
program counter have been loaded. Simply typing in the character "G" for go should
initiate the program.

MIKBUG is a registered trademark of Motorola Inc. 

## Interfacing to a SWTPC 6800 and non-CT-1024 300 Baud Terminal System

The terminal used must be a 300 baud RS-232 terminal as is the CT-1024
Terminal System. It is desirable that the terminal have an accessible 16X baud rate
clock. If not, it is still usable but you will not be guaranteed of reliable tape
reads when reading tapes in the LOCAL mode. You will also not be able to record
tapes directly from the terminal in the LOCAL mode since the AC-30 logic requires
the terminal's 16X baud rate clock for recording. If your terminal does not have
control character decode circuitry you may still load programs but without software
control The Editor/Assembler software package requires motor control and for this
reason has motor control logic fed out of unused lines on the MP-C Control
Interface board. This means that you can derive the cassette logic control for the
AC-30 Cassette Interface from a connector installed on the MP-C Control Interface
board. This cassette control logic is only functional when the Editor/ Assembler
software is resident and will not operate with the MIKBUG firmware or other
software packages unless the appropriate driving software has been written into
them. Since MIKBUGR is tolerant of non-program data encountered when loading tapes
we may fortunately still load and store programs without cassette logic control If
by chance your terminal does have control character decode circuitry, it is
unlikely its timing and phasing are the same as that of the CT-CA board on the
CT-1024 Terminal System. The Reader ON, Reader OFF, Record ON an Record OFF.
control lines should be TTL compatible pulses between 1 and 1000 microseconds
duration. The logic is set up for negative going pulses, however, grounding the
CONTROL INVERT line on the AC-30 board programs the AC-30 for positive going
pulses.

If you are forced to use the cassette control logic put out on the SWTPC
6800's MP-C Control Interface board by the Editor/Assembler software, make the
following connections from the indicated pins of IC1 on the MP-C Control Interface
board to the specified pins of a twelve pin male connector shell. Be sure to make
the wires long enough to reach your AC-30 Cassette Interface where the connector
will be plugged. If you do have access to your terminal's 16X baud rate clock, the
terminal's clock buss should be broken and the 16X clock OUT and 16X clock IN lines
brought out to the same connector:

FROM TO
MP-C IC1 pin 7 12 pin male shell female pin #1
MP-C IC1 pin 4 12 pin male shell female pin #2
MP-C IC1 pin 6 12 pin male shell female pin #3
MP-C IC1 pin 5 12 pin male shell female pin #4
Terminal's 16X clock OUT 12 pin male shell female pin #5
Terminal's 16X clock IN 12 pin male shell female pin #6
MP-C ground 12 pin male shell female pin #12

The mating connector on the AC-30 Cassette Interface as well as other
interconnections to the unit should be installed just as it is shown
in the interconnection drawing for the SWTPC 6800 and CT-1024 Terminal
System.

Let's assume now that we have a SWTPC 6800 Computer System, AC-30 Cassette
Interface and 300 baud terminal system and are taking cassette control commands off
the MP-C Control Interface on the SWTPC 6800 Computer System. Although the AC-30
Cassette Interface is in series between the computer and terminal systems we have
no means of getting the cassette control commands to the cassette interface since
the MIKBUG R firmware does not generate cassette control commands on the MP-C
Control Interface board. Once the Editor/Assembler program has been loaded the
input/output routines within the package provide the necessary cassette control
commands required for the software motor control mode of operation of the package. 

You do not have to have cassette control logic to simply load and
store programs with the AC-30 Cassette Interface although it is easier
to use if you do. Let's assume now we have a program we wish to dump
to tape which is already stored in the computer's memory with the
computer's program counter, storage addresses (A048 and A049), set to
the starting location of the program. Now use the memory change
function to set the starting and ending addresses of the memory
segment to be dumped in locations A002 thru A005. The cassette
interface's switches should be set for manual motor control with the
RECORD/READ status switches in the center position with the status
lights nut and the LOCAL/REMOTE switch in the REMOTE position. Load a
blank or previously erased tape into the selected cassette recorder
and depress the REWIND button to get to the beginning of the tape.
Then depress the PLAY button to advance several seconds beyond the
leader on the tape. Stop the recorder and this time depress the
cassette recorder RECORD button. Flip the RECORD status switch to set
the RECORD status light ON. Then enter a P for punch on the terminal's
keyboard

The record DATA light will flicker as program data is stored to the cassette
tape. When the dump is completed the DATA light will go out. Do not stop the
recorder, instead set memory locations A002 thru A005 to dump the data stored in
the program counter storage addresses as well. Since the record STATUS light is lit
this data passing back and forth between the terminal and computer is written to
the still operating recorder but is however ignored when loading the program. Again
enter a P for punch. The DATA light will again come on, but only for a fraction of
a second since only two memory locations are written to the tape. Now while the
cassette recorder is still recording flip the LOCAL/REMOTE switch to the LOCAL
position and type in on the terminal's keyboard, S9. You can only type the S9 if
you have the 16X baud rate clock fed from your terminal to the AC-30 Cassette
Interface otherwise omit this step. Now you may stop the recorder. Don't forget to
flip the LOCAL/REMOTE switch back to the normal REMOTE position and reset the
record STATUS light OFF.

Before trying to load this same program you might want to momentarily turn
the computer off just to make sure the memory resident program is destroyed before
loading. Reapplying power will force an auto-reset and bring up the resident MIKBUG
R firmware on the SWTPC 6800. Rewind the tape to the beginning. Make sure the
cassette recorder's volume is set to a reliable setting and depress the play
button. Then type in a L for load on the terminal's keyboard set the read STATUS
light ON. The DATA light will remain off until program data is detected on the tape
at which time it will begin to flicker. When it stops flickering it means that the
program data has been loaded to the computer's memory but don't forget that the
program counter data was also written to the tape so the next flicker is that of
the program counter being loaded. If an S9 was written to tape which is an end of
tape marker, a * will be printed on the screen upon termination of loading. The
read STATUS light must be immediately manually reset OUT. If an S9 was not written
to tape, a * will not be printed and the read STATUS light will have to be manually
reset OFF immediately upon loading the second string of data. The S9 is then
manually typed in from the terminal's keyboard and the computer responds with a *.
The program, as well as the program counter, have now been loaded. Simply
typing in the character G for go should initiate the program. 

## Interfacing to a SWTPC 6800 and non-300 Baud Terminal System

Since the AC-30 Audio Cassette Interface must be operated RS-232 serial at
300 baud, it cannot be implemented serially between the computer's control
interface and the terminal system on non-300 baud or non-RS-232 terminal systems.
The only option the user has in these cases is to operate the AC-30 Cassette
Interface thru an optional serial type interface connected to one of the unused I/0
slots on the computer system. The big disadvantage here is that the MIKBUG resident
tape load and dump routines are only functional on the I/0 slot #1, the MP-C
Control Interface position. Locating the AC-30 Cassette Interface at any other I/0
position means that all tape load and dump routines will have to be keyed in
manually by the user before the AC-30 Audio Cassette Interface can actually be used
to load programs. The other problem is that we no longer have any way of deriving
motor control for the cassette unit since motor control commands sent out thru the
MP-C Control Interface on I/0 card slot #1 are of no use to us. On top of that the
standard MP-S serial interface option does not have enough control lines available
to provide READER ON, READER OFF, RECORD ON and RECORD OFF logic control for the
attached AC-30 Cassette Interface. For these reasons it is our recommendation that
the AC-30 be interfaced to the computer system thru a separate MP-C Control
Interface configured for 300 baud located at some unused I/0 card position on the
interface buss. This means there will be a larger overhead in software for the user
but the extra unused parallel lines on the parallel PIA integrated circuit may be
used for AC-30 READER ON, READER OFF, RECORD ON, and RECORD OFF control functions.
Our cassette version of the Editor/Assembler software already has I/0 routines
contained within to drive an MP-C Control Interface located at any I/0 card
position on the SWTPC 6$00 Computer System. READER ON, READER OFF, RECORD ON and
RECORD OFF control commands may be taken off unused pins on the PIA parallel
interface chip. The lines have been assigned on the control interface when using
the Editor/Assembler software package. It is suggested that you use the same
assignments to maintain consistency.

To actually use these logic/control lines within your own programming you
will have to write routines within your own cassette I/0 software package to put a
TTL compatible 1 to 1000 microsecond negative going strobe pulse on the respective
PIA pin to generate the desired command. A connector is attached from these MP-C
PIA pins to the control lines on the AC-30 Cassette Interface and is installed as
follows.

Make the connections from the indicated pins of ICI on the MP-C Control
Interface board to the specified pins of a twelve pin male connector shell, Be sure
to make the wires long enough to reach your AC-30 Cassette Interface where the
connector will be plugged:

FROM TO
MP-C IC1 pin 7 12 pin male shell female pin #1
MP-C IC1 pin 4 12 pin male shell female pin #2
MP-C IC1 pin 6 12 pin male shell female pin #3
MP-C IC1 pin 5 12 pin male shell female pin #4
Terminal's 16X clock OUT 12 pin male shell female pin #5
Terminal's 16X clock IN 12 pin male shell female pin #6
MP-C ground 12 pin male shell female pin #12

The mating connector on the AC-30 Cassette Interface should be installed just
as is shown in the interconnection drawing for the SWTPC 6800 and CT=1024 Terminal
System. Other connections are made as shown in the appropriate block diagram. All
data connections made to the AC-30 should be thru the connector provided for the
computer. Since there will be no terminal connected directly to the AC-30 there is
of course no LOCAL mode of operation for the cassette system. 

You will have to write your own cassette tape I/0 routines in order to be
able to load and dump programs to and from the AC-30 Cassette Interface which is
now interfaced to an MP-C Control Interface somewhere other than I/0 Card position
#1. You should be able to use the MIKBUG R source listings of the tape load and
punch routines to aid you in writing your own for the cassette interface. If the
routines are kept short enough you might be able to load them into unused areas of
the MIKBUG RAM which would give your programs complete use of 0-32K user memory.
The tape load and dump programs will however have to be typed in manually from the
terminal before using them.

## How It Works

For simplicity the cassette interface's circuitry has been broken up into
three separate systems: The modulator/demodulator circuitry, the switching
circuitry and the power supply.

The modulator works by feeding a 4800 Hz (16 X 300 baud) clock into divide by
two IC5B. This insures a 50% duty cycle required by the modulator. The CARRIER
ENABLE input provides a means of suppressing audio output from the modulator. IC5A
functions as a divide by two if the DATA IN line is high and a divide by one if the
DATA IN line is low. This gives a 1200 Hz tone for a low and a 2400 Hz tone for a
high. This resulting output is then fed into two pole active filter IC4A where it
is converted to more of a sinusoidal audio waveform which is more easily handled by
audio recorders.

Incoming audio data is first fed into a high pass filter consisting of R5 and
C5 and then onto comparator IC4B. The comparator's 0.5 volt hysteresis reduces the
possibility of false triggering. The +7.5 volt zener regulated power busses feeding
IC4 are necessary to stabilize this hysteresis value. Zener diode clamp D3 limits
comparator IC4B's output to CMOS compatible voltage levels. Each time the
comparator changes states IC3C and IC3D generate a 5 microsecond negative pulse at
IC3 pin 11. This pulse is repetitive when data is being received and pulls
capacitor C7 down to ground thru diode D4. Capacitor C7's output is in turn
inverted and buffered thru IC3A to form the CARRIER DETECT output signal. This same
negative going pulse is inverted by IC2A where it feeds four separate circuits. The
first is a missing pulse detector composed of transistor Q2 and inverter IC2B. This
forces the buffered CARRIER DETECT signal low whenever several cycles of audio
carrier are missed. The second circuit is also an adjustable missing pulse detector
but this one times out whenever 1200 Hz or space data is being fed into the
demodulator. Trimmer resistor R16 sets the period for this timer. The third circuit
driven by this pulse is flip flop ICIA which outputs the demodulated data. This
DATA OUT line is high when 1200 Hz audio is being demodulated and low when 2400 Hz
audio is being demodulated. The fourth circuit fed by the pulse is IC2D which with
the addition of the output of IC3B synthesizes the 16 X CLOCK OUT data. Take note
that although this 16 X clock is accurate, it, by design, jitters.
Within the switching portion of the circuit, integrated circuit halves IC8A
and IC8B form RS status latches for the record and read circuitry. Either latch may
be independently set or reset thru manual toggle switches on the interface's front
panel or thru control pulses buffered and selectively inverted by IC13. Convenient
front panel LED indicators always show the current status of these latches. 

The multitude of data and clock switching is performed by six data selectors
within IC6 and IC14. NAND gates IC9A and IC9B inhibit data and clock flow out to
the cassette recorders unless the read latch is set and valid recorder carrier data
is detected. Timer IC10 provides the adjustable CARRIER ENABLE delay needed when
using the system for recording in the incremental (start-stop) mode. All 300 baud
data communication with the cassette interface is done thru integrated EIA RS-232
receiver and transmitter integrated circuits IC12 and IC15 respectively. Motor
control for each recorder is provided by reed relays RLY1 and RLY2.

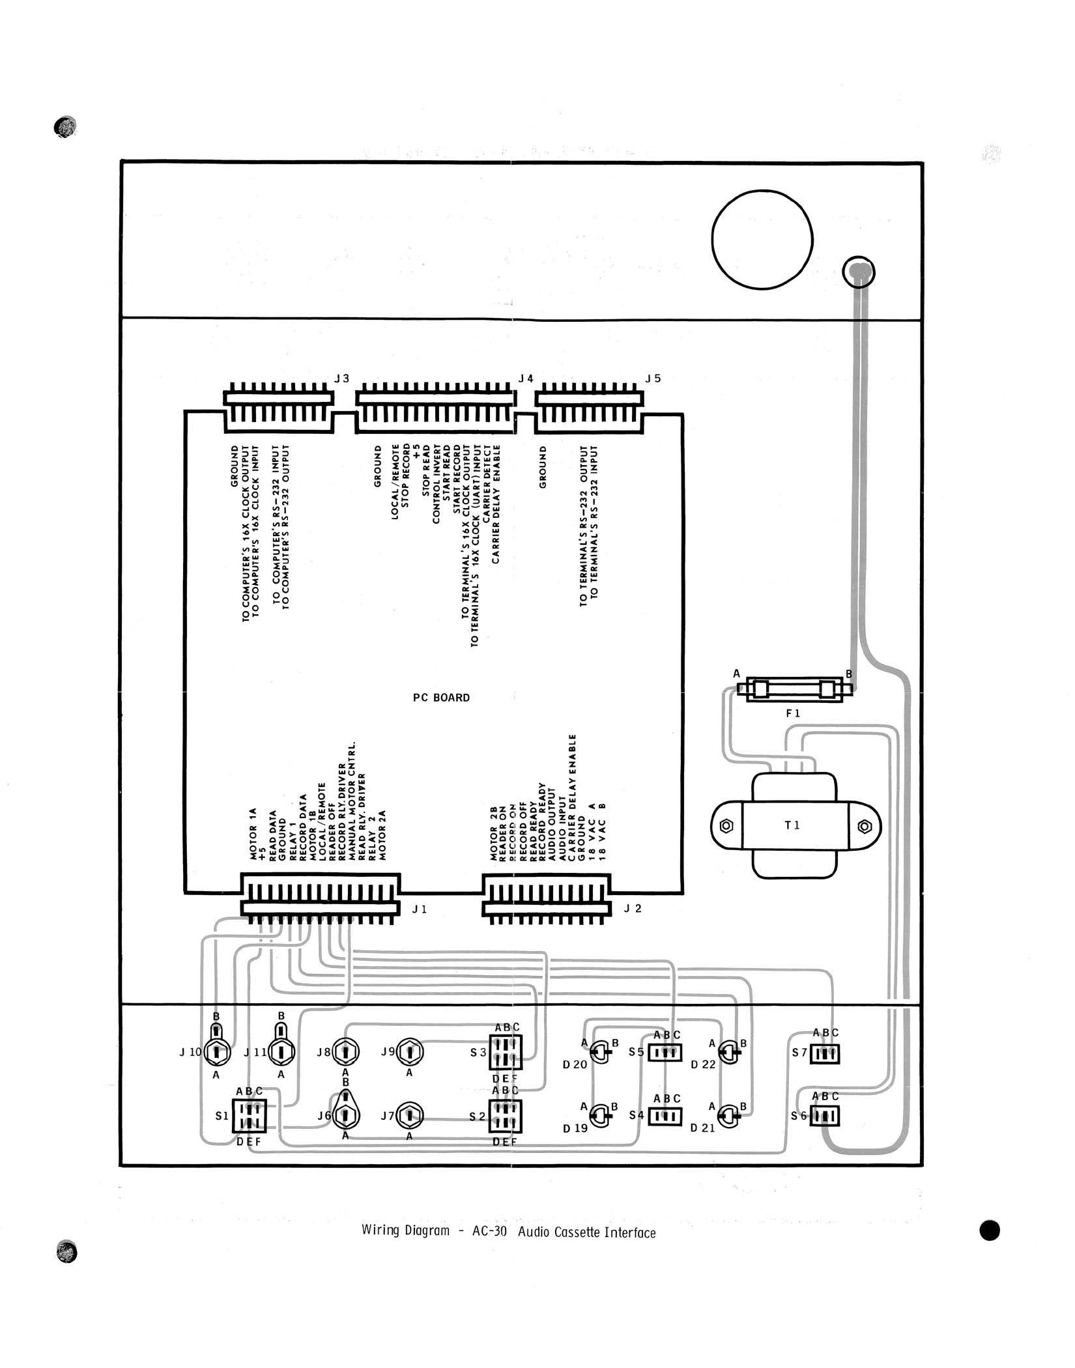
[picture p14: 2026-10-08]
docs/ac30_wiring2a.jpg

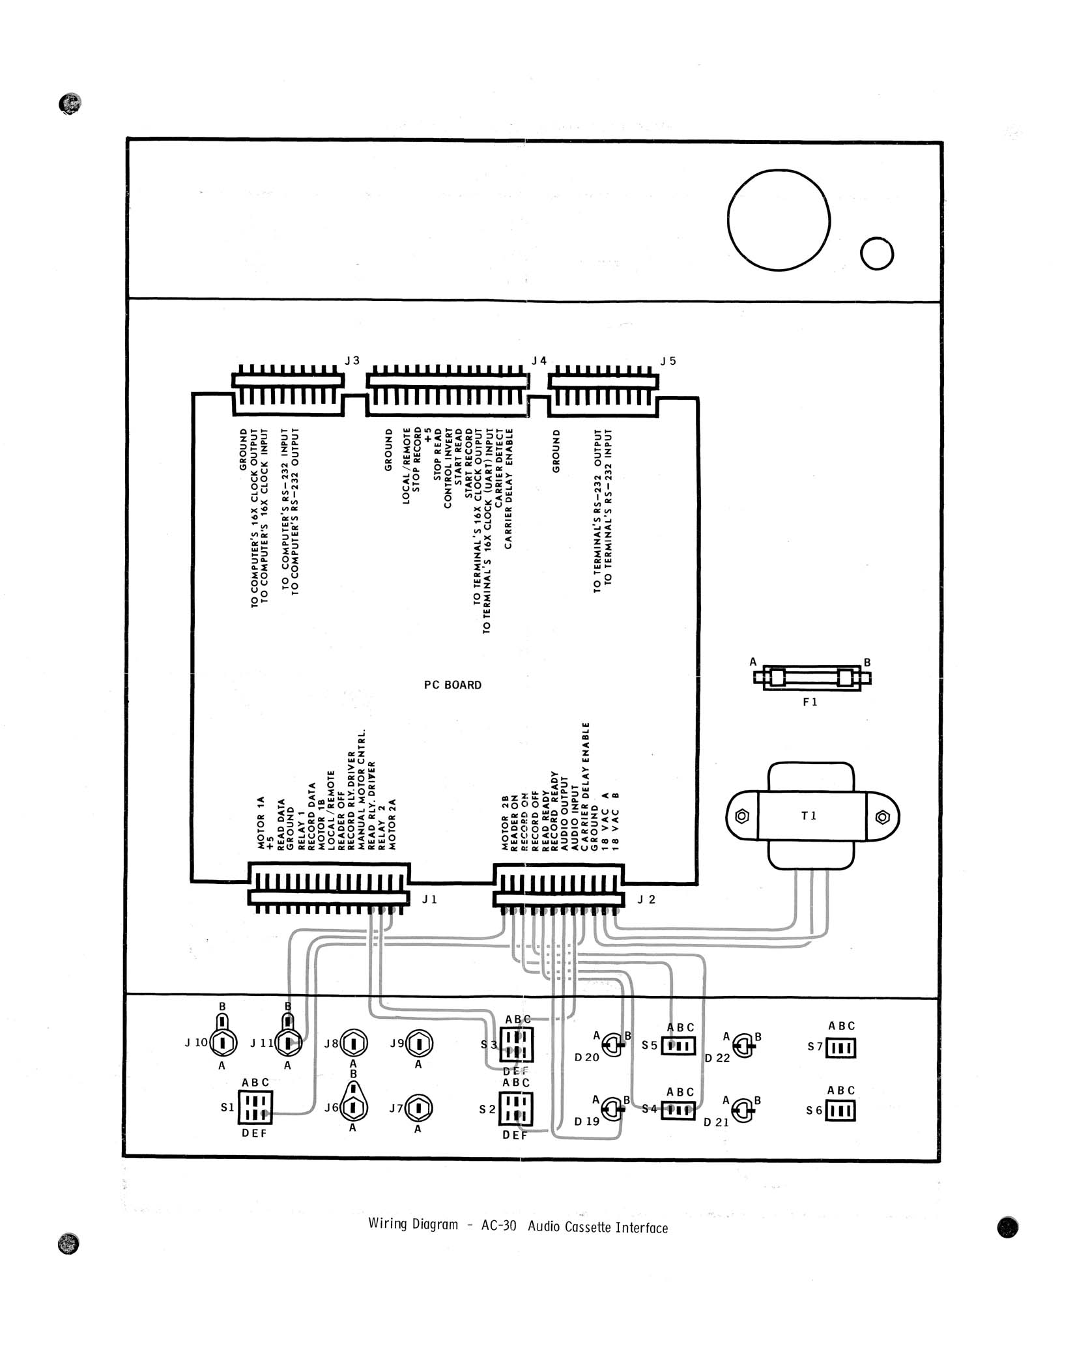
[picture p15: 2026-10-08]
docs/ac30_wiring1a.jpg

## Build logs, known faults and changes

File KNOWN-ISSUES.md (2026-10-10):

# AC-30 Reproduction: Known Issues

Status on 2026-10-10. This file covers both boards: through-hole (`kicad/AC30.*`) and SMT (`kicad-smt/AC30_SMT.*`). Both currently build from scratch with `kicad/tools/build.sh` (add `smt` for the SMT board) and pass ERC, DRC at every severity and the schematic parity check, with every connection routed.

Board details are in `AC30-settings.md` and `AC30-SMT-settings.md`. The full history is in `AC30-Claude.md`.

---

## Check before ordering

1. **The Gerbers haven't been checked in a Gerber viewer or by the board house.** They are exported from boards that pass DRC, the drill counts match the drill reports, and KiCad's copper renders look right. Run them through the board house's preview or DFM check before paying.

2. **Some connections are interpretations of the original drawings.** Check them against `docs/ac30_schematica.jpg`, `docs/ac30_mod_demod.pdf` and `docs/ac30_PS.pdf`:

   | Item | Taken as | Why |
   |---|---|---|
   | IC16 (7805) ground | GND | The PS drawing joins it to the −13 V corner of the bridge, which would make the regulator put out about −8 V |
   | IC15 (1488) supply | +13 V (pin 14), −13 V (pin 1) | Not drawn on any schematic; the only load left for those rails |
   | IC4 (4558) supply | +7.5 V (pin 8), −7.5 V (pin 4) | Not drawn; the assembly manual says it runs from the zener rails |
   | R16 far end | +5V | A terminal dot with no label |
   | IC10 (555) pins 4 and 8 | +5V | Tied to the R38 supply node on the drawing |
   | 4053 INH (pin 6) and VEE (pin 7) | GND | Not shown on the drawing |
   | IC1B | Unused, inputs to GND | Not drawn |
   | IC7D, IC13C pin numbers | Corrected to the real pinouts (IC7D 9→10; IC13C inputs 8, 9) | Drawing slips |

3. **R39 (200K DELAY trimmer) isn't on either board.** It is on the parts list and next to IC10 on the original artwork, but on no schematic, so its connections are unknown.

4. **SMT part substitutions** (SMT board only):
   - **RLY1/RLY2:** Omron G6K-2F-Y, 5 V coil, DPDT, contacts rated 1 A, both poles in parallel. The original is a 6 V SIL reed relay. Check the coil polarity mark against the datasheet (pin 1 goes to RELAY_x).
   - **Q1, Q2, Q4–Q8:** MMBT5088 stands in for the 2N5210. It is close but not identical; check the demodulator's behaviour.
   - **C4 (1 µF 15 V) and C17 (10 µF 10 V):** tantalum, EIA-3216 (A case), with little voltage margin. Consider higher-voltage parts.

5. **SMT assembly.** `kicad-smt/AC30_SMT-top-pos.csv` uses KiCad's rotations; many assembly houses apply their own offset per package, so check their placement preview. The position file covers only the SMD parts: the KK-396 connectors and the front-panel wire pads are soldered by hand.

## Board design

6. **Neither board fits the original enclosure.** The original board was about 194 × 187 mm; these are 173.0 × 126.5 mm (through-hole) and 173.0 × 88.5 mm (SMT), with the mounting holes ¼ in from their own corners.

7. **The audio lines cross the board.** Each wire has its own pad, so AUDIO_OUT, MIC_A/B, AUDIO_IN and EAR_A/B run between the SWITCHES row and the MIC/EAR rows, near digital signals. The GND fill helps.

8. **Tracks run under the pad labels** on the top layer. The labels still print over them, but are harder to read.

9. **A few GND pads are solid-connected to the copper fill** instead of using a thermal relief: D11.2, IC8.7, IC8.11 and Q7.1 on the through-hole board, and J14.2 on the SMT board. They need more heat to solder. The list depends on the routing and can change with any re-route (`build.sh` prints it).

10. **The through-hole board's TO-92 pads have a narrow annular ring:** 0.15 mm on the narrow side, the smallest on the board.

11. **The 3D models are incomplete.** The KK-396 connectors and the through-hole R16 trimmer have no model, and the wire-pad rows appear as 0.1 in pin headers.

12. **The power supply and front panel have no board.** Both are wired by hand: the supply to J12, the switches, LEDs and jacks to the wire pads.

## Tools and repository

13. **Every build changes files that haven't really changed:**
    - `kicad-cli` gives schematic pins new random IDs;
    - the Gerbers and drill maps carry timestamps;
    - routed tracks can be written in a different order.

    Compare boards by content, not by diff size.

14. **The files are in KiCad 10 format.** The system Debian KiCad (9.0.2) can't open them, and its Python module is broken. Use the KiCad 10.0.7 AppImage (`~/bin/kicad.AppImage`).

15. **Reload open boards after a build.** `build.sh` rewrites the board files; a board left open in KiCad will write its old version back when saved. `kicad/AC30.kicad_prl` (local view settings) is left uncommitted.

16. **Routing depends on the placement seed.** `build.sh` tries seeds in turn (`AC30_SEEDS`: 31, 32, 34 for the through-hole board; 30, 31, 32 for SMT) until the routing is clean. Changing the parts or the placement code can change which seed works and the whole layout.

17. **Minor:**
    - A leftover AppImage mount process can block new mounts; kill it if `build.sh` stops right after start-up.
    - Commit `1f0a4a8` wrongly says ".history already in .gitignore".
    - The earlier text in `README.md` (TPx pads, the 3.5" × 7" estimate) describes the first version.

---

## Resolved

| Issue | Fix |
|---|---|
| A fresh through-hole build left R35–Q8 unrouted | New placement seed (31); `build.sh` tries other seeds, and finishing passes free the wiring near unrouted ends |
| The early stop for repeated routing results never fired | Compares route summaries instead of board files |
| No ground plane | GND fill on both layers of both boards |
| Motor and relay lines on 0.25 mm tracks | Power class, 0.6 mm tracks (about 1.5 A) |
| FreeRouting 2.1.0 wrote incomplete sessions on the SMT board | FreeRouting 2.4.1 |
| One MIC and one EAR pad group for four jacks | Separate MIC A/B and EAR A/B pads, each with its own GND |
| BOM typos ("S4, SS"; 1N4148 count 9 for ten diodes) | Corrected |

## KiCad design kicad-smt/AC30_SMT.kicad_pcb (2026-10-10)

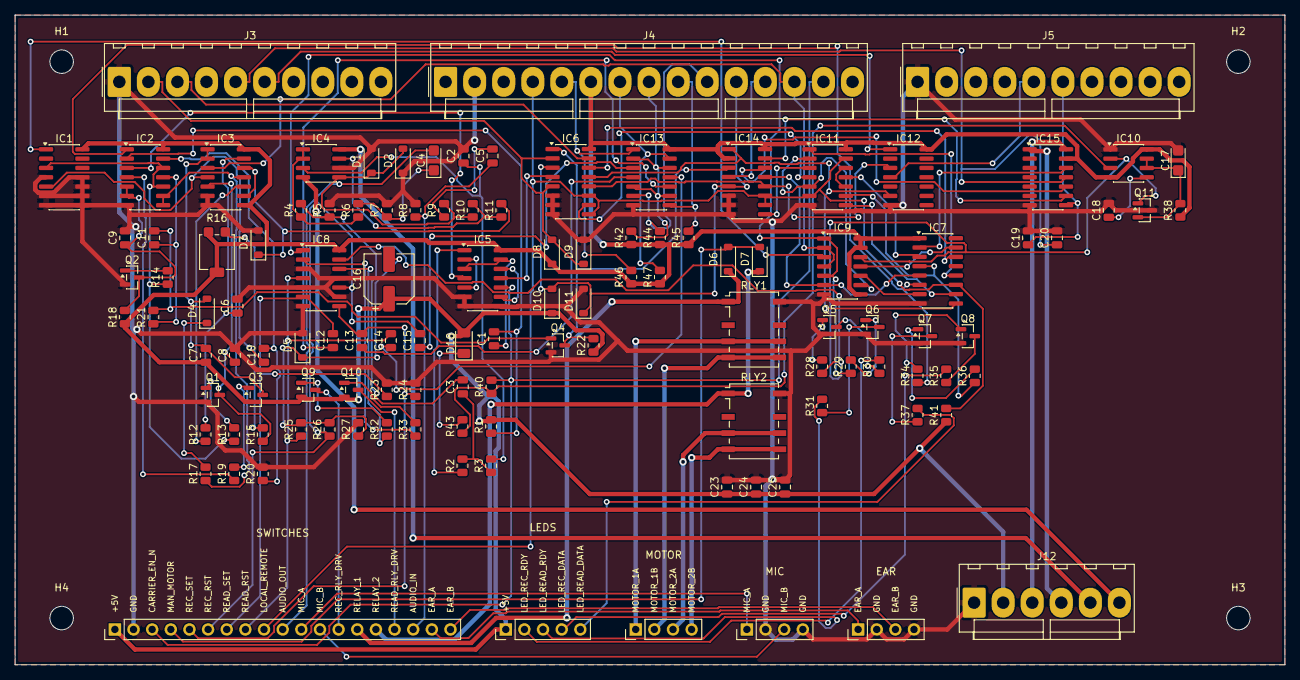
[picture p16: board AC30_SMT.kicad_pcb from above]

Board: 2 copper layers, 173.0 x 88.5 mm, 122 parts (0 on the bottom side), 121 nets.

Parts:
C1, C6, C12, C13, C14, C15: 1000pF; C_0805_2012Metric
C2: 2000pF; C_0805_2012Metric
C3, C8: 0.022uF; C_0805_2012Metric
C4: 1uF 15V; CP_EIA-3216-18_Kemet-A
C5, C18: 0.01uF; C_0805_2012Metric
C7, C9: 0.047uF; C_0805_2012Metric
C10: 2700pF; C_0805_2012Metric
C11, C19, C20: 470pF; C_0805_2012Metric
C16: 100uF 16V; CP_Elec_6.3x7.7
C17: 10uF 10V tant; CP_EIA-3216-18_Kemet-A
C23, C24, C25: 0.1uF; C_0805_2012Metric
D1, D2, D4, D5, D6, D7, D8, D9, D10, D11: 1N4148W; D_SOD-123
D3: BZT52C4V7 4.7V; D_SOD-123
D18: LED; LED_1206_3216Metric
H1, H2, H3, H4: MountingHole; MountingHole_3.2mm_M3
IC1, IC5, IC8: 4013; SOIC-14_3.9x8.7mm_P1.27mm
IC2, IC11: 4001; SOIC-14_3.9x8.7mm_P1.27mm
IC3, IC13: 4070; SOIC-14_3.9x8.7mm_P1.27mm
IC4: 4558; SOIC-8_3.9x4.9mm_P1.27mm
IC6, IC14: 4053; SOIC-16_3.9x9.9mm_P1.27mm
IC7: 4049; SOIC-16_3.9x9.9mm_P1.27mm
IC9: 4023; SOIC-14_3.9x8.7mm_P1.27mm
IC10: 555; SOIC-8_3.9x4.9mm_P1.27mm
IC12: 1489; SOIC-14_3.9x8.7mm_P1.27mm
IC15: 1488; SOIC-14_3.9x8.7mm_P1.27mm
J1: SWITCHES; PinHeader_1x19_P2.54mm_Vertical
J2: LEDS; PinHeader_1x05_P2.54mm_Vertical
J3: Computer interface (COMP); Molex_KK-396_A-41791-0010_1x10_P3.96mm_Vertical
J4: Control interface; Molex_KK-396_A-41791-0015_1x15_P3.96mm_Vertical
J5: Terminal interface (TERM); Molex_KK-396_A-41791-0010_1x10_P3.96mm_Vertical
J12: Power input; Molex_KK-396_A-41791-0006_1x06_P3.96mm_Vertical
J13: MOTOR; PinHeader_1x04_P2.54mm_Vertical
J14: MIC; PinHeader_1x04_P2.54mm_Vertical
J15: EAR; PinHeader_1x04_P2.54mm_Vertical
Q1, Q2, Q4, Q5, Q6, Q7, Q8: MMBT5088; SOT-23
Q3, Q9, Q10, Q11: MMBT5087; SOT-23
R1: 33K; R_0805_2012Metric
R2, R3, R9, R11, R12, R15, R19, R20, R21, R22, R27, R28, R29, R32, R33, R34, R36, R40, R41, R42, R44, R45, R46, R47: 10K; R_0805_2012Metric
R4: 330; R_0805_2012Metric
R5: 2.2K; R_0805_2012Metric
R6: 4.7K; R_0805_2012Metric
R7, R30, R31, R35, R37, R43: 470; R_0805_2012Metric
R8, R17, R18, R23, R24, R25, R26: 100K; R_0805_2012Metric
R10: 330K; R_0805_2012Metric
R13, R14: 22K; R_0805_2012Metric
R16: 20K trim; Potentiometer_Bourns_3314G_Vertical
R38: 47K; R_0805_2012Metric
RLY1, RLY2: G6K-2F-Y 5V; Relay_DPDT_Omron_G6K-2F-Y

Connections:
+5V: C7.1, C16.1, C23.1, C24.1, C25.1, D8.1, D10.1, D18.2, IC1.14, IC2.14, IC3.8, IC3.14, IC5.14, IC6.16, IC7.1, IC8.14, IC9.8, IC9.13, IC9.14, IC10.4, IC10.8, IC11.14, IC12.14, IC13.14, IC14.2, IC14.16, IC15.13, J1.1, J2.1, J4.6, J12.2, Q3.2, Q9.2, Q10.2, R1.2, R16.2, R16.3, R18.1, R22.1, R38.1, R41.1, R42.1, R44.1, R45.1, R46.1, R47.1
+7.5V: IC4.8, J12.5
+13V: IC15.14, J12.3
-7.5V: IC4.4, J12.6
-13V: IC15.1, J12.4
/CPU_CLK_IN: IC6.15, J3.3
/CPU_CLK_OUT: D8.2, D9.1, IC6.2, IC6.5, J3.2
/CPU_DATA: IC6.12, IC12.3, IC14.12
/CPU_RS232_IN: C20.1, IC15.11, J3.5
/CPU_RS232_OUT: IC12.1, J3.6
/CPU_RX: IC7.2, IC15.12
/CPU_RX_N: IC7.3, IC11.11
/CTRL_INVERT: IC13.2, IC13.5, IC13.9, IC13.12, J4.8, R42.2
/D18_K: D18.1, R43.2
/DATA_SEL: IC6.14, IC7.14
/DATA_SEL_N: IC7.15, IC9.11
/DELAY_OUT: IC10.3, R40.1, R43.1
/DELAY_RC: C17.1, IC10.6, IC10.7, Q11.2, R38.2
/EAR_A: J1.18, J15.1
/EAR_B: J1.19, J15.3
/ECHO_N: IC11.10, IC11.12
/IC10_CV: C18.1, IC10.5
/LED_READ_DATA: J2.5, R37.2
/LED_READ_RDY: J2.3, R31.2
/LED_REC_DATA: J2.4, R35.2
/LED_REC_RDY: J2.2, R30.2
/LOCAL_REMOTE: IC6.9, IC6.11, IC7.11, IC11.6, IC11.13, IC14.10, IC14.11, J1.9, J4.4, R41.2
/MAN_MOTOR: D6.2, D7.2, J1.4
/MIC_A: J1.11, J14.1
/MIC_B: J1.12, J14.3
/MOTOR_1A: J13.1, RLY1.3, RLY1.6
/MOTOR_1B: J13.2, RLY1.4, RLY1.5
/MOTOR_2A: J13.3, RLY2.3, RLY2.6
/MOTOR_2B: J13.4, RLY2.4, RLY2.5
/Mod/Demod & power input/DEM_BIT: C10.1, IC1.5, IC3.4
/Mod/Demod & power input/DEM_BIT_EDGE: C10.2, IC2.13, R20.1
/Mod/Demod & power input/DEM_CD: C7.2, D4.2, IC3.1, IC3.2, Q3.3
/Mod/Demod & power input/DEM_CLK_N: C11.1, IC2.11, R21.1
/Mod/Demod & power input/DEM_CMP: IC4.7, R10.2, R11.1
/Mod/Demod & power input/DEM_D4: D4.1, R17.2
/Mod/Demod & power input/DEM_DLY: C6.1, IC3.13, R12.2
/Mod/Demod & power input/DEM_EDGE: IC2.8, IC2.9, IC3.11, R17.1
/Mod/Demod & power input/DEM_HP: C5.2, R9.1
/Mod/Demod & power input/DEM_IN: D1.1, D2.2, IC4.5, R9.2, R10.1
/Mod/Demod & power input/DEM_INV: IC3.10, R12.1
/Mod/Demod & power input/DEM_LIM: D3.1, IC3.9, IC3.12, R11.2
/Mod/Demod & power input/DEM_PULSE: IC1.3, IC2.10, IC2.12, R13.1, R14.1
/Mod/Demod & power input/DEM_Q1B: Q1.1, R13.2
/Mod/Demod & power input/DEM_Q2B: Q2.1, R14.2
/Mod/Demod & power input/DEM_Q2C: C9.1, IC2.5, IC2.6, Q2.3, R18.2
/Mod/Demod & power input/DEM_Q3B: IC2.4, R19.1
/Mod/Demod & power input/DEM_Q3B_R: Q3.1, R19.2
/Mod/Demod & power input/DEM_Q4B: C11.2, Q4.1, R21.2
/Mod/Demod & power input/DEM_R16: R15.2, R16.1
/Mod/Demod & power input/DEM_TIMER: C8.1, IC3.5, Q1.3, R15.1
/Mod/Demod & power input/MOD_ATTEN: C4.1, R6.2, R7.1
/Mod/Demod & power input/MOD_CLK2: C1.1, IC5.3, IC5.13
/Mod/Demod & power input/MOD_DIV2_N: IC5.9, IC5.12
/Mod/Demod & power input/MOD_DIV4_N: IC5.2, IC5.5
/Mod/Demod & power input/MOD_EDGE: C1.2, IC2.2, R1.1
/Mod/Demod & power input/MOD_F1: C3.1, R2.2, R3.1
/Mod/Demod & power input/MOD_F2: C2.1, IC4.3, R3.2
/Mod/Demod & power input/MOD_FB: C3.2, R4.2, R5.1
/Mod/Demod & power input/MOD_FILT: IC4.1, IC4.2, R4.1, R6.1
/Mod/Demod & power input/MOD_RST: IC2.3, IC5.4
/Mod/Demod & power input/MOD_SQ: IC5.1, R2.1
/POR: C16.2, D5.1, R25.2, R26.2, R27.1
/Q5_B: Q5.1, R28.2
/Q5_C: Q5.3, R30.1
/Q6_B: Q6.1, R29.2
/Q6_C: Q6.3, R31.1
/Q7_B: Q7.1, R36.2
/Q7_C: Q7.3, R37.1
/Q8_B: Q8.1, R34.2
/Q8_C: Q8.3, R35.1
/Q9_B: Q9.1, R32.2
/Q10_B: Q10.1, R33.2
/READ_ACTIVE_N: IC9.9, IC11.2, IC11.5
/READ_EN: IC8.1, IC9.1, IC9.5, R29.1
/READ_EN_N: IC8.2, R33.1
/READ_RLY_DRV: J1.16, Q10.3
/READ_RST: C14.2, IC8.4, J1.8, R25.1
/READ_SET: C12.2, IC8.6, J1.7, R23.1
/REC_DATA_N: IC7.7, IC9.10
/REC_EN: IC8.13, IC9.12, IC10.2, Q11.1, R28.1
/REC_EN_N: IC8.12, R32.1
/REC_RLY_DRV: J1.13, Q9.3
/REC_RST: C15.2, IC8.10, J1.6, R26.1
/REC_SET: C13.2, IC8.8, J1.5, R24.1
/RELAY_1: D6.1, J1.14, RLY1.1
/RELAY_2: D7.1, J1.15, RLY2.1
/REMOTE_N: IC7.12, IC11.1
/SEL_CPU_CLK: IC6.10, IC11.4
/SEL_TERM_CLK: IC11.3, IC14.9
/START_READ: IC13.8, J4.9, R45.2
/START_READ_P: C12.1, IC13.10
/START_RECORD: IC13.6, J4.10, R44.2
/START_REC_P: C13.1, IC13.4
/STOP_READ: IC13.13, J4.7, R47.2
/STOP_READ_P: C14.1, IC13.11
/STOP_RECORD: IC13.1, J4.5, R46.2
/STOP_REC_P: C15.1, IC13.3
/TAPE_DATA: IC7.4, IC11.9, R36.1
/TAPE_DATA_N: IC7.5, IC9.6, IC14.13
/TERM_CLK_IN: IC14.4, J4.12
/TERM_CLK_OUT: D10.2, D11.1, IC6.3, IC14.5, J4.11
/TERM_DATA: IC6.13, IC7.9, IC12.6, IC14.1
/TERM_DATA_N: IC7.10, IC11.8
/TERM_ECHO: IC14.15, IC15.9
/TERM_RS232_IN: C19.1, IC15.8, J5.6
/TERM_RS232_OUT: IC12.4, J5.5
/TERM_TX_SEL: IC14.14, IC15.10
AUDIO_IN: C5.1, J1.17, R8.1
AUDIO_OUT: C4.2, J1.10
CARRIER_DETECT: IC3.3, IC9.2, IC9.4, J4.13
CARRIER_EN_N: IC5.10, J1.3, J4.14, R40.2
CLOCK_IN: IC5.11, IC6.4
CLOCK_OUT: IC6.1, IC14.3, Q4.3, R22.2
DATA_IN: IC2.1, IC7.6, R34.1
DATA_OUT: IC1.1, IC9.3
GND: C2.2, C6.2, C8.2, C9.2, C17.2, C18.2, C19.2, C20.2, C23.2, C24.2, C25.2, D1.2, D2.1, D3.2, D5.2, D9.2, D11.2, IC1.4, IC1.6, IC1.7, IC1.8, IC1.9, IC1.10, IC1.11, IC2.7, IC3.6, IC3.7, IC4.6, IC5.6, IC5.7, IC5.8, IC6.6, IC6.7, IC6.8, IC7.8, IC8.3, IC8.5, IC8.7, IC8.9, IC8.11, IC9.7, IC10.1, IC11.7, IC12.7, IC13.7, IC14.6, IC14.7, IC14.8, IC15.7, J1.2, J3.1, J4.2, J5.1, J12.1, J14.2, J14.4, J15.2, J15.4, Q1.2, Q2.2, Q4.2, Q5.2, Q6.2, Q7.2, Q8.2, Q11.3, R5.2, R7.2, R8.2, R20.2, R23.2, R24.2, R27.2, RLY1.8, RLY2.8

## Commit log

2026-10-09 Adds final first run of Claude/Kicad/FreeCAD for a modern AC30
2026-10-09 Messing around with a repo in a repo
    [AC30.kicad_pcb, AC30.kicad_sch, AC30.step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]
2026-10-09 Keeps copies in the AC30-Kicad dir
    [AC30.kicad_pcb, AC30.kicad_sch, AC30.step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]
2026-10-09 Adds more info on the size of the original and new board
2026-10-09 Wire mod/demod and external power supply; retry routing until DRC-clean
    - Transcribe docs/ac30_mod_demod.pdf onto sheet 2: modulator (IC5A/B,
    IC2A, IC4A filter) and demodulator (IC4B comparator, IC3C/D edge pulses,
    carrier detect, missing-pulse detector, R16 timer, IC1A data out, 16X
    clock out). The mod/demod interface solder pads are removed.
    - Transcribe docs/ac30_PS.pdf onto new sheet 3 as an external unit (no
    footprints): line cord, S6, F1, T1, bridge D14-D17, +/-13 V, +/-7.5 V
    zener rails, 7805. IC16 GND taken as GND (drawing ties it to -13 V).
    - Board gets through-hole power input pads TP1-TP6 (+5V, GND, +13V, -13V,
    +7.5V, -7.5V) with rail names on the silkscreen, plus C23-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
    [AC30.kicad_pcb, AC30.kicad_sch, AC30.step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]
2026-10-09 Replace power input pads with J12, a 6-pin KK-396 header on the bottom edge
    - J12 (Molex KK-396 A-41791-0006) replaces solder pads TP1-TP6 for the
    external supply: 1 GND, 2 +5V, 3 +13V, 4 -13V, 5 +7.5V, 6 -7.5V.
    Placed in the bottom connector row next to J2, clear of the corner hole.
    - build.sh: if no routing attempt is DRC-clean, up to 3 finishing passes
    route only what is left on the best result, each checked by DRC.
    - Board 173.5 x 122.0 mm, fully routed; ERC, DRC (all severities) and
    schematic parity clean. AC30-settings.md updated (power input, drill
    table, routing, positions).
    [AC30.kicad_pcb, AC30.kicad_sch, AC30.step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]
2026-10-09 Update session log; BOM edits, BOM CSV, AC30_byte.pdf, KiCad local state
    - AC30-Claude.md: sections 4-29 (PCB, AppImage build, routing, settings,
    mounting holes, mod/demod, external power supply, J12), end-of-session
    state table, appendix nets updated to final connector pins.
    - docs/AC30-BOM.md edits, new docs/AC30-BOM.csv and docs/AC30_byte.pdf.
    - kicad/AC30.kicad_prl (layer visibility) and kicad/.history pointer.
    [AC30-BOM.csv]
2026-10-09 Stop tracking kicad/.history (KiCad local history, already in .gitignore)
2026-10-09 Add .gitignore for KiCad local history, lock and autosave files
2026-10-09 Add SMT variant of the schematic and PCB (kicad-smt/AC30_SMT)
    - tools/build.sh smt builds kicad-smt/AC30_SMT.*; the through-hole project
    in kicad/ is unchanged. netlist.py AC30_VARIANT=smt: 0805 R/C, SOD-123
    diodes (1N4148W, BZT52C4V7), SOT-23 transistors (MMBT5088/MMBT5087, BEC
    symbols), SOIC ICs, EIA-3216 tantalums, 6.3x7.7 C16, Bourns 3314G R16,
    1206 LED, Omron G6K-2F-Y relays (both poles in parallel). Molex KK-396
    connectors and mounting holes stay through-hole.
    - Routing: switch to FreeRouting 2.4.1 (bundled Java 25). 2.1.0 reported
    dense SMT boards complete but wrote sessions with segments missing.
    route.py: stub cleanup keeps T-junctions; finishing rounds protect the
    e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
    [AC30_SMT.kicad_pcb, AC30_SMT.kicad_sch, AC30_SMT.step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]
2026-10-09 Add AC30-SMT-settings.md for the SMT board
2026-10-10 Adds various Kicad SMT files
    [AC30_SMT.kicad_sch]
2026-10-10 SMT board: through-hole jumper pads for the front panel
    Replace the J1/J2 KK-396 front-panel harness headers on the SMT board with
    five rows of 0.1 in through-hole wire pads along the bottom edge, each pad
    labelled with its net name on the silkscreen:
    J1 SWITCHES, J2 LEDS, J13 MOTOR, J14 MIC (AUDIO_OUT), J15 EAR (AUDIO_IN).
    The through-hole board keeps J1/J2. SMT board is now 173.0 x 89.0 mm;
    ERC, DRC (all severities) and parity clean, fully routed.
    AC30-SMT-settings.md updated.
    [AC30_SMT.kicad_pcb, AC30_SMT.kicad_sch, AC30_SMT.step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]
2026-10-10 SMT board: separate MIC A/B and EAR A/B jumper pads
    Each front-panel jack now has its own tip and GND pads (J14 MIC: MIC_A,
    GND, MIC_B, GND; J15 EAR: EAR_A, GND, EAR_B, GND). The S2/S3 audio poles
    wire to new SWITCHES pads (AUDIO_OUT, MIC_A/B, AUDIO_IN, EAR_A/B) and the
    board joins them. SMT board is now 173.0 x 88.5 mm; ERC, DRC (all
    severities) and parity clean, fully routed. AC30-SMT-settings.md updated.
    [AC30_SMT.kicad_pcb, AC30_SMT.kicad_sch, AC30_SMT.step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]
2026-10-10 Through-hole board: front-panel jumper pads in place of J1/J2
    Both boards now wire the front panel to five rows of 0.1 in through-hole
    pads with net names on the silkscreen (J1 SWITCHES, J2 LEDS, J13 MOTOR,
    J14 MIC, J15 EAR) instead of the artwork's J1/J2 KK-396 headers.
    The through-hole build weights board height at 60 (AC30_HEIGHT_W) so the
    bottom row doesn't stretch the board; it is now 173.0 x 126.5 mm, fully
    routed, ERC/DRC/parity clean. SMT board unchanged apart from symbol IDs
    and the schematic note. AC30-settings.md updated.
    [AC30.kicad_pcb, AC30.kicad_sch, AC30.step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]
2026-10-10 Update documentation and BOMs for both boards
    - build.sh exports <project>-BOM.csv from each schematic on every build:
    kicad/AC30-BOM.csv and kicad-smt/AC30_SMT-BOM.csv
    - docs/AC30-BOM.md/.csv: reproduction board parts (KK-396 headers, front
    panel wire pads, jacks, C23-C25, mounting hardware) and SMT substitutions
    - README note for the wire pads; session log sections 38-47
    [AC30-BOM.csv, AC30_SMT-BOM.csv]
2026-10-10 Fix BOM typos: S4, S5 and 1N4148 diode count (10)
    [AC30-BOM.csv]
2026-10-10 Add Gerbers and drill files for both boards
    tools/gerbers.sh writes Gerbers (X2, Protel extensions, job file),
    Excellon drill files (PTH/NPTH, mm) with maps and a report into
    <project dir>/gerbers/ and zips them as <project>-gerbers.zip; build.sh
    runs it at the end of every build. The SMT set adds the top paste layer.
    Settings docs describe the fabrication files.
    [AC30-B_Cu.gbl, AC30-B_Mask.gbs, AC30-B_Silkscreen.gbo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]
2026-10-10 README: board sizes and Gerber files
2026-10-10 Add the SMT pick-and-place position file
    - kicad-smt/AC30_SMT-top-pos.csv: 109 SMD parts, mm, from the board's
    bottom-left corner (Y up); written by tools/gerbers.sh for the SMT board
    - pcb.py sets the drill/place origin at the bottom-left corner of both
    boards; Gerbers regenerated (same geometry, absolute coordinates)
    - Settings docs describe the position file and the origin
    [AC30-B_Cu.gbl, AC30-B_Mask.gbs, AC30-B_Silkscreen.gbo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]
2026-10-10 Make the through-hole build route completely
    The seed-30 placement boxed in Q8's collector, so R35-Q8 could not be
    routed from scratch. Fixes:
    - pcb.py: placement seed from AC30_SEED; build.sh tries seeds in turn
    (AC30_SEEDS; 31 32 34 through-hole, 30 31 32 SMT) until routing is clean
    - route.py: finishing passes protect existing wiring except within
    ROUTE_FREE_RADIUS (5, 10, 20 mm) of the unrouted ends taken from DRC;
    a pass is kept when it reduces the unrouted count
    - build.sh: early stop compares route summaries (track IDs are random);
    KiCad debug noise filtered
    Through-hole board rebuilt with seed 31: 173.0 x 126.5 mm, routed on the
    first attempt, ERC/DRC/parity clean. SMT board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
    [AC30-B_Cu.gbl, AC30-B_Mask.gbs, AC30-B_Silkscreen.gbo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]
2026-10-10 README: SMT position file, through-hole re-placement, known issues
2026-10-10 Add a GND copper fill to both boards
    tools/zones.py adds a GND zone on F.Cu and B.Cu over the whole outline
    (0.3 mm clearance, 0.25 mm min width, 0.5/0.5 mm thermal reliefs, islands
    removed); build.sh fills it with kicad-cli after routing. GND pads whose
    thermal relief is starved get a solid connection, refilling until none is
    left (11 pads through-hole, 2 SMT). FILL=0 builds without it.
    Both boards ERC/DRC (all severities)/parity clean; Gerbers regenerated;
    settings docs and README updated.
    [AC30-B_Cu.gbl, AC30-B_Mask.gbs, AC30-B_Silkscreen.gbo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]
2026-10-10 README: GND copper fill details
2026-10-10 Motor and relay nets in the Power netclass
    MOTOR_1A/1B/2A/2B and RELAY_1/2 now route as 0.6 mm tracks with 1.0/0.5 mm
    vias (POWER_CLASS in pcb.py; placement unchanged). Both boards rebuilt:
    routed on the first attempt, GND fill, ERC/DRC (all severities)/parity
    clean. Gerbers regenerated; settings docs updated.
    [AC30-B_Cu.gbl, AC30-B_Mask.gbs, AC30-B_Silkscreen.gbo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]
2026-10-10 README: motor and relay lines on 0.6 mm tracks
2026-10-11 Wired, human-readable schematics with PDF and PNG images
    gen.py now lays out each functional group on its own and draws its nets
    as real wires (new tools/schroute.py: orthogonal grid router that never
    ends, bends or overlaps on another net's wire); every routed net keeps
    one label with its name, labels join nets between blocks and sheets, and
    unroutable connections fall back to label pairs (17). The front-panel
    jumper pads share the front-panel block. Custom 1488/1489 output pins
    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
2026-10-11 README: wired schematics note with a block image
2026-10-12 Adds Claude's SMT schematic pdf
